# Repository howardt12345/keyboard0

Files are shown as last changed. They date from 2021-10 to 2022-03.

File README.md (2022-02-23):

# [keyboard0 project](https://kb.ht12345.xyz/0)
[][cc-by-nc-sa]

## This project is currently under active development. Everything is subject to change.

### Tenkeyless (TKL) hot-swap mechanical keyboard with macro keys column, 2 rotary encoders, and OLED display

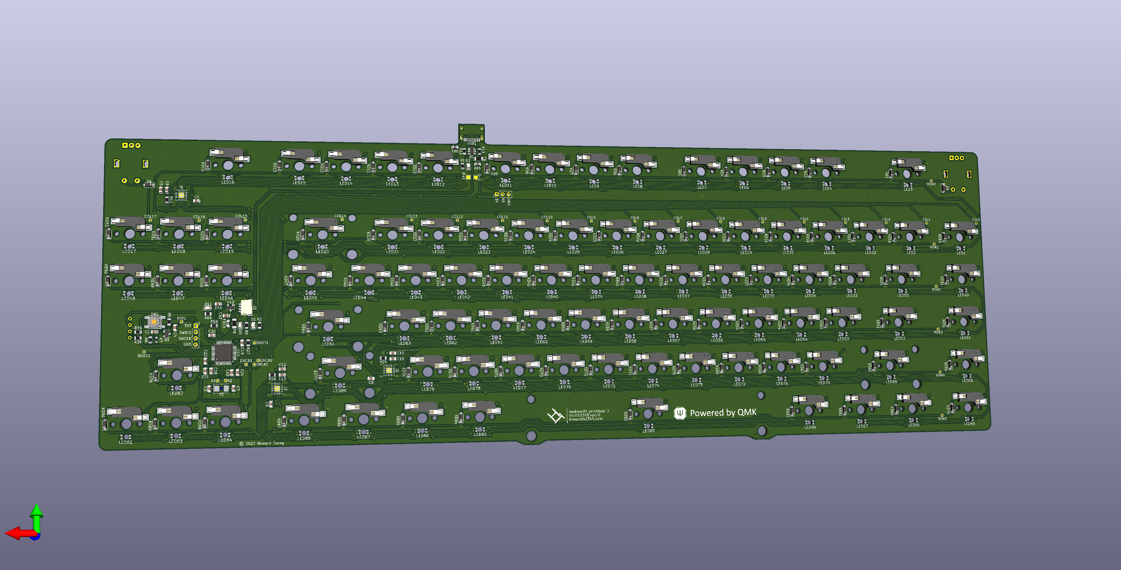
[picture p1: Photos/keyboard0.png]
Render of p2 PCB


The PCB is designed to use Kailh Hot-swap sockets. The original specifications also wanted a USB hub, which will be implemented through a separate USB hub daughterboard. 

---

[The layout on keyboard layout editor](http://www.keyboard-layout-editor.com/#/gists/689bc560553c37fa0d04dfba9f11ed96)

[Prototype 2 PCB photos on @howardt12345](https://www.instagram.com/p/CYXeXJdg_eP/)

[Details on my keyboard website](https://kb.ht12345.xyz/0)

[QMK Fork](https://github.com/howardt12345/qmk_firmware/tree/ht12345/keyboard0/keyboards/ht12345/keyboard0)

---
## All of the files in this repository, including the PCBs, are provided without liability and without any guarantee with regards to functionality. Any production files and prototypes from this project are provided without warranty of any kind.

---

**This work is licensed under a** [Creative Commons Attribution-NonCommercial-ShareAlike 4.0 International License][cc-by-nc-sa].

[][cc-by-nc-sa]

[cc-by-nc-sa]: http://creativecommons.org/licenses/by-nc-sa/4.0/
[cc-by-nc-sa-image]: https://licensebuttons.net/l/by-nc-sa/4.0/88x31.png
[cc-by-nc-sa-shield]: https://img.shields.io/badge/License-CC%20BY--NC--SA%204.0-lightgrey.svg

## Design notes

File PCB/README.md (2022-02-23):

# keyboard0 PCB designs

## Directories: 

- `/p1`: The 1st prototype, ordered prototypes confirmed NOT working.
- `/p2`: The 2nd prototype, which I produced a batch of 2 prototypes and they worked (see respective readme)
- `/p3`: The 3rd prototype, under active development and NOT YET TESTED.
- `/Plate`: FR4 plate designs.

Any KiCad files in *this specific directory* is under active development and is subject to change. 

### These PCB designs are provided without liability and without any guarantee with regards to functionality. While I have personally tested some of the designs, I do not guarantee that they will work if you were to produce them yourself.

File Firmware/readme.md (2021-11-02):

# keyboard0 firmware
keyboard0

A tenkeyless keyboard with 5 additional macro keys, RGB lighting, 2 rotary encoders, and up to 6 additional USB 2.0 ports.
* Keyboard Maintainer: [Howard Tseng](https://github.com/howardt12345)
* Hardware Supported: keyboard0 (STM32F103)
* Hardware Availability: Not available

Make example for this keyboard (after setting up your build environment):

    make keyboard0:default

Flashing example for this keyboard:

    make keyboard0:default:flash

See the [build environment setup](https://docs.qmk.fm/#/getting_started_build_tools) and the [make instructions](https://docs.qmk.fm/#/getting_started_make_guide) for more information. Brand new to QMK? Start with our [Complete Newbs Guide](https://docs.qmk.fm/#/newbs).

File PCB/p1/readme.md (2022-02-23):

# 1st prototype of keyboard0
## This prototype has confirmed to NOT BE WORKING. Do NOT use the files in this directory and subdirectories for production or reference.

`custom_keyboard (f303).pro` is the project that was exported for production. This KiCad project was made using KiCad 5.1.10.

## Known issues:
- Rotary encoders are off centered
- OLED pins are flipped
- Circuit breaker IC was incorrectly wired and as such does not work
- USB hub does not work

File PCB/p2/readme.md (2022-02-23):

# 2nd prototype of keyboard0

I have *personally* confirmed this prototype version to be working. 

`custom_keyboard (f303).pro` is the project that was exported for production. This KiCad project was made using KiCad 5.1.10.

---
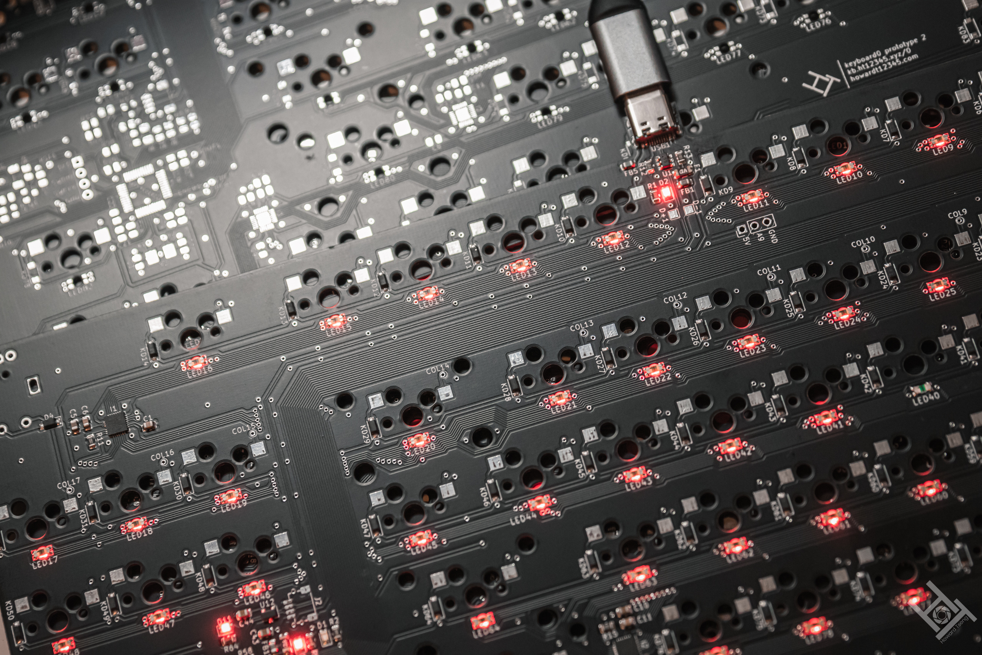
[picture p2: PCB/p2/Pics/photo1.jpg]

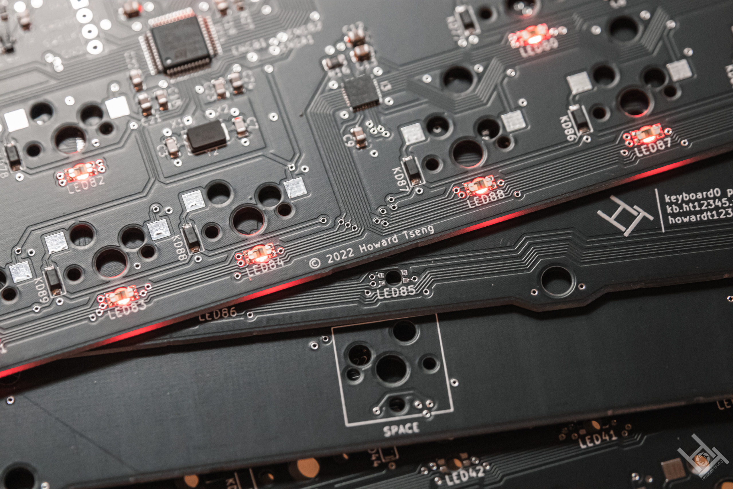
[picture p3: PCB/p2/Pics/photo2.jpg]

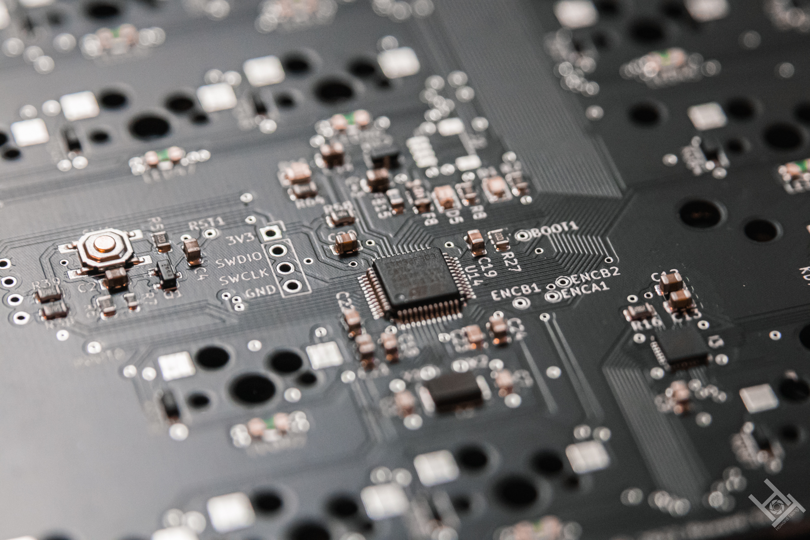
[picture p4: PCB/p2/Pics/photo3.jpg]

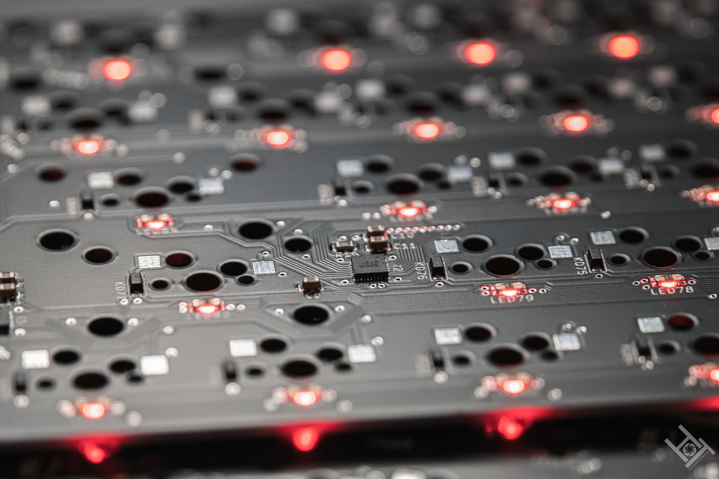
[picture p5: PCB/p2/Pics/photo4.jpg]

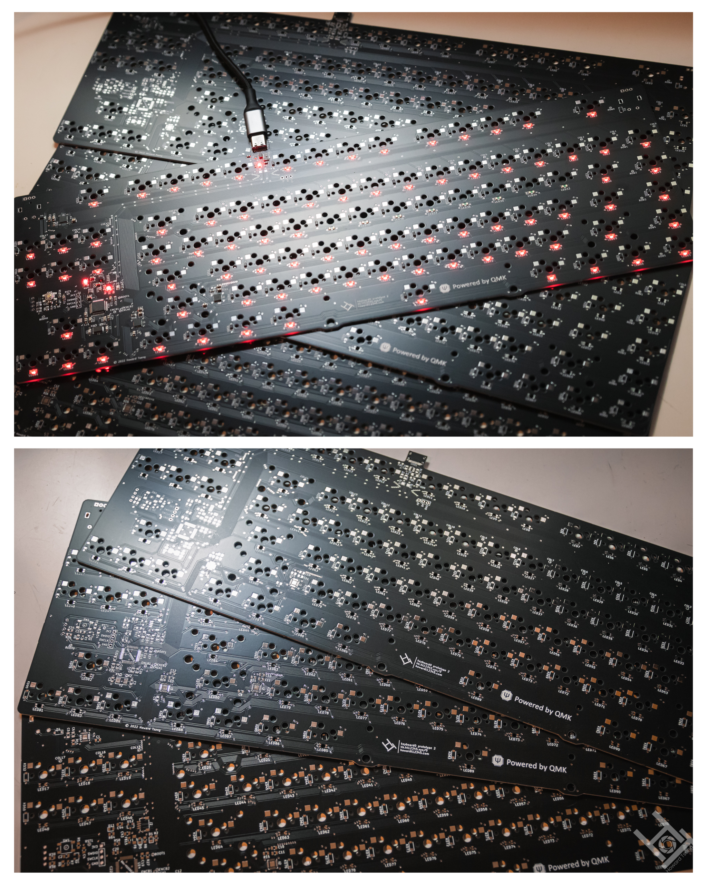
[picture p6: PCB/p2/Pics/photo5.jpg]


---

# Notable flaws:
- The footprint for the MHT151RGBCT RGB LEDs will consistently give a DRC error in Kicad. The current footprint follows the specifications found in the [datasheet](https://datasheet.lcsc.com/lcsc/2104121904_MEIHUA-MHT151RGBCT_C409782.pdf), which creates several points where pads are considered to be too close to other pads. Although there are no noticeable issues with the functionality of the LEDs with my personal prototype units, manufacturing errors have a potential to appear, whether in the PCB production process or the assembly process. 
- Vias are not tented in the given Gerber files. Although intended for debugging purposes, it would not be great in production.
- The IS31FL3731 is not the best LED driver, and the RGB LEDs will flicker after a while on one of the units. Switching to a IS31FL3733 in future versions would be ideal, if it becomes available.
- This prototype has both an integrated USB-C port and provisions for a JST connection for a daughterboard. The integrated USB-C port would ideally be removed in future versions, opting to use only a daughterboard as the USB connection. 
- The spacebar stabilizer is south facing to maintain compatibility with the v1 plate. As such, the bottom of the PCB requires slightly more room to accommodate the stabilizer. The stabilizer orientation would be rotated in future versions.
- The USB lines have test points, which are unnecessary and should be removed.

---

## These files are provided without liability and without any guarantee with regards to functionality. These files are NOT to be used for commercial purposes, as expressed in the [Creative Commons Attribution-NonCommercial-ShareAlike 4.0 International License][cc-by-nc-sa].

[cc-by-nc-sa]: http://creativecommons.org/licenses/by-nc-sa/4.0/

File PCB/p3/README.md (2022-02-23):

# 3rd prototype of keyboard0

Still under active development.

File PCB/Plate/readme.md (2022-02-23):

# keyboard0 plates

The project files for the plate of keyboard0.

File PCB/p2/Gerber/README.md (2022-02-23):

# Gerber files for p2

The BOM and SMT placement file (CPL) are formatted for use with JLCPCB. All the parts can be populated by JLCPCB at the time of writing, however the availability of parts depends on external factors.

## JLCPCB Configuration

If you want to order PCBs from JLC-PCB with the provided gerber-files, use the following settings after uploading the zipped gerber folder:

- Layers: 2
- Dimension: 377.8 mm x 135.7 mm
- PCB Color: Choose what you want
- PCB Thickness: 1.6
- Impedance: no
- Surface Finish: LeadFree HASL-RoHS (although up to you)
- Copper Weight: 1
- Gold Fingers: No
- Material Details: FR4-Standard Tg 130-140C
- Panel By JLCPCB: No
- Flying Probe Test: Fully Test
- Castellated Holes: no
- Different Design: 1
- Remove Order Number: Specify a location

5 PCBs without assembly cost is about $36 CAD.

If you want to have the SMT parts populated, choose "SMT Assembly" and select "Bottom Layer".
When asked for the BOM and CPL file, upload the provided files.

Assembly and parts for 5 PCBs will cost approximately $250 CAD.

### Expected Corrected SMD preview from JLCPCB

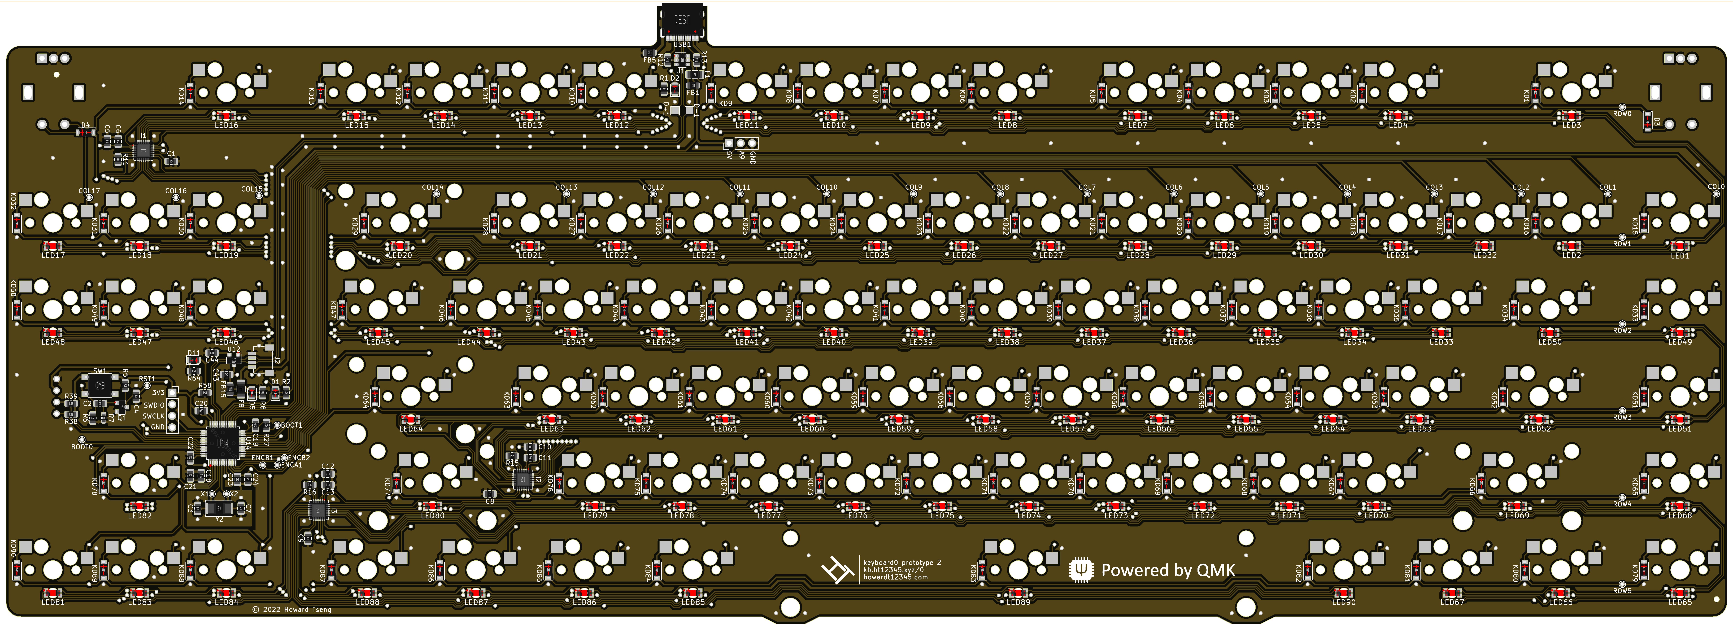
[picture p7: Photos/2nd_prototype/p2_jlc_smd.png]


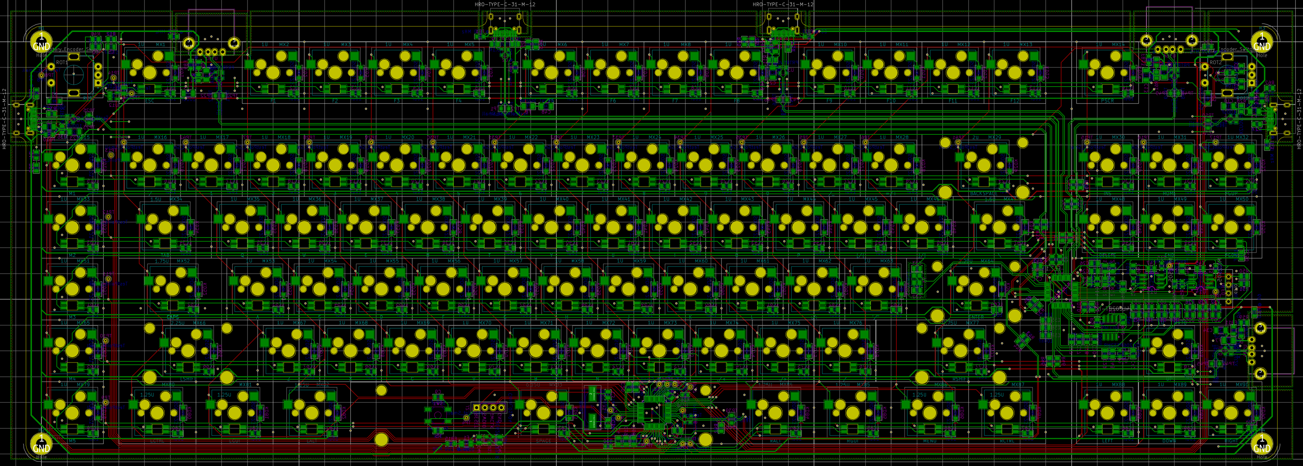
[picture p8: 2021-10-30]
PCB/Gerber/Draft 1-3/Images/2021-10-26/custom_keyboard (f303, fe2.1) bottom traces.png

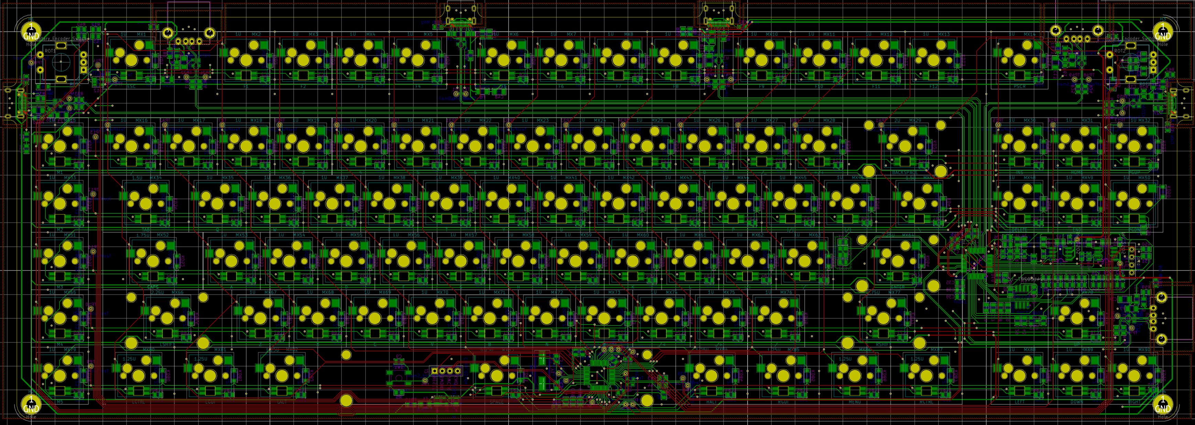
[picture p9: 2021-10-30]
PCB/Gerber/Draft 1-4/Images/2021-10-29/custom_keyboard (f103, fe2.1) top traces.png

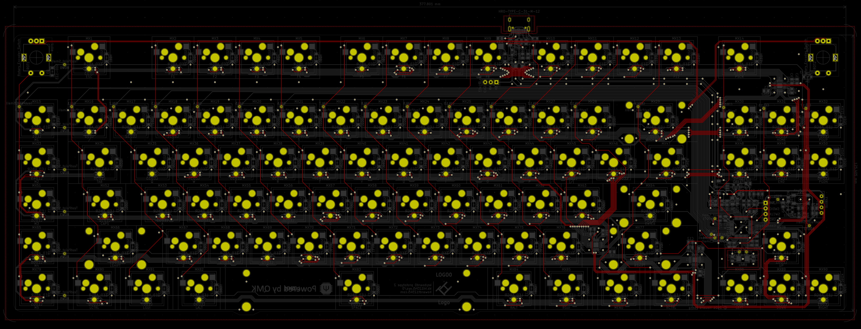
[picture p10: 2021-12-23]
PCB/p2/Pics/custom_keyboard high contrast top.png

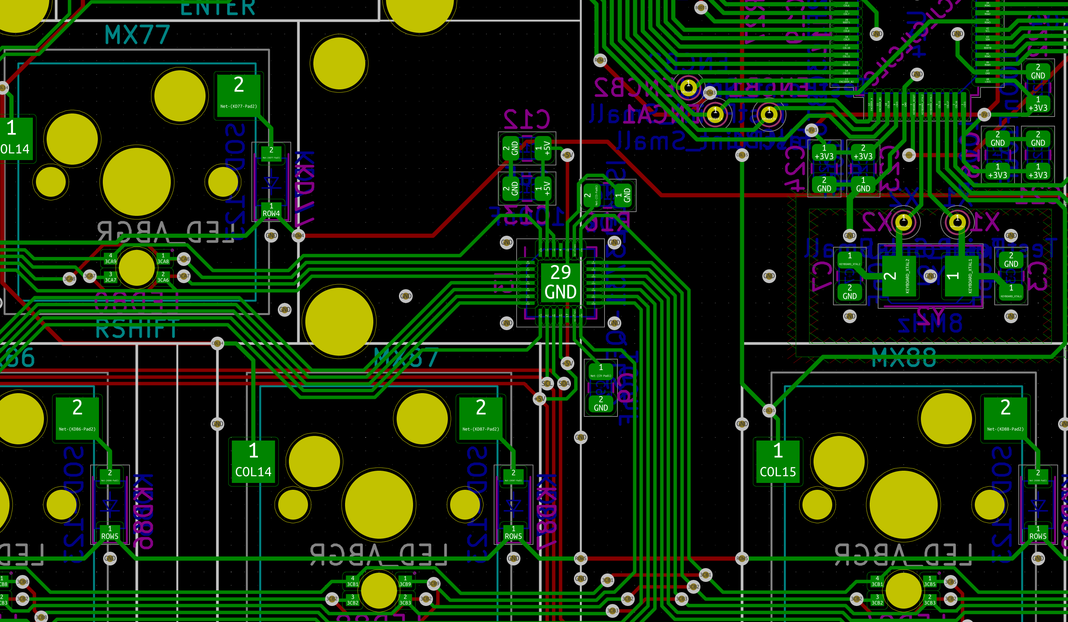
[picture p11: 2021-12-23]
PCB/p2/Pics/custom_keyboard I3.png

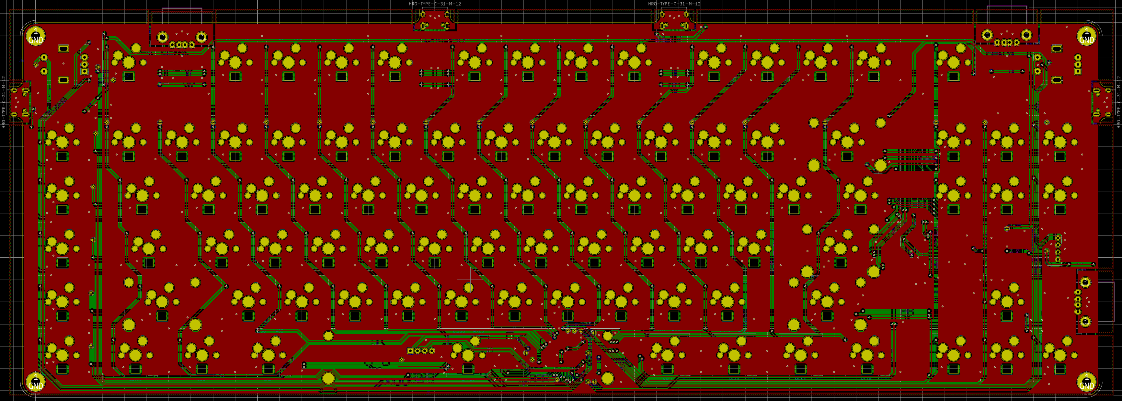
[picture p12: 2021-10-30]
PCB/Gerber/Draft 1-3/Images/2021-10-26/custom_keyboard (f303, fe2.1) top fill.png

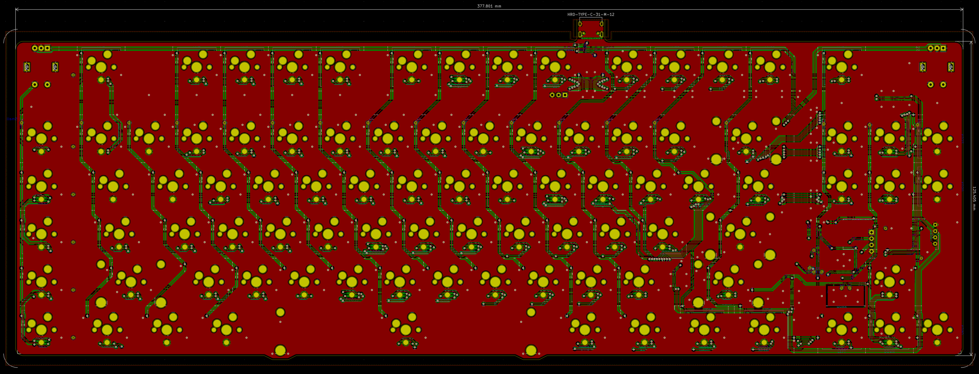
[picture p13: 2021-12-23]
PCB/p2/Pics/custom_keyboard fill top.png

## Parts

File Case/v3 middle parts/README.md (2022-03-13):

# Middle parts of v3 case

The middle parts of the "v3" case. Designed to be used with the [plate v3](../../PCB/Plate/v3) files.

## Renders:

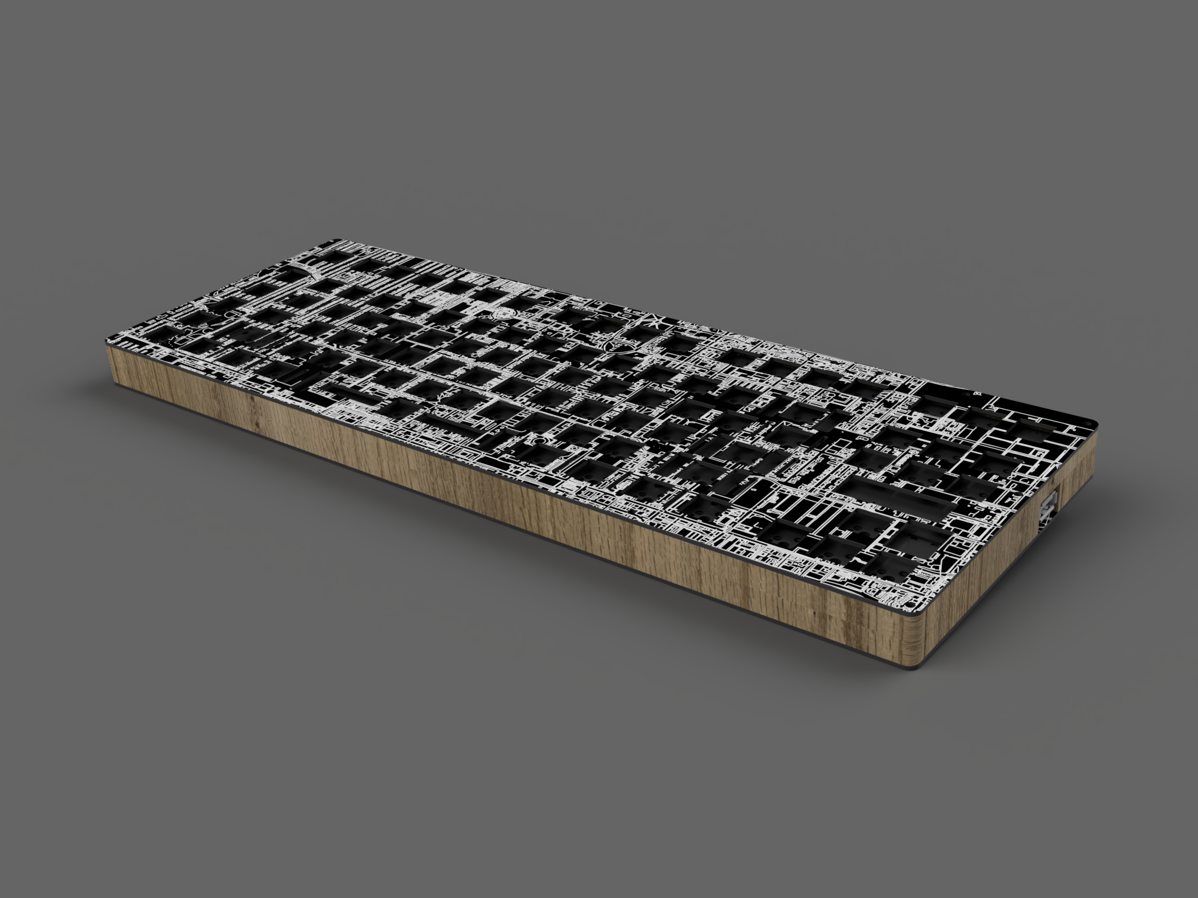
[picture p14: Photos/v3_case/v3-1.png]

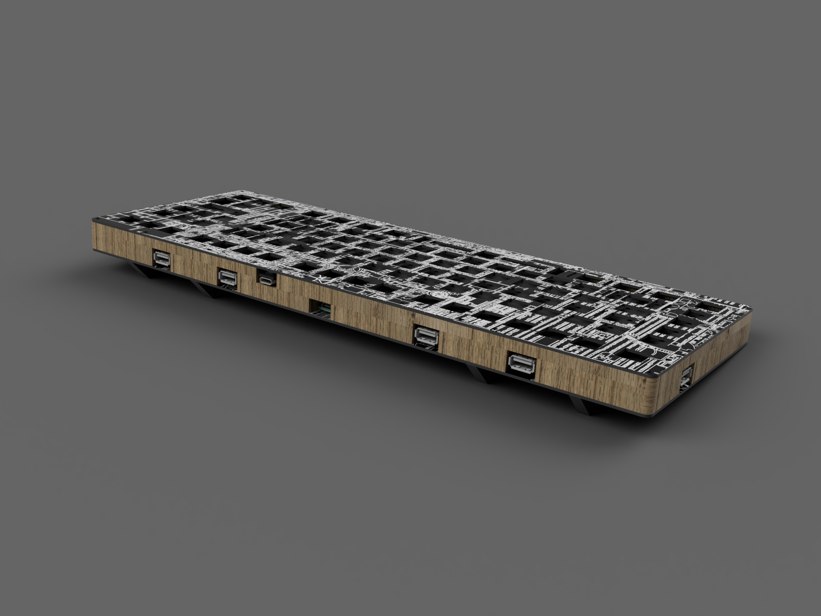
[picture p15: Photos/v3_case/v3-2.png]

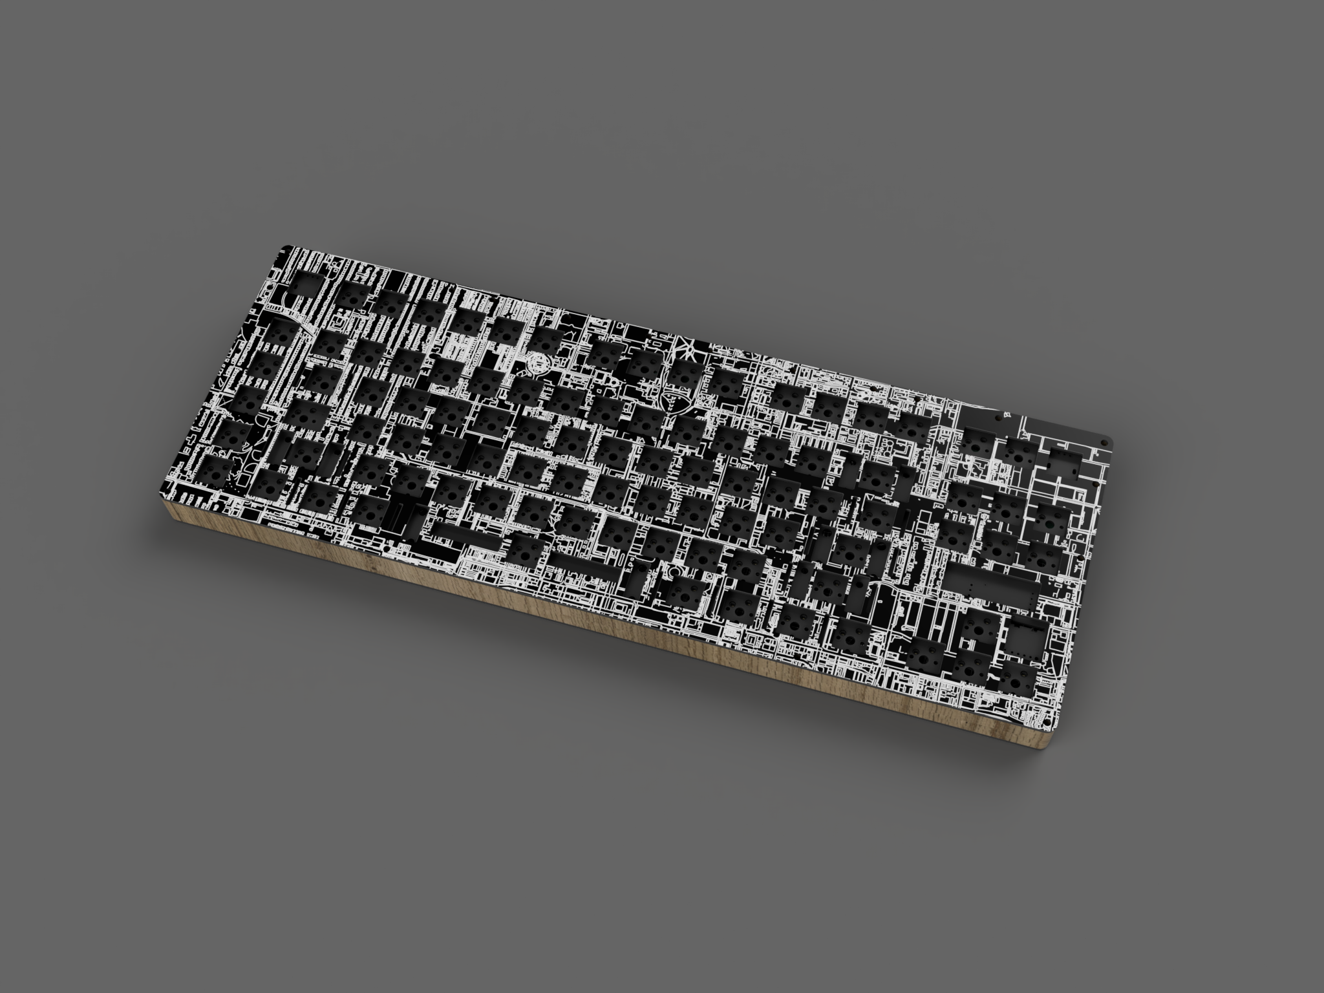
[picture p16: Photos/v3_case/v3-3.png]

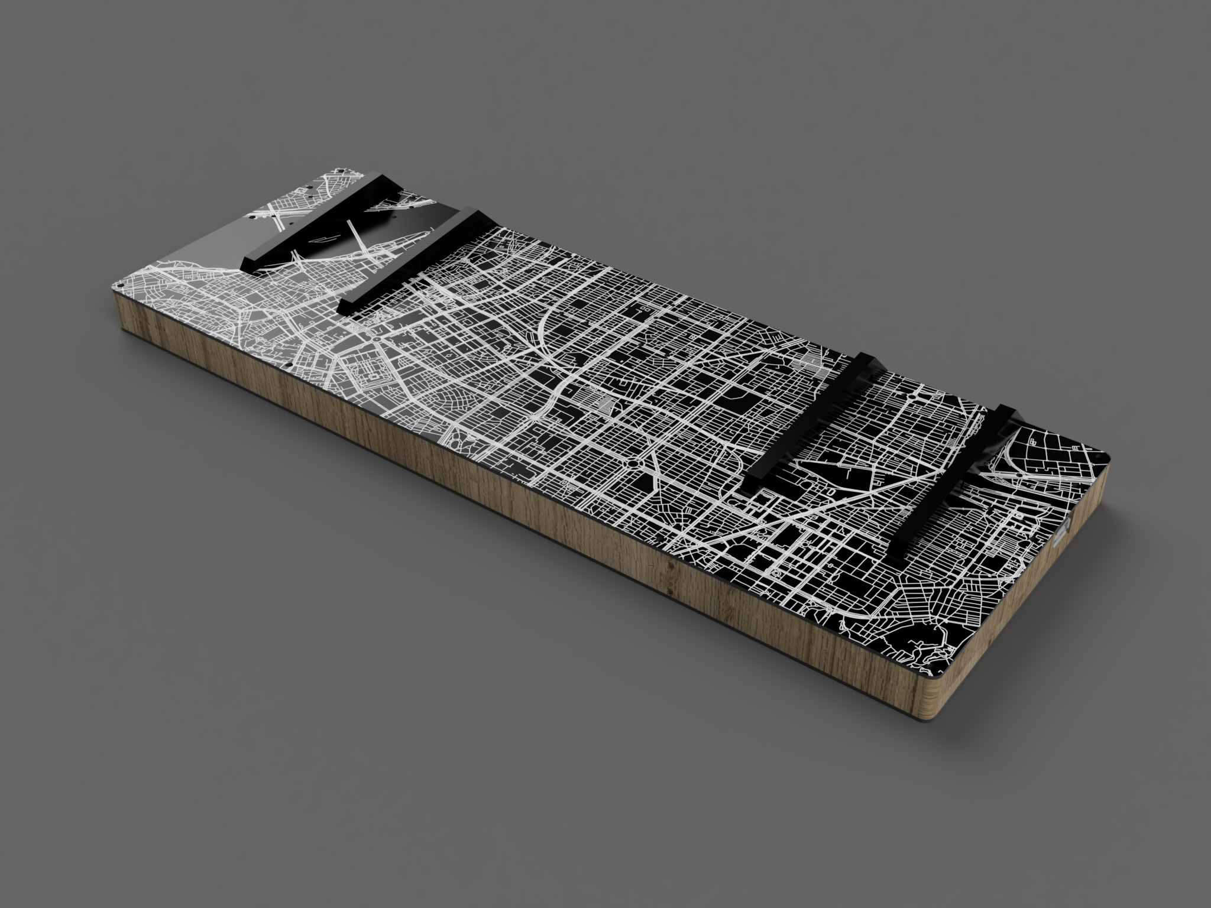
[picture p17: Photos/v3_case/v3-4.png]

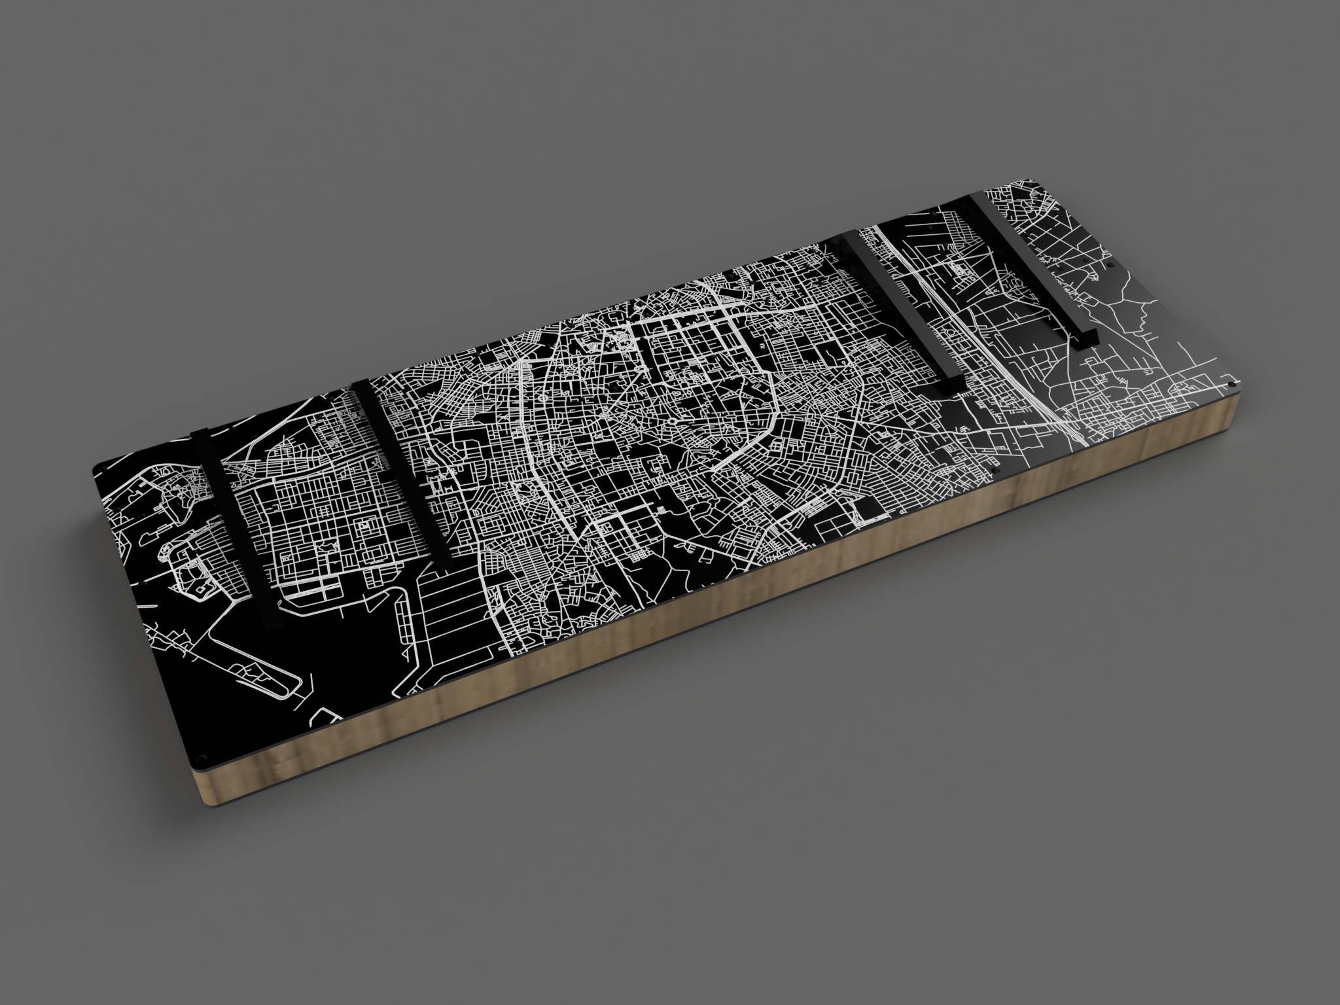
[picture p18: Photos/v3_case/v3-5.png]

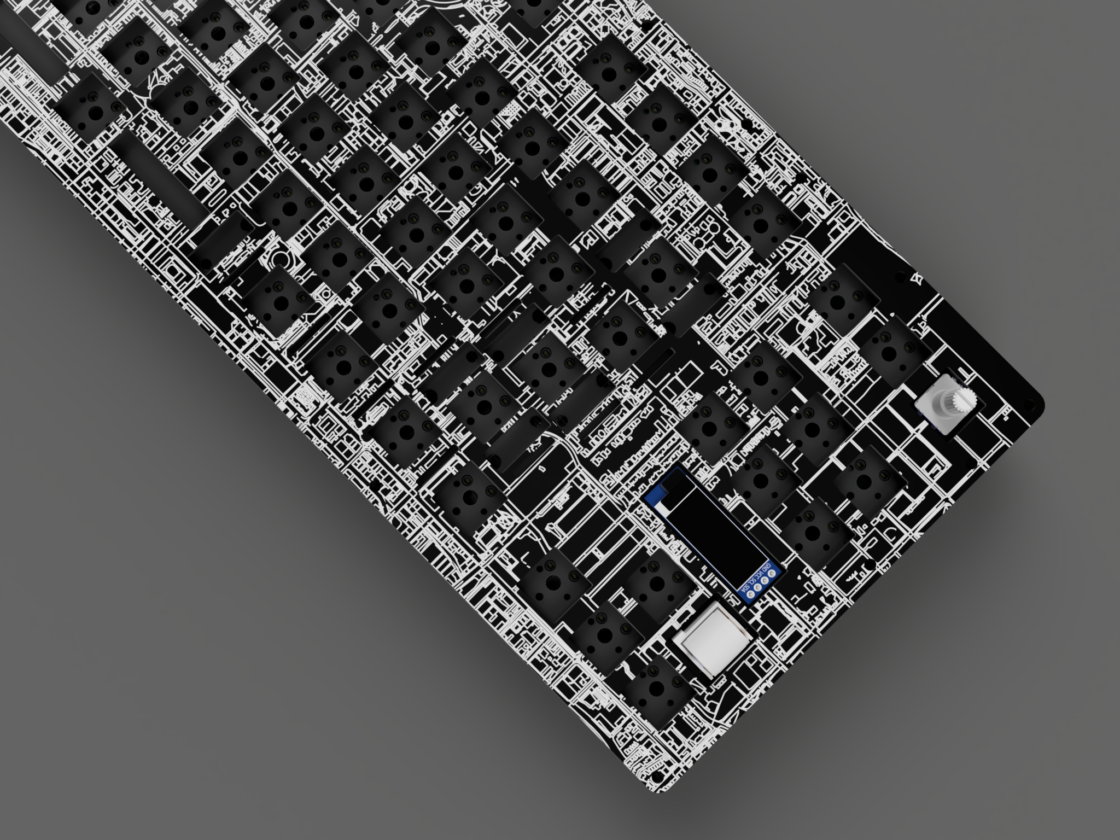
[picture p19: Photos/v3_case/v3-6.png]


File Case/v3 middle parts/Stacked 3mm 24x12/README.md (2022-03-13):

# Stacked case files

These files are for the stacked case variant.
- `Layers 1-4 combined.dxf` and `Layers 5-6 combined.dxf` are both designed to fit on a 3mm 24" x 12" sheet of material of your choice (preferably acrylic). These 2 files contain everything needed for the 6 layers, combined with shared edges between the different parts.
- `Layers 1-3.dxf`, `Layer 4.dxf`, and `Layers 5-6.dxf` are for the individual layers. 
  - `Layers 1-3.dxf` should be produced with 9mm worth of material. Thickness variance within ±1mm is allowed.
  - `Layer 4.dxf` should be produced with 3mm worth of material.
  - `Layers 5-6.dxf` should be produced with 6mm worth of material. No variance in thickness is allowed.

## Diagram

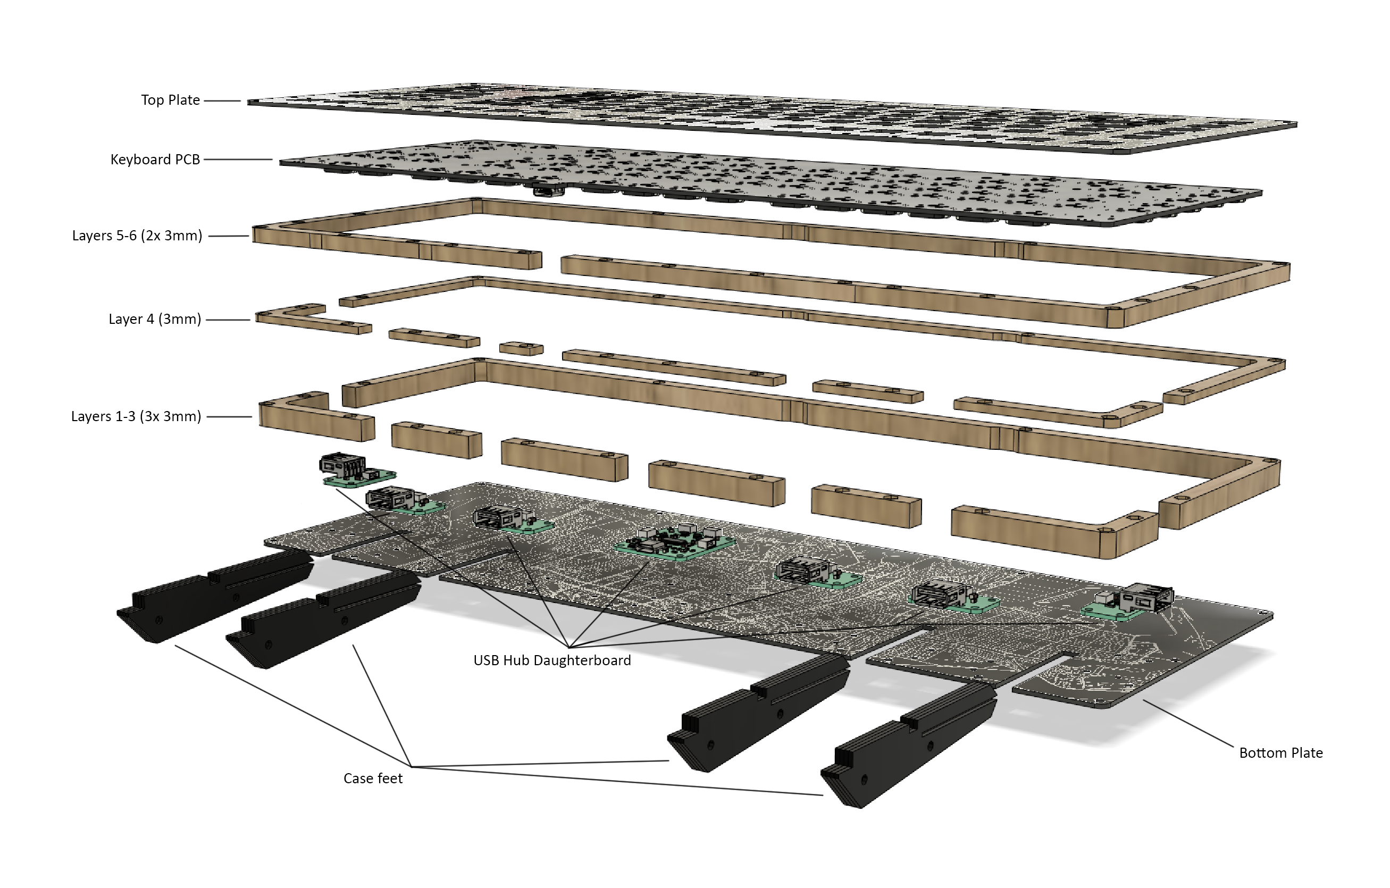
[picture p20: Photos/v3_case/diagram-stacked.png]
diagram-stacked


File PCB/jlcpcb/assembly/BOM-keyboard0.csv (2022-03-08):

Comment | Designator | Footprint | LCSC
STM32F303CBT6 | U14 | LQFP-48_7x7mm_P0.5mm | C81523
8MHz | Y2 | Crystal_SMD_5032-2Pin_5.0x3.2mm | C115962
10uF | C21 | C_0805_2012Metric | C15850
SM04B-SRSS-TB(LF)(SN) | J2 | JST-SR-4 | C160404
TYPE-C-31-M-12 | USB1 | USB_C_Receptacle_HRO_TYPE-C-31-M-12 | C165948
10nF | C23 | C_0805_2012Metric | C1710
10k | R27,R5,R6 | R_0805_2012Metric | C17414
4.7k | R38,R39 | R_0805_2012Metric | C17673
510 | R2,R64 | R_0805_2012Metric | C17734
4.7uF | C2 | C_0805_2012Metric | C1779
680 | R1,R8 | R_0805_2012Metric | C17798
20pF | C3,C7 | C_0805_2012Metric | C1798
60 @ 100 MHz | FB1,FB15,FB5 | L_0805_2012Metric | C18305
IS31FL3731-QFLS2 | I1,I2,I3 | QFN-28-1EP_4x4mm_P0.4mm_EP2.3x2.3mm | C191206
Green | D1 | LED_0805_2012Metric | C2296
100k | R7 | R_0603_1608Metric | C25803
5.1K | R12,R13 | R_0805_2012Metric | C27834
100nF | C1,C11,C13,C18,C19,C20,C22,C6,C8,C9 | C_0805_2012Metric | C28233
1uF | C10,C12,C24,C4,C43,C44,C5 | C_0805_2012Metric | C28323
SW_Push | SW1 | SKQG-1155865 | C318884
LED_ABGR | LED1,LED10,LED11,LED12,LED13,LED14,LED15,LED16,LED17,LED18,LED19,LED2,LED20,LED21,LED22,LED23,LED24,LED25,LED26,LED27,LED28,LED29,LED3,LED30,LED31,LED32,LED33,LED34,LED35,LED36,LED37,LED38,LED39,LED4,LED40,LED41,LED42,LED43,LED44,LED45,LED46,LED47,LED48,LED49,LED5,LED50,LED51,LED52,LED53,LED54,LED55,LED56,LED57,LED58,LED59,LED6,LED60,LED61,LED62,LED63,LED64,LED65,LED66,LED67,LED68,LED69,LED7,LED70,LED71,LED72,LED73,LED74,LED75,LED76,LED77,LED78,LED79,LED8,LED80,LED81,LED82,LED83,LED84,LED85,LED86,LED87,LED88,LED89,LED9,LED90 | MHT151RGBCT_with_outline | C409782
1.5k | R58 | R_0805_2012Metric | C4310
20k | R11,R15,R16 | R_0805_2012Metric | C4328
XC6206P332MR | U12 | SOT-23 | C5446
500mA | F1,F8 | Fuse_1206_3216Metric | C70069
SOD-123 | D3,D4,D6,KD1,KD1-1,KD10,KD11,KD12,KD13,KD14,KD14-1,KD15,KD16,KD17,KD18,KD19,KD2,KD20,KD21,KD22,KD23,KD24,KD25,KD26,KD27,KD28,KD29,KD3,KD30,KD31,KD32,KD33,KD34,KD35,KD36,KD37,KD38,KD39,KD4,KD40,KD41,KD42,KD43,KD44,KD45,KD46,KD47,KD48,KD49,KD5,KD50,KD51,KD52,KD53,KD54,KD55,KD56,KD57,KD58,KD59,KD6,KD60,KD61,KD62,KD63,KD64,KD65,KD66,KD67,KD68,KD69,KD7,KD70,KD71,KD72,KD73,KD74,KD75,KD76,KD77,KD78,KD79,KD8,KD80,KD81,KD82,KD83,KD84,KD85,KD86,KD87,KD88,KD89,KD9,KD90 | D_SOD-123 | C81598
Red | D11,D2,D5 | LED_0805_2012Metric | C84256
SRV05-4 | U1,U2 | SOT-23-6_Handsoldering | C85364
2N7002 | Q1 | SOT-23 | C8545

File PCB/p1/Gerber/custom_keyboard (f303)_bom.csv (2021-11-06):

Comment | Designator | Footprint | LCSC Part #
100uF Unpolarized capacitor, small symbol | C1,C4,C6,C12,C17,C25,C30 | C_1206_3216Metric | C15008
22pF Unpolarized capacitor, small symbol | C2,C5 | C_0805_2012Metric | C1804
20pF Unpolarized capacitor, small symbol | C3,C7 | C_0805_2012Metric | C1798
100nF Unpolarized capacitor, small symbol | C8,C9,C10,C11,C13,C14,C16,C18,C19,C20,C22,C26,C27,C28,C29,C31,C32,C33,C34,C35,C38,C39,C40,C41,C42 | C_0805_2012Metric | C49678
4.7uF Unpolarized capacitor, small symbol | C15 | C_0805_2012Metric | C1779
10uF Unpolarized capacitor, small symbol | C21,C36,C37 | C_0805_2012Metric | C15850
10nF Unpolarized capacitor, small symbol | C23 | C_0805_2012Metric | C1710
1uF Unpolarized capacitor, small symbol | C24,C43,C44 | C_0805_2012Metric | C28323
Red Light emitting diode, small symbol | D1,D2,D5,D6,D7,D8,D9,D10,D11,D12 | LED_0805_2012Metric | C84256
SOD-123 Diode, small symbol | D3,D4 | D_SOD-123 | C81598
500mA Resettable fuse, polymeric positive temperature coefficient, small symbol | F1,F2,F3,F4,F5,F6,F7,F8 | Fuse_1206_3216Metric | C70069
60 @ 100 MHz Ferrite bead, small symbol | FB1,FB2,FB3,FB4,FB5,FB6,FB7,FB8,FB9,FB10,FB11,FB12,FB13,FB14,FB15 | L_0805_2012Metric | C237300
FE2.1 | FE2.1 | FE2.1 | C39693
SOD-123 Diode, small symbol | KD1,KD2,KD3,KD4,KD5,KD6,KD7,KD8,KD9,KD10,KD11,KD12,KD13,KD14,KD15,KD16,KD17,KD18,KD19,KD20,KD21,KD22,KD23,KD24,KD25,KD26,KD27,KD28,KD29,KD30,KD31,KD32,KD33,KD34,KD35,KD36,KD37,KD38,KD39,KD40,KD41,KD42,KD43,KD44,KD45,KD46,KD47,KD48,KD49,KD50,KD51,KD52,KD53,KD54,KD55,KD56,KD57,KD58,KD59,KD60,KD61,KD62,KD63,KD64,KD65,KD66,KD67,KD68,KD69,KD70,KD71,KD72,KD73,KD74,KD75,KD76,KD77,KD78,KD79,KD80,KD81,KD82,KD83,KD84,KD85,KD86,KD87,KD88,KD89,KD90 | D_SOD-123 | C81598
10uF Unpolarized capacitor, small symbol | LC1,LC2,LC3,LC4,LC5,LC6,LC7,LC8,LC9,LC10,LC11,LC12,LC13,LC14,LC15,LC16,LC17,LC18,LC19,LC20,LC21,LC22,LC23,LC24,LC25,LC26,LC27,LC28,LC29,LC30,LC31,LC32,LC33,LC34,LC35,LC36,LC37,LC38,LC39,LC40,LC41,LC42,LC43,LC44,LC45,LC46,LC47,LC48,LC49,LC50,LC51,LC52,LC53,LC54,LC55,LC56,LC57,LC58,LC59,LC60,LC61,LC62,LC63,LC64,LC65,LC66,LC67,LC68,LC69,LC70,LC71,LC72,LC73,LC74,LC75,LC76,LC77,LC78,LC79,LC80,LC81,LC82,LC83,LC84,LC85,LC86,LC87,LC88,LC89,LC90 | C_0805_2012Metric | C15850
470 Resistor, small symbol | R1 | R_0805_2012Metric | C17710
330 Resistor, small symbol | R2,R8,R10,R24,R28,R30,R37,R44,R45,R46,R47,R48,R49,R54,R59,R63,R64,R65 | R_0805_2012Metric | C17630
22 Resistor, small symbol | R3,R4,R5,R6,R9,R11,R23,R26,R34,R35,R40,R41,R42,R43,R52,R53 | R_0805_2012Metric | C17561
56K Resistor, small symbol | R7,R14,R33,R36,R50,R56 | R_0805_2012Metric | C17756
5.1K Resistor, small symbol | R12,R13 | R_0805_2012Metric | C27834
10k Resistor, small symbol | R15,R16,R17,R18,R20,R21,R22,R25,R27,R38,R39 | R_0805_2012Metric | C17414
1k Resistor, small symbol | R19 | R_0805_2012Metric | C17513
100k Resistor, small symbol | R29,R32,R57,R60,R62 | R_0603_1608Metric | C25803
47k Resistor, small symbol | R31 | R_0805_2012Metric | C17713
2.7k Resistor, small symbol | R51 | R_0805_2012Metric | C17530
1.5k Resistor, small symbol | R58 | R_0805_2012Metric | C4310
SW_Push Push button switch, generic, two pins | SW1,SW2 | SKQG-1155865 | C318884
SD00HA Current limited 3A power switch, single channel, SOT-23-5 | U1 | SOT-23-5 | C521425
PRTR5V0U2X | U2,U3,U4,U6,U7,U8,U10 | SOT143B | C2827688
24LC04BT-I/SN I2C Serial EEPROM, 2Kb, DIP-8/SOIC-8/TSSOP-8/DFN-8 | U5 | 24LC04 | C511263
MIC2505-1YM | U9,U11 | MIC2505 | C219158
XC6206P332MR Positive 60-250mA Low Dropout Regulator, Fixed Output, SOT-23 | U12 | SOT-23 | C5446
74LVC1G34 Single Buffef Gate, Low-Voltage CMOS | U13 | SOT-23-5 | C526347
STM32F303CBT6 ARM Cortex-M4 MCU, 128KB flash, 32KB RAM, 72MHz, 2-3.6V, 37 GPIO, LQFP-48 | U14 | LQFP-48_7x7mm_P0.5mm | C108516
Green Light emitting diode, small symbol | UD1,UD2,UD3,UD4,UD5,UD6,UD7 | LED_0805_2012Metric | C2297
Amber Light emitting diode, small symbol | UD8,UD9,UD10,UD11,UD12,UD13,UD14 | LED_0805_2012Metric | C2296
HRO-TYPE-C-31-M-12 | USB1,USB2,USB5,USB7 | HRO-TYPE-C-31-M-12-Assembly | C165948
12MHz Four pin crystal, GND on pins 2 and 4, small symbol | Y1 | Crystal_SMD_3225-4Pin_3.2x2.5mm | C9002
8MHz Two pin crystal, small symbol | Y2 | Crystal_SMD_HC49-SD | C12674

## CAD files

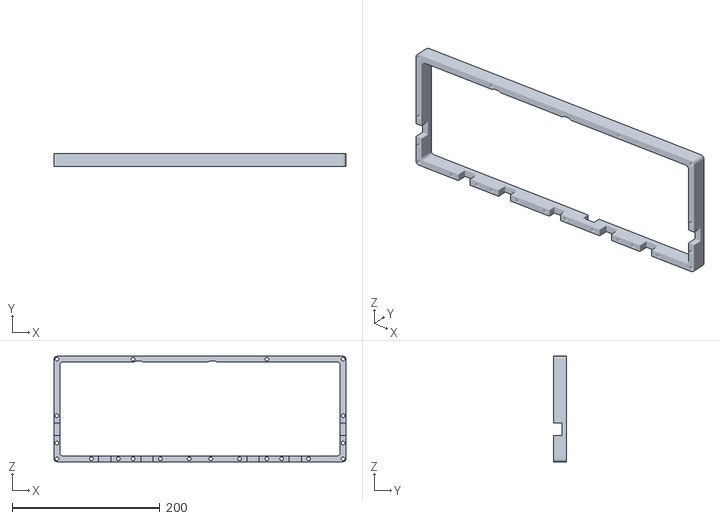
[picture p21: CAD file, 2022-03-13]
Case/v3 middle parts/3d print/Middle parts.stl
395.3 x 18.0 x 142.9

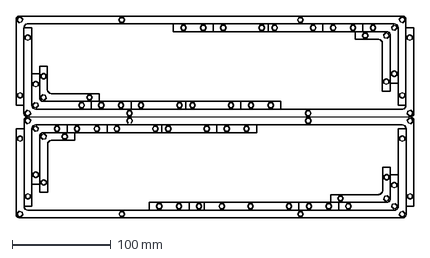
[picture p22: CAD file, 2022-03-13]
Case/v3 middle parts/Stacked 3mm 24x12/Layers 1-4 combined.dxf
403.3 x 204.8 mm

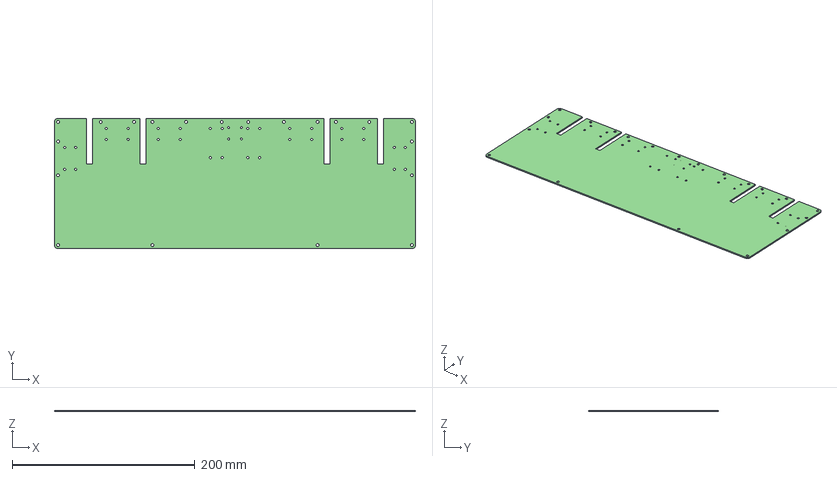
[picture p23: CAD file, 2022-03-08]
PCB/Plate/v3/custom_keyboard plate v3 bottom - map.step
395.3 x 142.9 x 1.60 mm

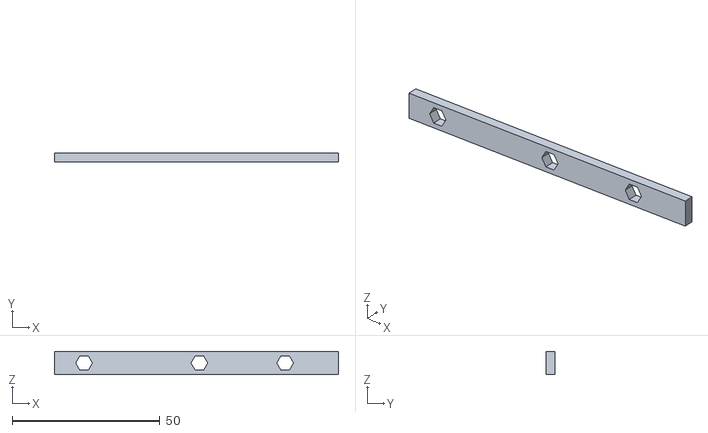
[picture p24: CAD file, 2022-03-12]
Case/v3 middle parts/3d print/Layer 4 4.stl
96.0 x 3.00 x 7.94

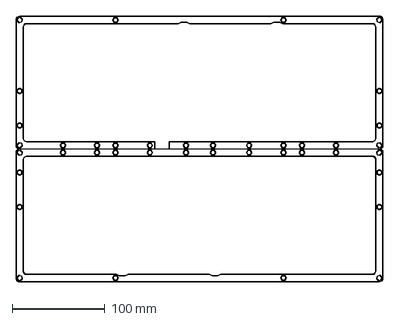
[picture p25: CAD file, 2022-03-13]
Case/v3 middle parts/Stacked 3mm 24x12/Layers 5-6 combined.dxf
395.3 x 285.7 mm

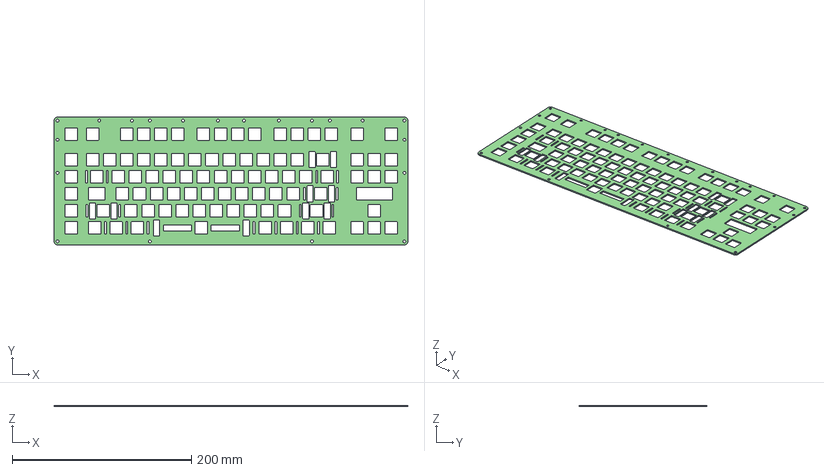
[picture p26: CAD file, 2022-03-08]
PCB/Plate/v3/custom_keyboard plate v3.step
395.3 x 142.9 x 1.60 mm

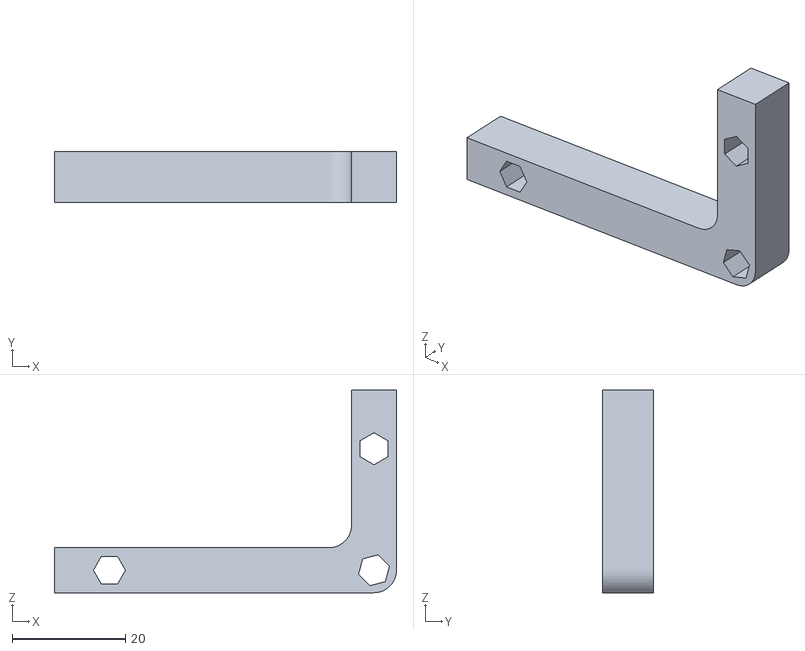
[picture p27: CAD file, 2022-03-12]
Case/v3 middle parts/3d print/Layer 1-3 5.stl
60.3 x 9.00 x 35.7

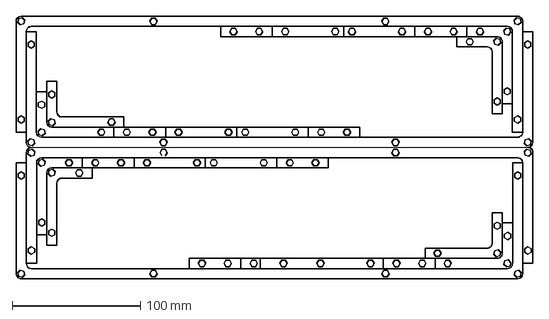
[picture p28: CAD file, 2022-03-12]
Case/v3 middle parts/Stacked 3mm 24x12/Layers 1-4.dxf
403.3 x 204.8 mm

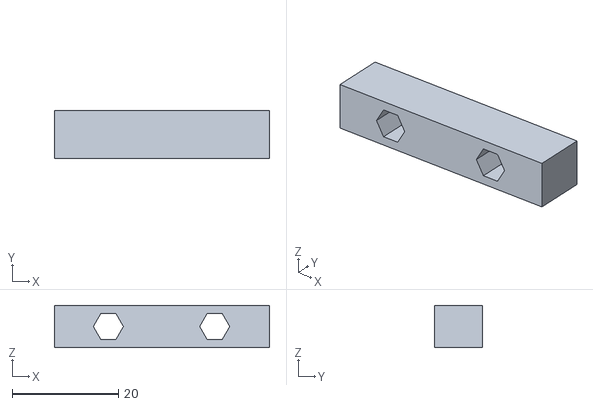
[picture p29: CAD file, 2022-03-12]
Case/v3 middle parts/3d print/Layer 1-3 1.stl
40.5 x 9.00 x 7.94

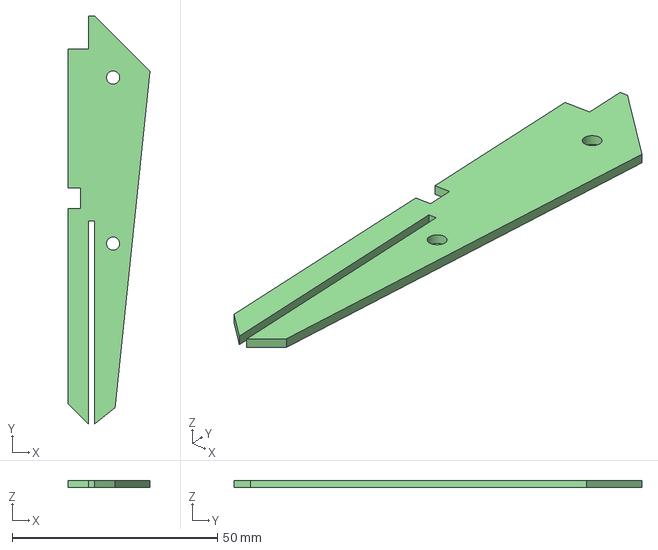
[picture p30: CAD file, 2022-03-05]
PCB/Plate/v3/custom_keyboard plate v3 foot.step
20.0 x 99.5 x 1.60 mm

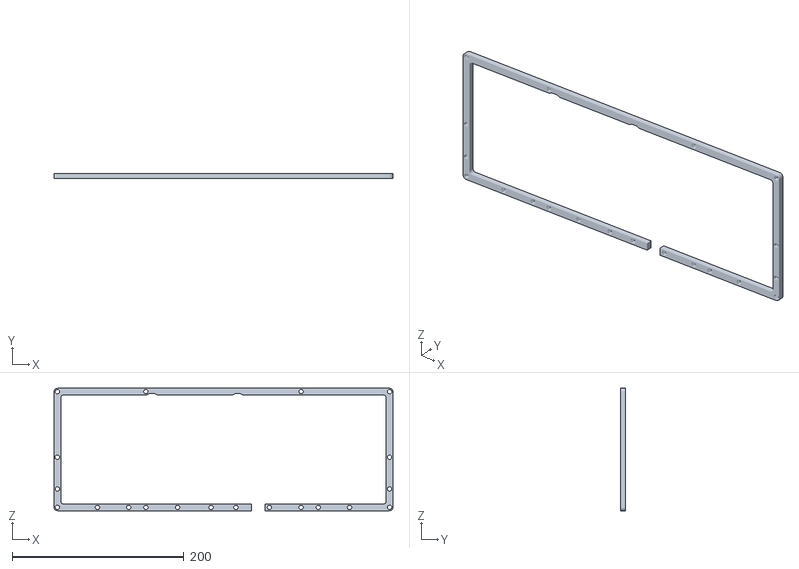
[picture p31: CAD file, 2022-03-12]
Case/v3 middle parts/3d print/Layer 5-6.stl
395.3 x 6.00 x 142.9

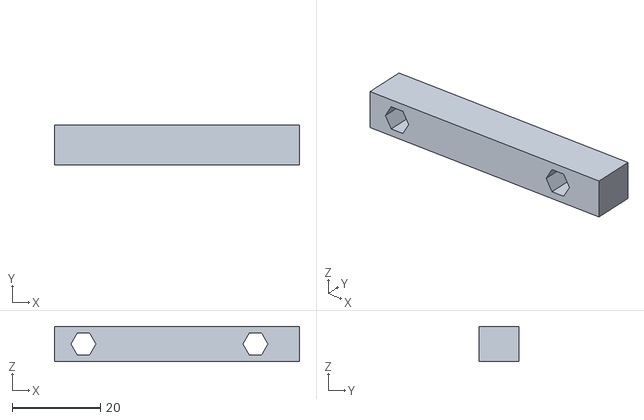
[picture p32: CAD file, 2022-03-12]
Case/v3 middle parts/3d print/Layer 1-3 3.stl
55.6 x 9.00 x 7.94

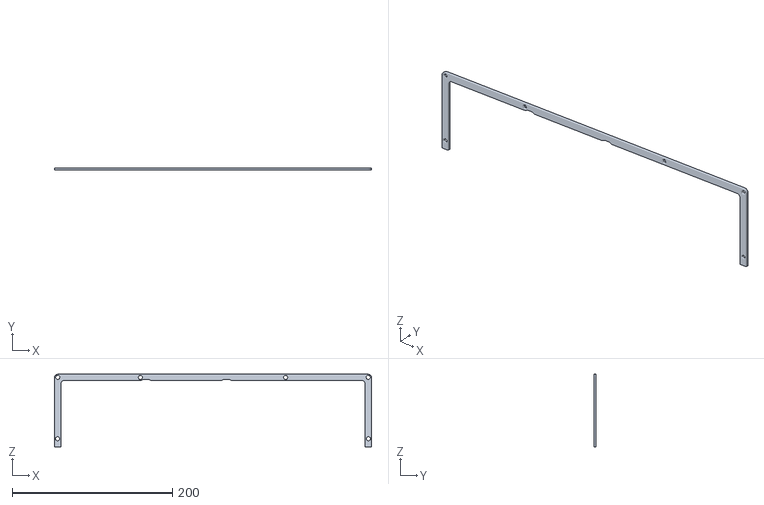
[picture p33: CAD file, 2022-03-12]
Case/v3 middle parts/3d print/Layer 4 5.stl
395.3 x 3.00 x 90.5

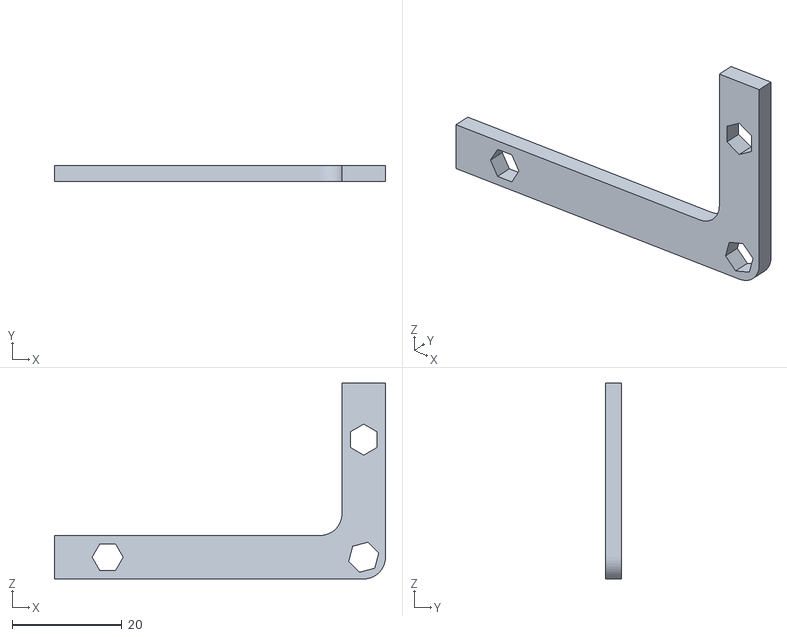
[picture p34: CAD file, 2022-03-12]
Case/v3 middle parts/3d print/Layer 4 6.stl
60.3 x 3.00 x 35.7

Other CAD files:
PCB/Plate/v3/custom_keyboard plate v3 bottom.step
Case/v3 middle parts/3d print/Layer 4 1.stl
Case/v3 middle parts/3d print/Layer 4 3.stl
Case/v3 middle parts/3d print/Layer 1-3 4.stl
Case/v3 middle parts/3d print/Layer 1-3 2.stl
Case/v3 middle parts/3d print/Layer 1-3 6.stl
Case/v3 middle parts/3d print/Layer 1-3 7.stl
Case/v3 middle parts/3d print/Layer 4 2.stl
Case/v3 middle parts/3d print/Layer 4 7.stl
PCB/Plate/Gerber/Plate v2/DXF/custom_keyboard plate v2-B_Cu.dxf
PCB/Plate/Gerber/Plate v2/DXF/custom_keyboard plate v2-B_Mask.dxf
PCB/Plate/Gerber/Plate v2/DXF/custom_keyboard plate v2-B_Paste.dxf
PCB/Plate/Gerber/Plate v2/DXF/custom_keyboard plate v2-B_SilkS.dxf
PCB/Plate/Gerber/Plate v2/DXF/custom_keyboard plate v2-Edge_Cuts.dxf
PCB/Plate/Gerber/Plate v2/DXF/custom_keyboard plate v2-F_Cu.dxf
PCB/Plate/Gerber/Plate v2/DXF/custom_keyboard plate v2-F_Mask.dxf
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

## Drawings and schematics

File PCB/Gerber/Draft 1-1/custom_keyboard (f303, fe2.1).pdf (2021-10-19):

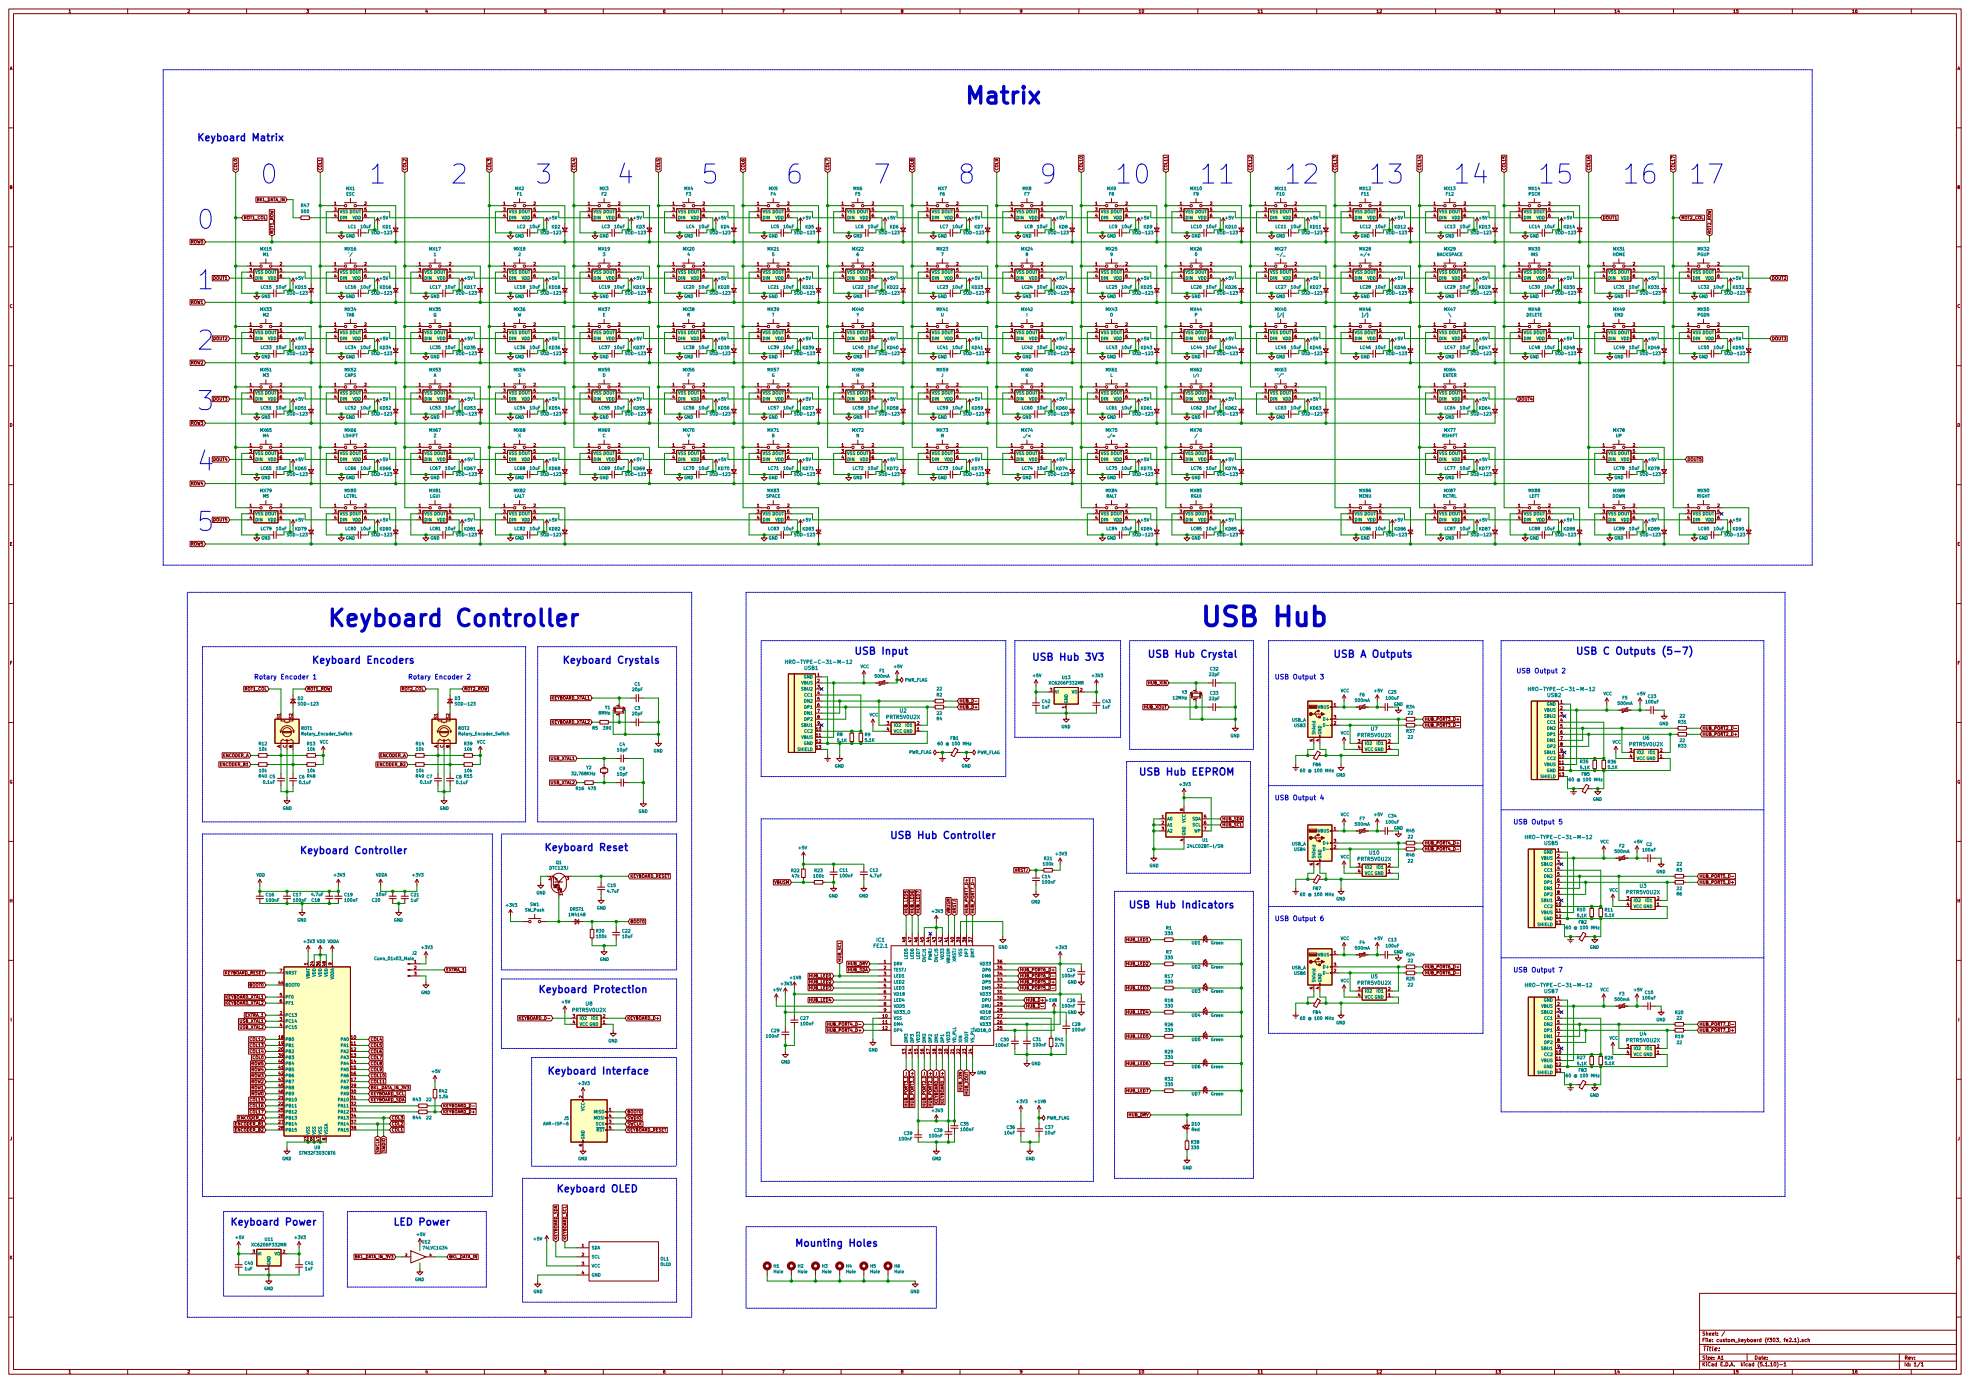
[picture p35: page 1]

22 GND 1 VBUS 2 SBU2 3 CC1 4 DN2 5 DP1 6 DN1 7 DP2 8 SBU1 9 CC2 10 VBUS 11 GND 12 SHIELD 13 USB1

1 VDD 24 VDD 36 VDD 48 VDDA

9 VSS 23 VSS 35 VSS 47 VSSA

2 SCK 3 MOSI 4 RST 5 GND

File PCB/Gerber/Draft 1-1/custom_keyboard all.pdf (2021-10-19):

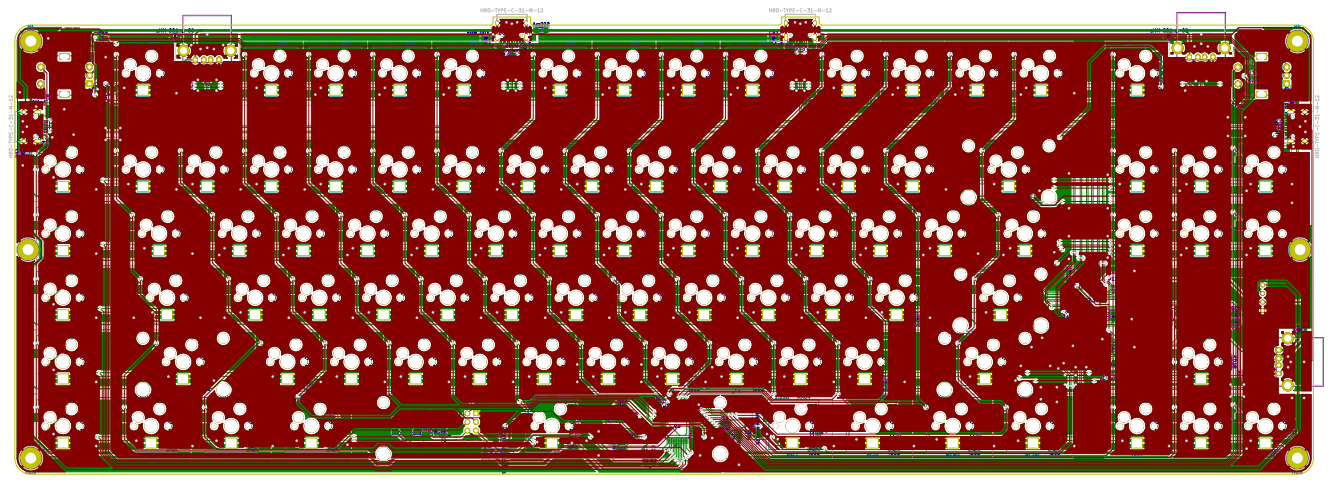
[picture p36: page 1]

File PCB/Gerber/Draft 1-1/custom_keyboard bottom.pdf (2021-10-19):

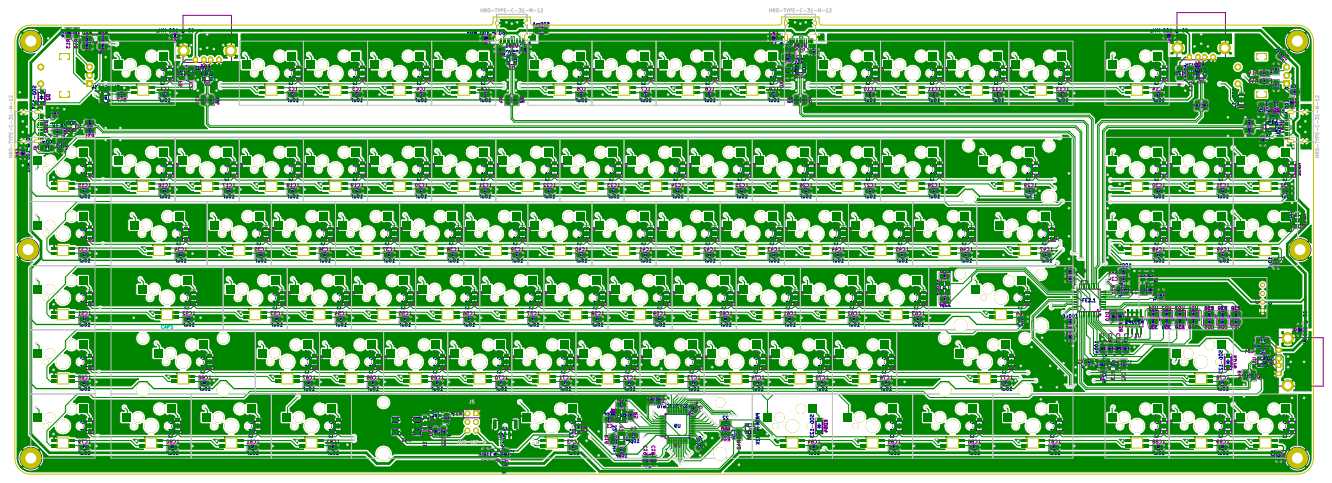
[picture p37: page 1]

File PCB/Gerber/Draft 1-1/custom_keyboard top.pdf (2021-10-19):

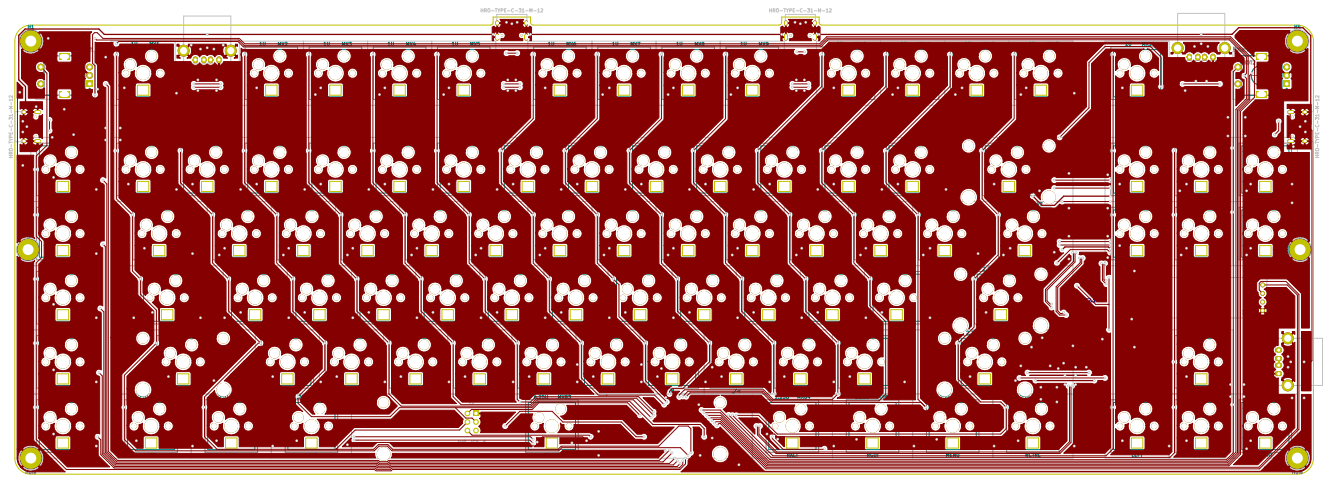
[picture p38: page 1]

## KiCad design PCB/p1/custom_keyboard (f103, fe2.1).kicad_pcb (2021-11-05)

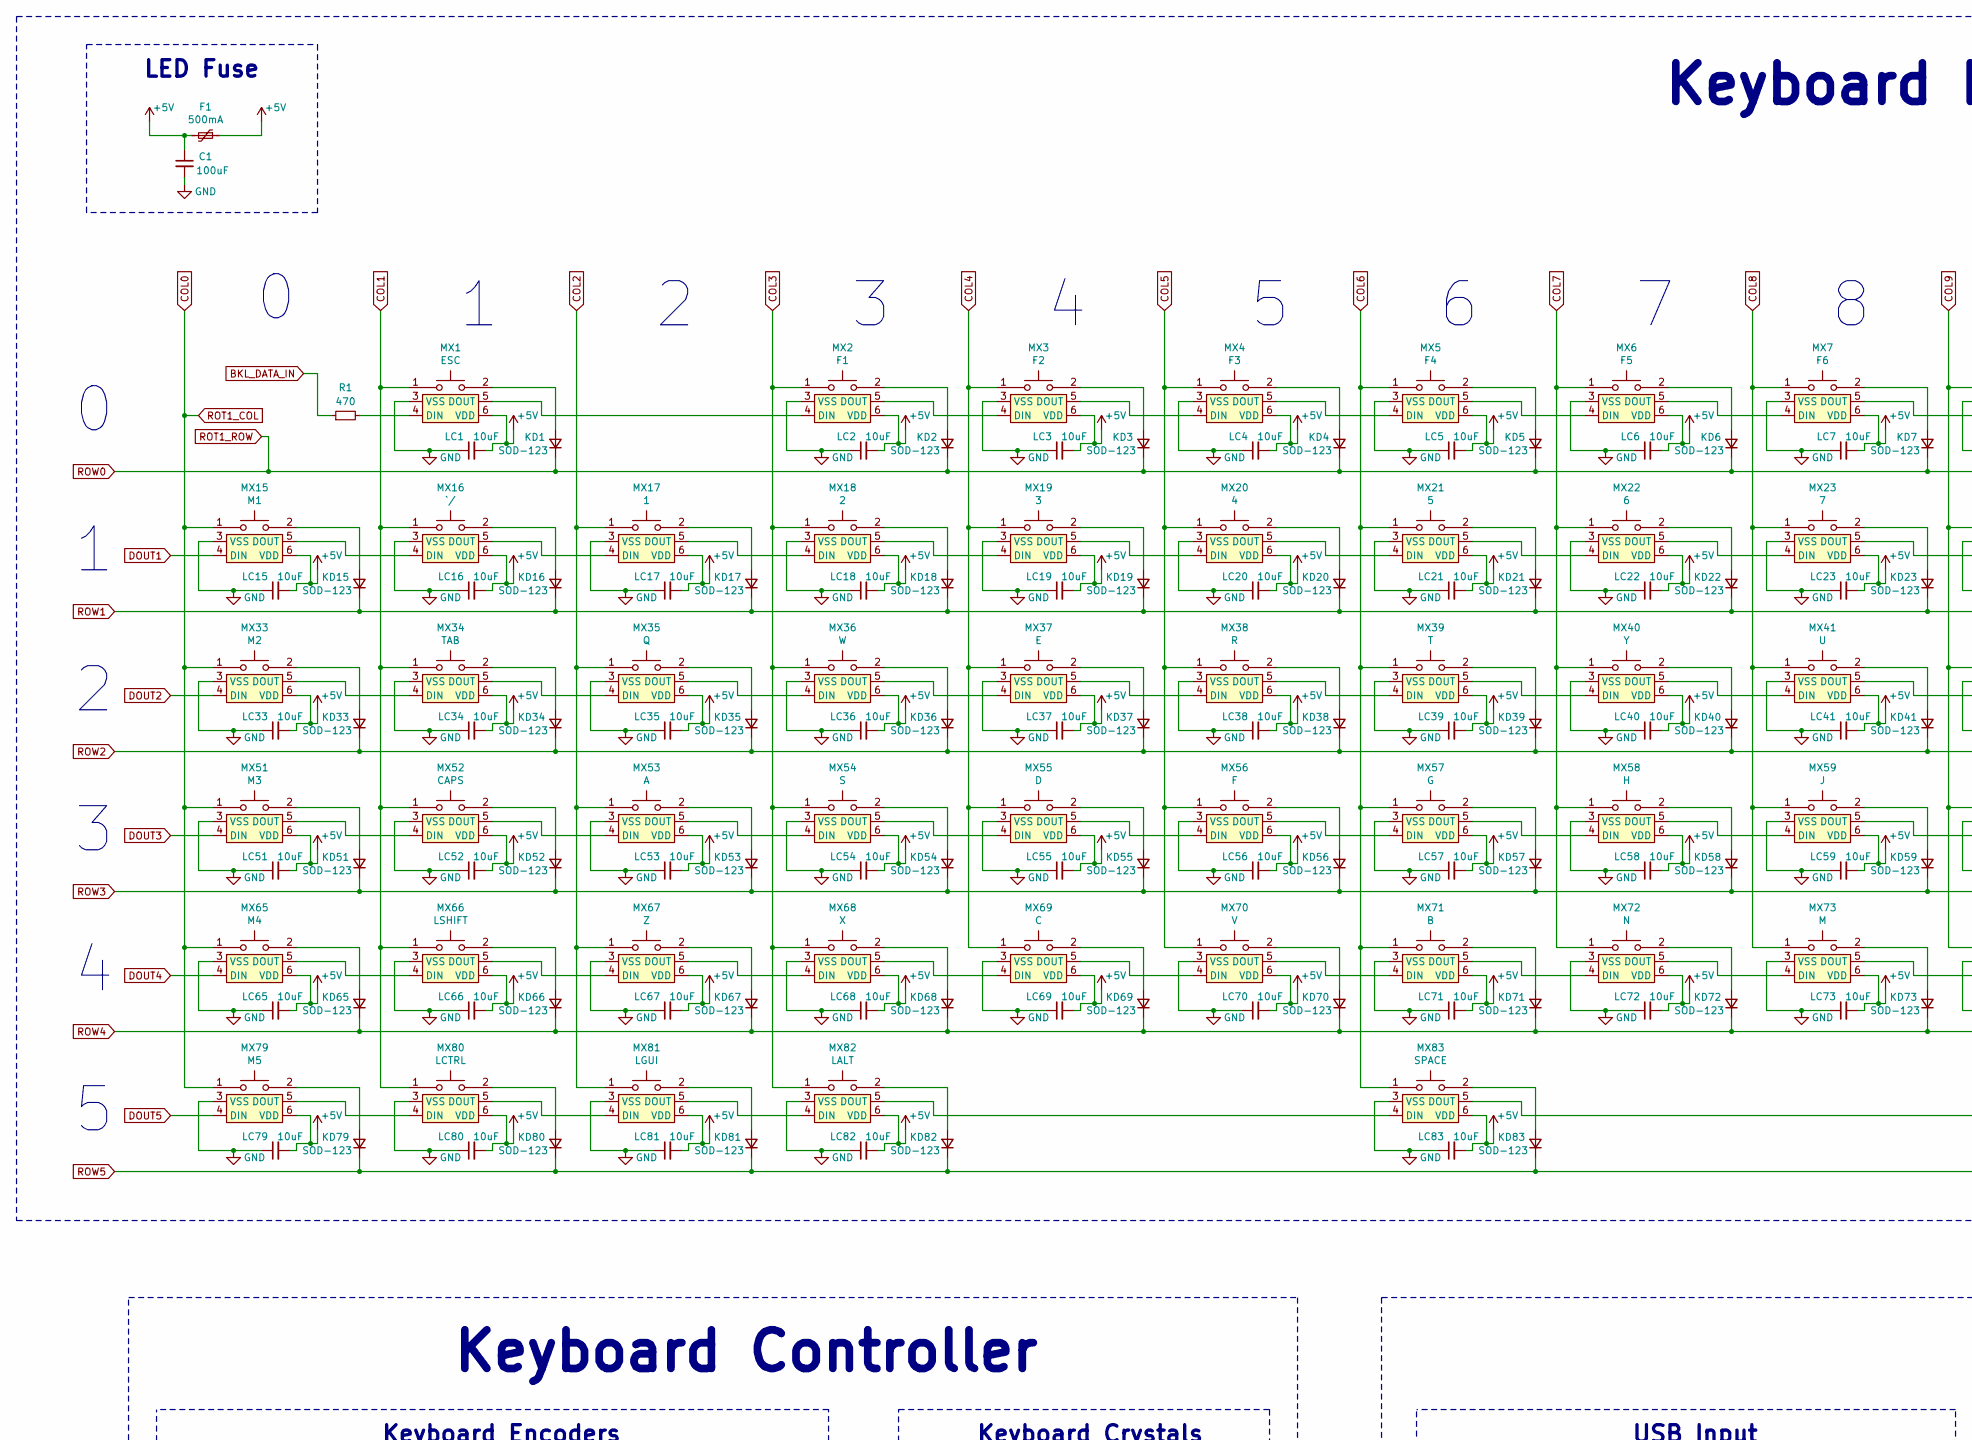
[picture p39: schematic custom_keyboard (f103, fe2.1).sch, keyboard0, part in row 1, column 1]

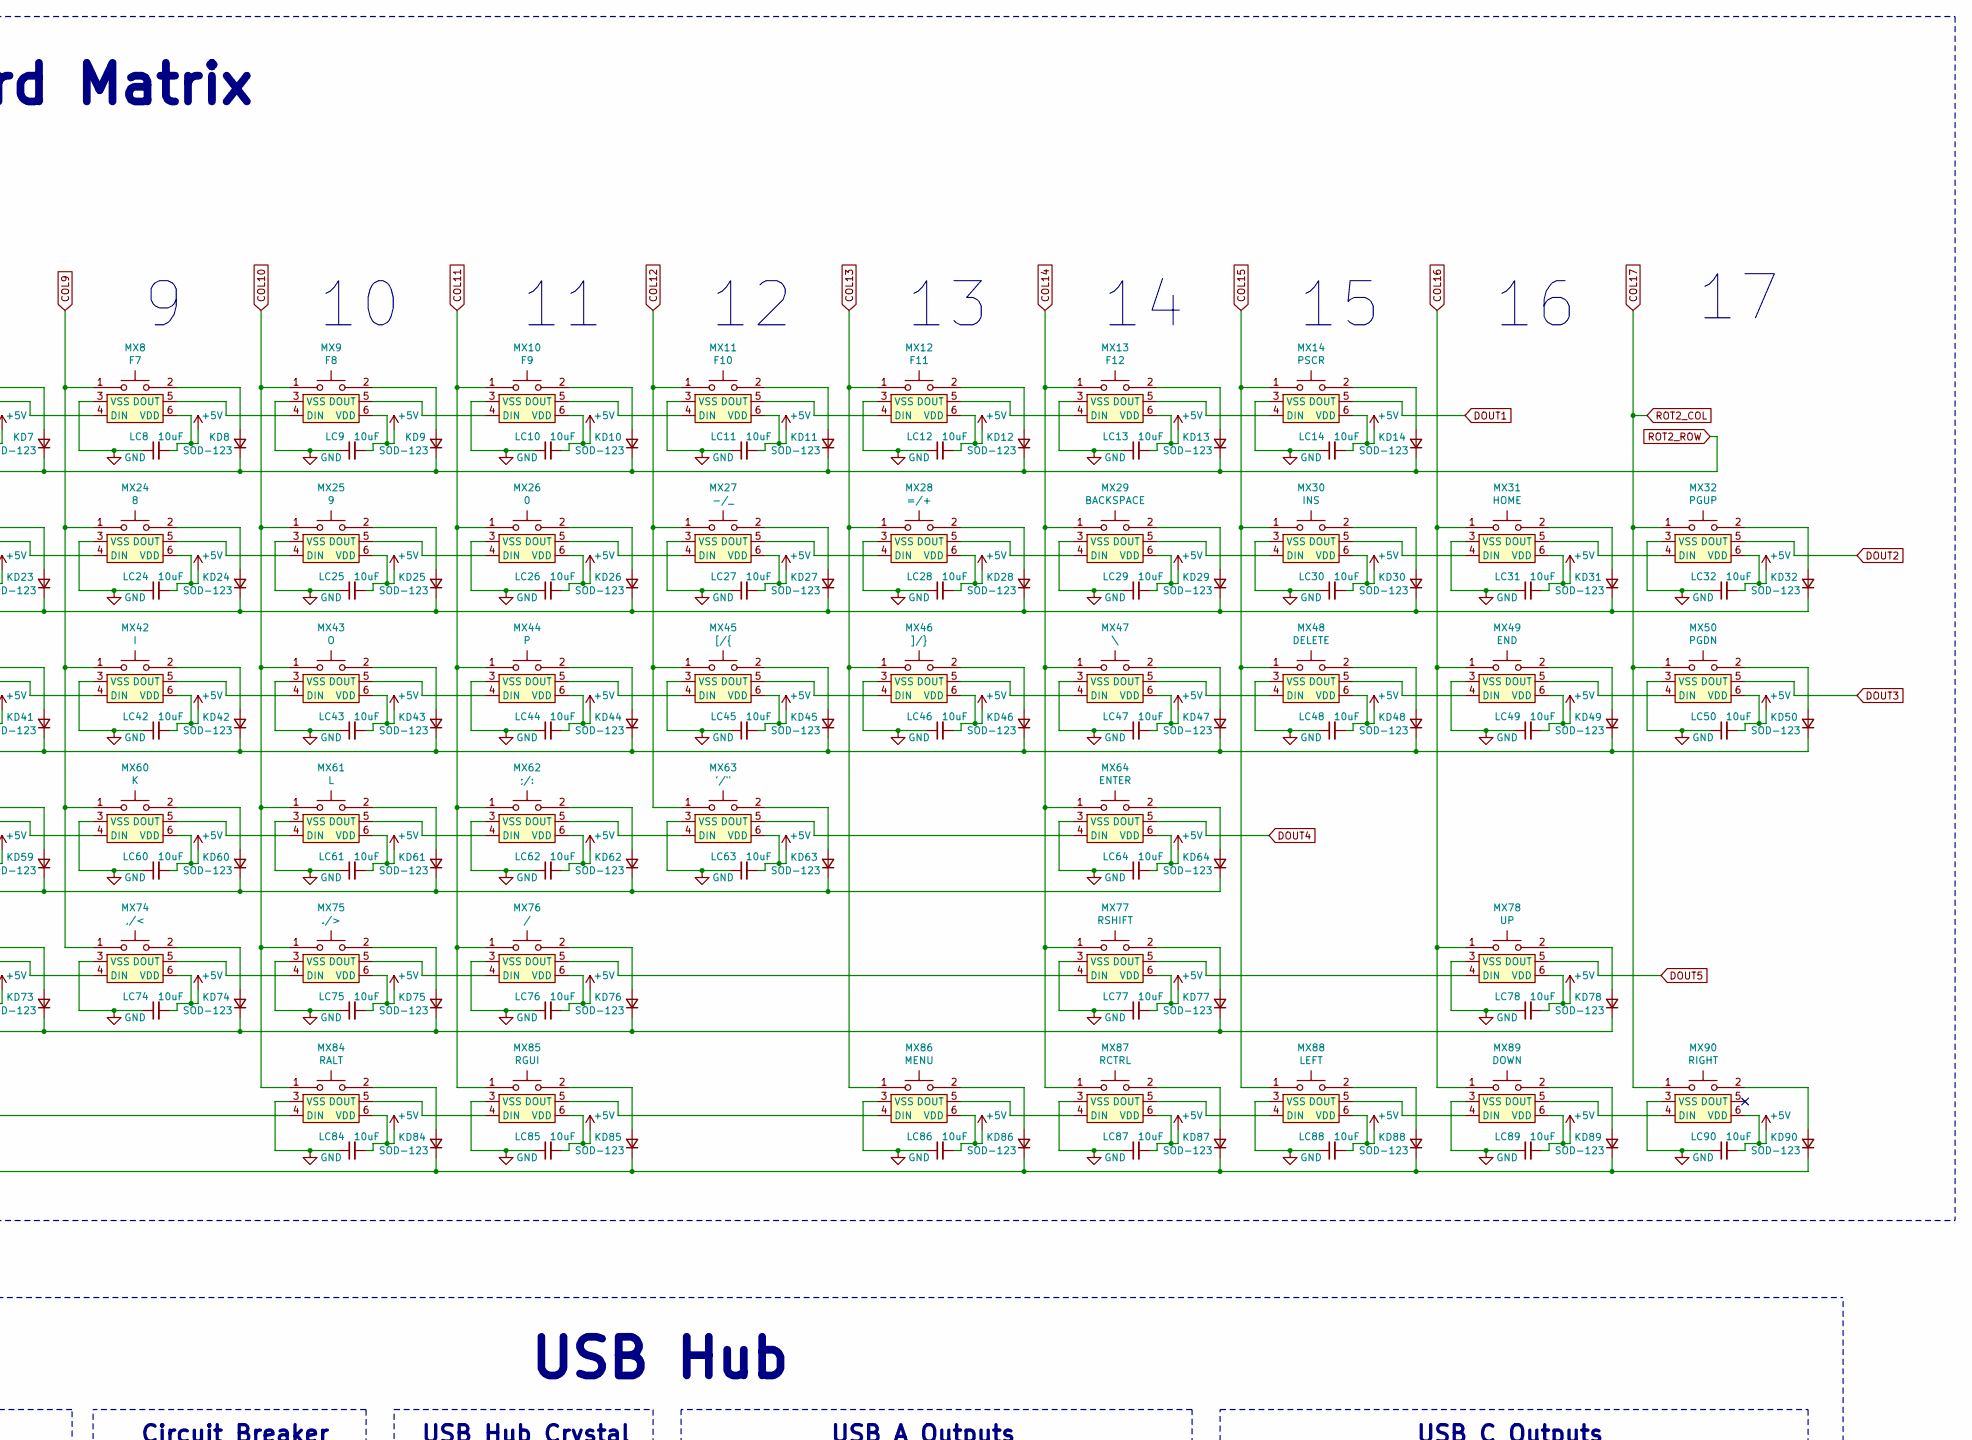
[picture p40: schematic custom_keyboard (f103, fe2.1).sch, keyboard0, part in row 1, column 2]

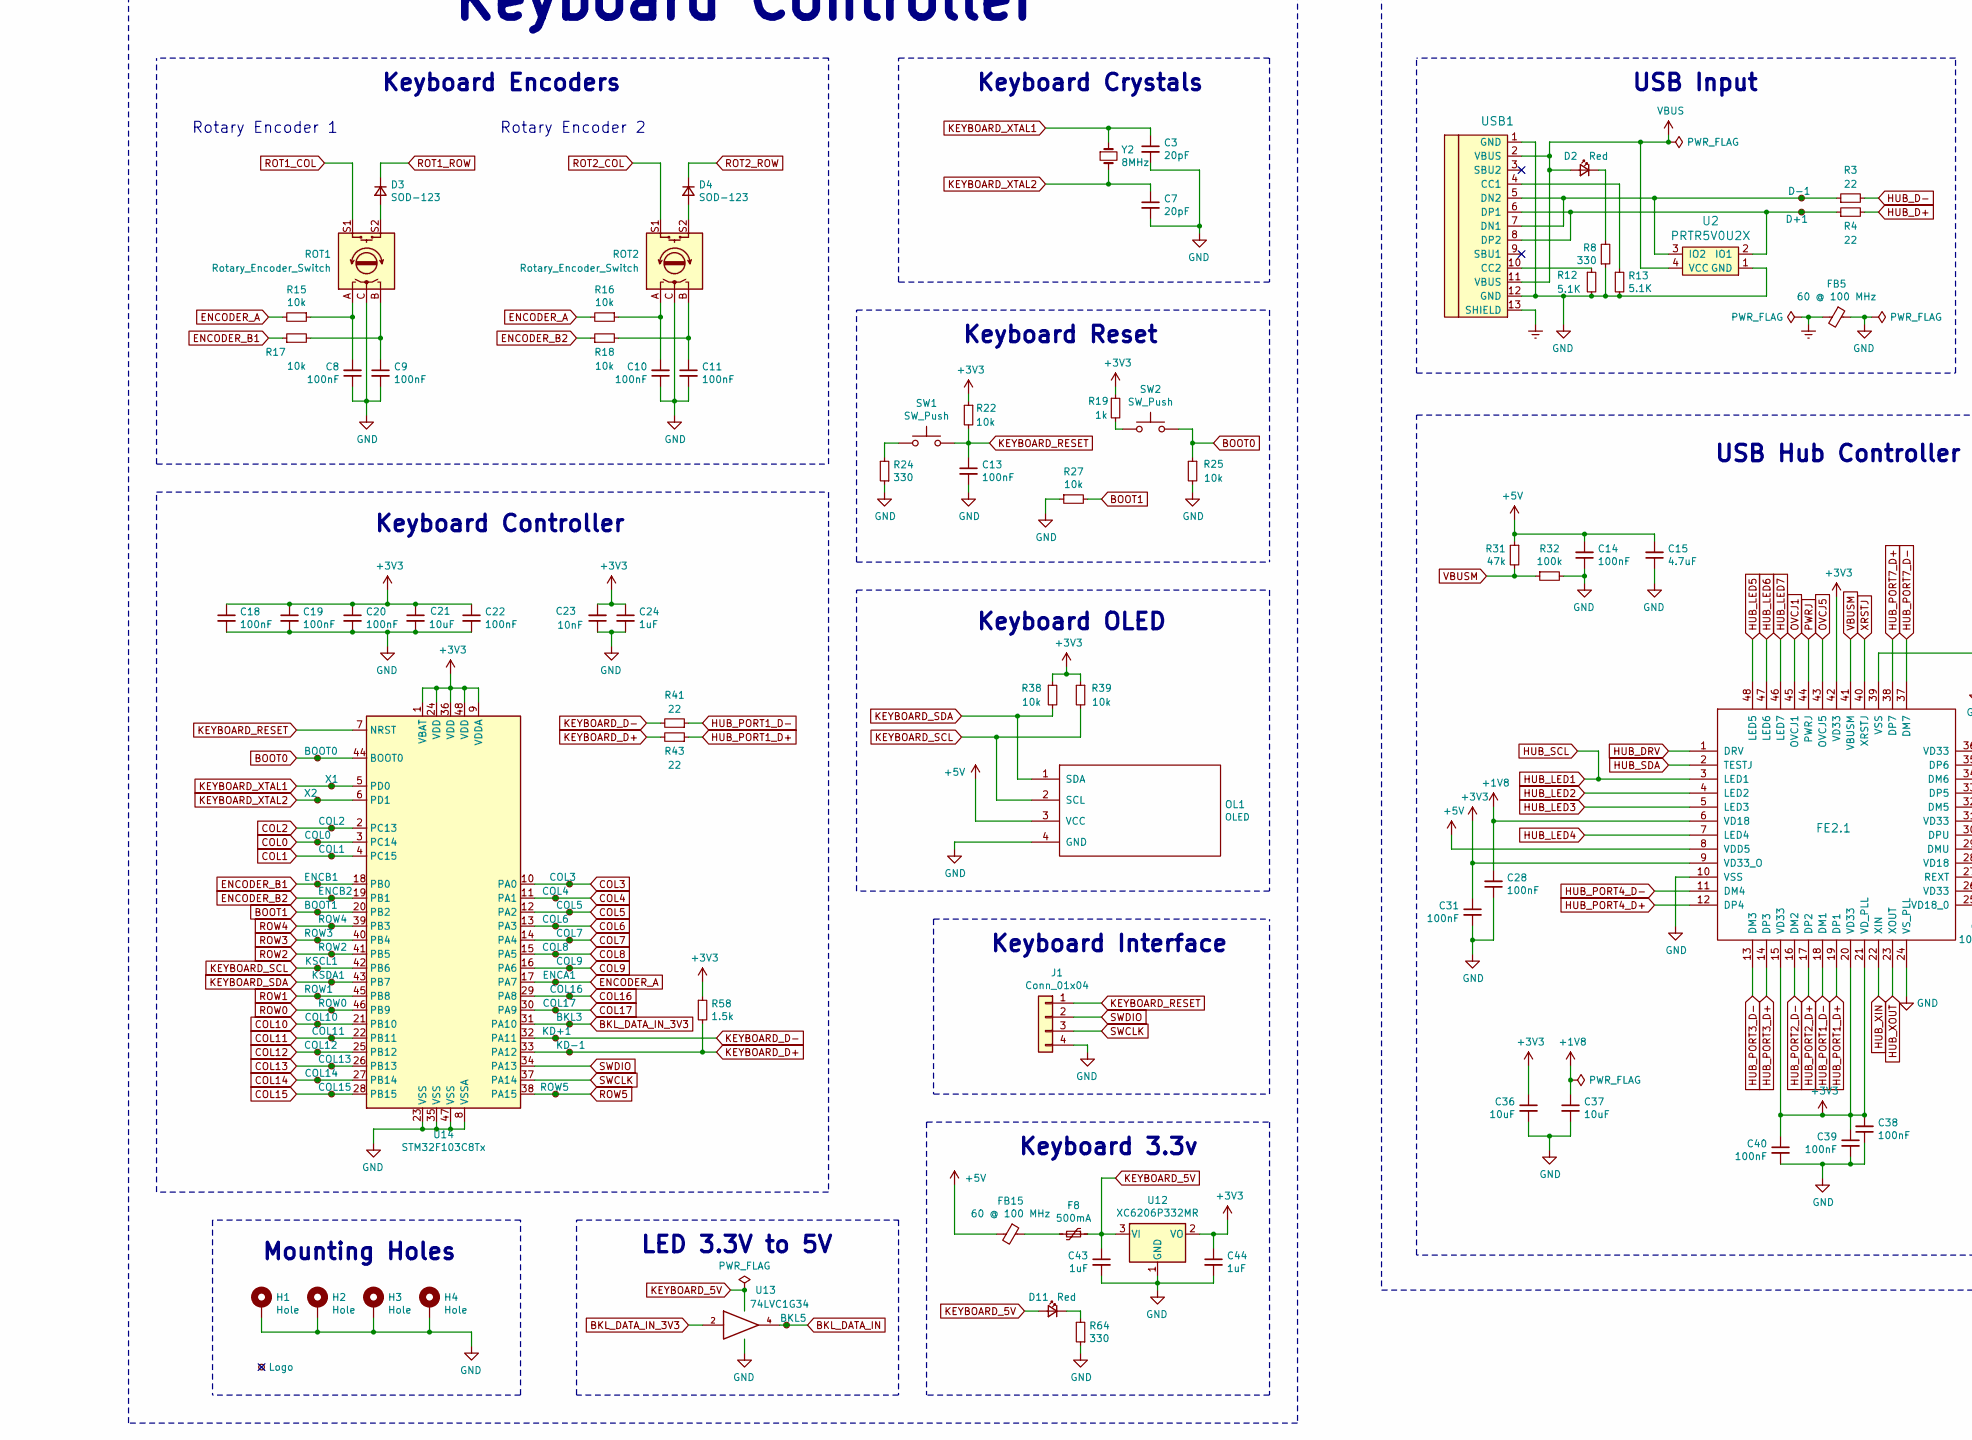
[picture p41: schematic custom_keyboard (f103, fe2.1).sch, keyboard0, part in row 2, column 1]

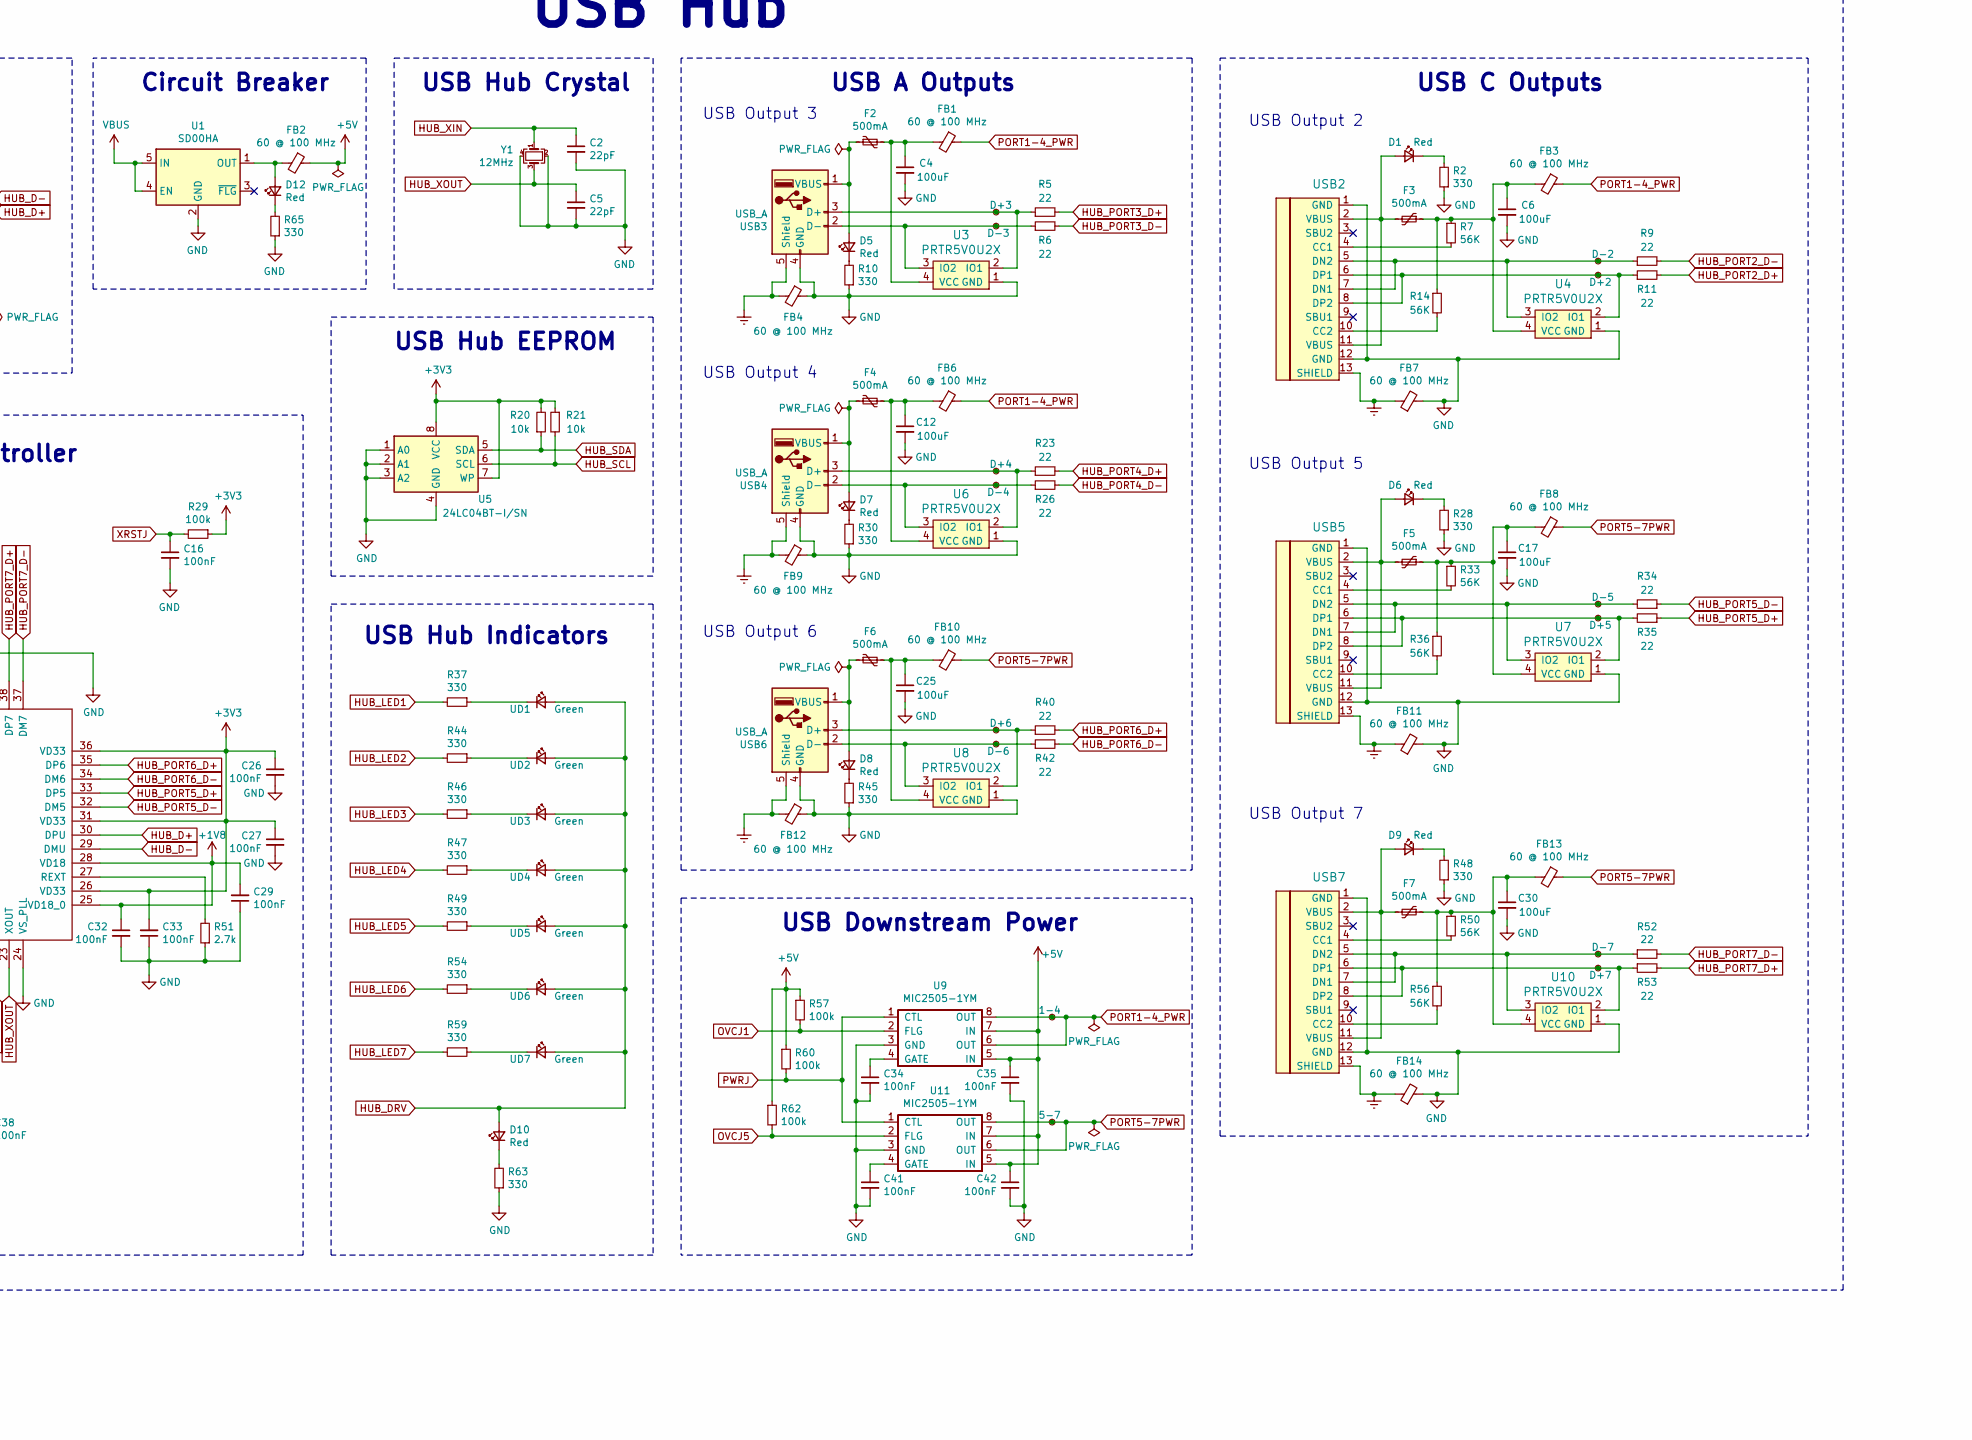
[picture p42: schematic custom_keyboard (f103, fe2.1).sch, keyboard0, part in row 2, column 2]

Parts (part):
1-4, 5-7: TestPoint_Small; TestPoint_THTPad_D1.0mm_Drill0.5mm; JLCPCB BOM 0
BKL3, BKL5: TestPoint_Small; TestPoint_THTPad_D1.0mm_Drill0.5mm; JLCPCB BOM 0
BOOT0, BOOT1: TestPoint_Small; TestPoint_THTPad_D1.0mm_Drill0.5mm; JLCPCB BOM 0
C1, C4, C6, C12, C17, C25, C30: 100uF; C_1206_3216Metric; LCSC Part C15008
C2, C5: 22pF; C_0805_2012Metric; LCSC Part C1804
C3, C7: 20pF; C_0805_2012Metric; LCSC Part C1798
C8, C9, C10, C11, C13, C14, C16, C18, C19, C20, C22, C26, C27, C28, C29, C31, C32, C33, C34, C35, C38, C39, C40, C41, C42: 100nF; C_0805_2012Metric; LCSC Part C49678
C15: 4.7uF; C_0805_2012Metric; LCSC Part C1779
C21, C36, C37: 10uF; C_0805_2012Metric; LCSC Part C15850
C23: 10nF; C_0805_2012Metric; LCSC Part C1710
C24, C43, C44: 1uF; C_0805_2012Metric; LCSC Part C28323
COL0, COL1, COL2, COL3, COL4, COL5, COL6, COL7, COL8, COL9, COL10, COL11, COL12, COL13, COL14, COL15, COL16, COL17: TestPoint_Small; TestPoint_THTPad_D1.0mm_Drill0.5mm; JLCPCB BOM 0
D1, D2, D5, D6, D7, D8, D9, D10, D11, D12: Red; LED_0805_2012Metric; LCSC Part C84256
D3, D4: SOD-123; D_SOD-123; LCSC Part C81598
D+1, D+2, D+3, D+4, D+5, D+6, D+7: TestPoint_Small; TestPoint_Pad_1.0x1.0mm; JLCPCB BOM 0
D-1, D-2, D-3, D-4, D-5, D-6, D-7: TestPoint_Small; TestPoint_Pad_1.0x1.0mm; JLCPCB BOM 0
ENCA1: TestPoint_Small; TestPoint_THTPad_D1.0mm_Drill0.5mm; JLCPCB BOM 0
ENCB1, ENCB2: TestPoint_Small; TestPoint_THTPad_D1.0mm_Drill0.5mm; JLCPCB BOM 0
F1, F2, F3, F4, F5, F6, F7, F8: 500mA; Fuse_1206_3216Metric; LCSC Part C70069
FB1, FB2, FB3, FB4, FB5, FB6, FB7, FB8, FB9, FB10, FB11, FB12, FB13, FB14, FB15: 60 @ 100 MHz; L_0805_2012Metric; LCSC Part C237300
FE2.1: FE2.1; LCSC Part C39693
H1, H2, H3, H4: Hole; MountingHole_3.2mm_M3_Pad; JLCPCB BOM 0
J1: Conn_01x04; PinSocket_1x04_P2.54mm_Vertical; JLCPCB BOM 0
KD1, KD2, KD3, KD4, KD5, KD6, KD7, KD8, KD9, KD10, KD11, KD12, KD13, KD14, KD15, KD16, KD17, KD18, KD19, KD20, KD21, KD22, KD23, KD24, KD25, KD26, KD27, KD28, KD29, KD30, KD31, KD32, KD33, KD34, KD35, KD36, KD37, KD38, KD39, KD40, KD41, KD42, KD43, KD44, KD45, KD46, KD47, KD48, KD49, KD50, KD51, KD52, KD53, KD54, KD55, KD56, KD57, KD58, KD59, KD60, KD61, KD62, KD63, KD64, KD65, KD66, KD67, KD68, KD69, KD70, KD71, KD72, KD73, KD74, KD75, KD76, KD77, KD78, KD79, KD80, KD81, KD82, KD83, KD84, KD85, KD86, KD87, KD88, KD89, KD90: SOD-123; D_SOD-123; LCSC Part C81598
KD+1: TestPoint_Small; TestPoint_Pad_1.0x1.0mm; JLCPCB BOM 0
KD-1: TestPoint_Small; TestPoint_Pad_1.0x1.0mm; JLCPCB BOM 0
KSCL1: TestPoint_Small; TestPoint_THTPad_D1.0mm_Drill0.5mm; JLCPCB BOM 0
KSDA1: TestPoint_Small; TestPoint_THTPad_D1.0mm_Drill0.5mm; JLCPCB BOM 0
LC1, LC2, LC3, LC4, LC5, LC6, LC7, LC8, LC9, LC10, LC11, LC12, LC13, LC14, LC15, LC16, LC17, LC18, LC19, LC20, LC21, LC22, LC23, LC24, LC25, LC26, LC27, LC28, LC29, LC30, LC31, LC32, LC33, LC34, LC35, LC36, LC37, LC38, LC39, LC40, LC41, LC42, LC43, LC44, LC45, LC46, LC47, LC48, LC49, LC50, LC51, LC52, LC53, LC54, LC55, LC56, LC57, LC58, LC59, LC60, LC61, LC62, LC63, LC64, LC65, LC66, LC67, LC68, LC69, LC70, LC71, LC72, LC73, LC74, LC75, LC76, LC77, LC78, LC79, LC80, LC81, LC82, LC83, LC84, LC85, LC86, LC87, LC88, LC89, LC90: 10uF; C_0805_2012Metric; LCSC Part C15850
LOGO0: Logo; logo; JLCPCB BOM 0
MX1: ESC; CherryMX_1.00u_PCB_KailhSocket_LTST-A683CEGBW; JLCPCB BOM 0
MX2: F1; CherryMX_1.00u_PCB_KailhSocket_LTST-A683CEGBW; JLCPCB BOM 0
MX3: F2; CherryMX_1.00u_PCB_KailhSocket_LTST-A683CEGBW; JLCPCB BOM 0
MX4: F3; CherryMX_1.00u_PCB_KailhSocket_LTST-A683CEGBW; JLCPCB BOM 0
MX5: F4; CherryMX_1.00u_PCB_KailhSocket_LTST-A683CEGBW; JLCPCB BOM 0
MX6: F5; CherryMX_1.00u_PCB_KailhSocket_LTST-A683CEGBW; JLCPCB BOM 0
MX7: F6; CherryMX_1.00u_PCB_KailhSocket_LTST-A683CEGBW; JLCPCB BOM 0
MX8: F7; CherryMX_1.00u_PCB_KailhSocket_LTST-A683CEGBW; JLCPCB BOM 0
MX9: F8; CherryMX_1.00u_PCB_KailhSocket_LTST-A683CEGBW; JLCPCB BOM 0
MX10: F9; CherryMX_1.00u_PCB_KailhSocket_LTST-A683CEGBW; JLCPCB BOM 0
MX11: F10; CherryMX_1.00u_PCB_KailhSocket_LTST-A683CEGBW; JLCPCB BOM 0
MX12: F11; CherryMX_1.00u_PCB_KailhSocket_LTST-A683CEGBW; JLCPCB BOM 0
MX13: F12; CherryMX_1.00u_PCB_KailhSocket_LTST-A683CEGBW; JLCPCB BOM 0
MX14: PSCR; CherryMX_1.00u_PCB_KailhSocket_LTST-A683CEGBW; JLCPCB BOM 0
MX15: M1; CherryMX_1.00u_PCB_KailhSocket_LTST-A683CEGBW; JLCPCB BOM 0
MX16: `/~; CherryMX_1.00u_PCB_KailhSocket_LTST-A683CEGBW; JLCPCB BOM 0
MX17: 1; CherryMX_1.00u_PCB_KailhSocket_LTST-A683CEGBW; JLCPCB BOM 0
MX18: 2; CherryMX_1.00u_PCB_KailhSocket_LTST-A683CEGBW; JLCPCB BOM 0
MX19: 3; CherryMX_1.00u_PCB_KailhSocket_LTST-A683CEGBW; JLCPCB BOM 0
MX20: 4; CherryMX_1.00u_PCB_KailhSocket_LTST-A683CEGBW; JLCPCB BOM 0
MX21: 5; CherryMX_1.00u_PCB_KailhSocket_LTST-A683CEGBW; JLCPCB BOM 0
MX22: 6; CherryMX_1.00u_PCB_KailhSocket_LTST-A683CEGBW; JLCPCB BOM 0
MX23: 7; CherryMX_1.00u_PCB_KailhSocket_LTST-A683CEGBW; JLCPCB BOM 0
MX24: 8; CherryMX_1.00u_PCB_KailhSocket_LTST-A683CEGBW; JLCPCB BOM 0
MX25: 9; CherryMX_1.00u_PCB_KailhSocket_LTST-A683CEGBW; JLCPCB BOM 0
MX26: 0; CherryMX_1.00u_PCB_KailhSocket_LTST-A683CEGBW; JLCPCB BOM 0
MX27: -/_; CherryMX_1.00u_PCB_KailhSocket_LTST-A683CEGBW; JLCPCB BOM 0
MX28: =/+; CherryMX_1.00u_PCB_KailhSocket_LTST-A683CEGBW; JLCPCB BOM 0
MX29: BACKSPACE; CherryMX_2.00u_PCB_KailhSocket_LTST-A683CEGBW; JLCPCB BOM 0
MX30: INS; CherryMX_1.00u_PCB_KailhSocket_LTST-A683CEGBW; JLCPCB BOM 0
MX31: HOME; CherryMX_1.00u_PCB_KailhSocket_LTST-A683CEGBW; JLCPCB BOM 0
MX32: PGUP; CherryMX_1.00u_PCB_KailhSocket_LTST-A683CEGBW; JLCPCB BOM 0
MX33: M2; CherryMX_1.00u_PCB_KailhSocket_LTST-A683CEGBW; JLCPCB BOM 0
MX34: TAB; CherryMX_1.50u_PCB_KailhSocket_LTST-A683CEGBW; JLCPCB BOM 0
MX35: Q; CherryMX_1.00u_PCB_KailhSocket_LTST-A683CEGBW; JLCPCB BOM 0
MX36: W; CherryMX_1.00u_PCB_KailhSocket_LTST-A683CEGBW; JLCPCB BOM 0
MX37: E; CherryMX_1.00u_PCB_KailhSocket_LTST-A683CEGBW; JLCPCB BOM 0
MX38: R; CherryMX_1.00u_PCB_KailhSocket_LTST-A683CEGBW; JLCPCB BOM 0
MX39: T; CherryMX_1.00u_PCB_KailhSocket_LTST-A683CEGBW; JLCPCB BOM 0
MX40: Y; CherryMX_1.00u_PCB_KailhSocket_LTST-A683CEGBW; JLCPCB BOM 0
MX41: U; CherryMX_1.00u_PCB_KailhSocket_LTST-A683CEGBW; JLCPCB BOM 0
MX42: I; CherryMX_1.00u_PCB_KailhSocket_LTST-A683CEGBW; JLCPCB BOM 0
MX43: O; CherryMX_1.00u_PCB_KailhSocket_LTST-A683CEGBW; JLCPCB BOM 0
MX44: P; CherryMX_1.00u_PCB_KailhSocket_LTST-A683CEGBW; JLCPCB BOM 0
MX45: [/{; CherryMX_1.00u_PCB_KailhSocket_LTST-A683CEGBW; JLCPCB BOM 0
MX46: ]/}; CherryMX_1.00u_PCB_KailhSocket_LTST-A683CEGBW; JLCPCB BOM 0
MX47: \\; CherryMX_1.50u_PCB_KailhSocket_LTST-A683CEGBW; JLCPCB BOM 0
MX48: DELETE; CherryMX_1.00u_PCB_KailhSocket_LTST-A683CEGBW; JLCPCB BOM 0
MX49: END; CherryMX_1.00u_PCB_KailhSocket_LTST-A683CEGBW; JLCPCB BOM 0
MX50: PGDN; CherryMX_1.00u_PCB_KailhSocket_LTST-A683CEGBW; JLCPCB BOM 0
MX51: M3; CherryMX_1.00u_PCB_KailhSocket_LTST-A683CEGBW; JLCPCB BOM 0
MX52: CAPS; CherryMX_1.75u_PCB_KailhSocket_LTST-A683CEGBW; JLCPCB BOM 0
MX53: A; CherryMX_1.00u_PCB_KailhSocket_LTST-A683CEGBW; JLCPCB BOM 0
MX54: S; CherryMX_1.00u_PCB_KailhSocket_LTST-A683CEGBW; JLCPCB BOM 0
MX55: D; CherryMX_1.00u_PCB_KailhSocket_LTST-A683CEGBW; JLCPCB BOM 0
MX56: F; CherryMX_1.00u_PCB_KailhSocket_LTST-A683CEGBW; JLCPCB BOM 0
MX57: G; CherryMX_1.00u_PCB_KailhSocket_LTST-A683CEGBW; JLCPCB BOM 0
MX58: H; CherryMX_1.00u_PCB_KailhSocket_LTST-A683CEGBW; JLCPCB BOM 0
MX59: J; CherryMX_1.00u_PCB_KailhSocket_LTST-A683CEGBW; JLCPCB BOM 0
MX60: K; CherryMX_1.00u_PCB_KailhSocket_LTST-A683CEGBW; JLCPCB BOM 0
MX61: L; CherryMX_1.00u_PCB_KailhSocket_LTST-A683CEGBW; JLCPCB BOM 0
MX62: ;/:; CherryMX_1.00u_PCB_KailhSocket_LTST-A683CEGBW; JLCPCB BOM 0
MX63: '/\"; CherryMX_1.00u_PCB_KailhSocket_LTST-A683CEGBW; JLCPCB BOM 0
MX64: ENTER; CherryMX_2.25u_PCB_KailhSocket_LTST-A683CEGBW; JLCPCB BOM 0
MX65: M4; CherryMX_1.00u_PCB_KailhSocket_LTST-A683CEGBW; JLCPCB BOM 0
MX66: LSHIFT; CherryMX_2.25u_PCB_KailhSocket_LTST-A683CEGBW; JLCPCB BOM 0
MX67: Z; CherryMX_1.00u_PCB_KailhSocket_LTST-A683CEGBW; JLCPCB BOM 0
MX68: X; CherryMX_1.00u_PCB_KailhSocket_LTST-A683CEGBW; JLCPCB BOM 0
MX69: C; CherryMX_1.00u_PCB_KailhSocket_LTST-A683CEGBW; JLCPCB BOM 0
MX70: V; CherryMX_1.00u_PCB_KailhSocket_LTST-A683CEGBW; JLCPCB BOM 0
MX71: B; CherryMX_1.00u_PCB_KailhSocket_LTST-A683CEGBW; JLCPCB BOM 0
MX72: N; CherryMX_1.00u_PCB_KailhSocket_LTST-A683CEGBW; JLCPCB BOM 0
MX73: M; CherryMX_1.00u_PCB_KailhSocket_LTST-A683CEGBW; JLCPCB BOM 0
MX74: ,/<; CherryMX_1.00u_PCB_KailhSocket_LTST-A683CEGBW; JLCPCB BOM 0
MX75: ./>; CherryMX_1.00u_PCB_KailhSocket_LTST-A683CEGBW; JLCPCB BOM 0
MX76: /; CherryMX_1.00u_PCB_KailhSocket_LTST-A683CEGBW; JLCPCB BOM 0
MX77: RSHIFT; CherryMX_2.75u_PCB_KailhSocket_LTST-A683CEGBW; JLCPCB BOM 0
MX78: UP; CherryMX_1.00u_PCB_KailhSocket_LTST-A683CEGBW; JLCPCB BOM 0
MX79: M5; CherryMX_1.00u_PCB_KailhSocket_LTST-A683CEGBW; JLCPCB BOM 0
MX80: LCTRL; CherryMX_1.25u_PCB_KailhSocket_LTST-A683CEGBW; JLCPCB BOM 0
MX81: LGUI; CherryMX_1.25u_PCB_KailhSocket_LTST-A683CEGBW; JLCPCB BOM 0
MX82: LALT; CherryMX_1.25u_PCB_KailhSocket_LTST-A683CEGBW; JLCPCB BOM 0
MX83: SPACE; CherryMX_6.25u_PCB_KailhSocket_LTST-A683CEGBW; JLCPCB BOM 0
MX84: RALT; CherryMX_1.25u_PCB_KailhSocket_LTST-A683CEGBW; JLCPCB BOM 0
MX85: RGUI; CherryMX_1.25u_PCB_KailhSocket_LTST-A683CEGBW; JLCPCB BOM 0
MX86: MENU; CherryMX_1.25u_PCB_KailhSocket_LTST-A683CEGBW; JLCPCB BOM 0
MX87: RCTRL; CherryMX_1.25u_PCB_KailhSocket_LTST-A683CEGBW; JLCPCB BOM 0
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

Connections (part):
+1V8: C28.2, C29.2, C32.1, C37.1, FE2.1.6 (VD18), FE2.1.25 (VD18_0), FE2.1.28 (VD18)
+3V3: C18.1, C19.1, C20.1, C21.1, C22.1, C23.2, C24.1, C26.1, C27.1, C31.1, C33.2, C36.1, C38.2, C39.1, C40.1, C44.1, FE2.1.9 (VD33_O), FE2.1.15 (VD33), FE2.1.20 (VD33), FE2.1.21 (VD_PLL), FE2.1.26 (VD33), FE2.1.31 (VD33), FE2.1.36 (VD33), FE2.1.42 (VD33), R19.1, R20.2, R21.1, R22.1, R29.1, R38.1, R39.1, R58.1, U5.7 (WP), U5.8 (VCC), U12.2 (VO), U14.1 (VBAT), U14.9 (VDDA), U14.24 (VDD), U14.36 (VDD), U14.48 (VDD)
+5V: C1.1, C14.2, C15.2, C35.1, C42.1, F1.1, F1.2, FB2.1, FB15.2, FE2.1.8 (VDD5), LC1.2, LC2.2, LC3.2, LC4.2, LC5.2, LC6.2, LC7.2, LC8.2, LC9.2, LC10.2, LC11.2, LC12.2, LC13.2, LC14.2, LC15.2, LC16.2, LC17.2, LC18.2, LC19.2, LC20.2, LC21.2, LC22.2, LC23.2, LC24.2, LC25.2, LC26.2, LC27.2, LC28.2, LC29.2, LC30.2, LC31.2, LC32.2, LC33.2, LC34.2, LC35.2, LC36.2, LC37.2, LC38.2, LC39.2, LC40.2, LC41.2, LC42.2, LC43.2, LC44.2, LC45.2, LC46.2, LC47.2, LC48.2, LC49.2, LC50.2, LC51.2, LC52.2, LC53.2, LC54.2, LC55.2, LC56.2, LC57.2, LC58.2, LC59.2, LC60.2, LC61.2, LC62.2, LC63.2, LC64.2, LC65.2, LC66.2, LC67.2, LC68.2, LC69.2, LC70.2, LC71.2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
BKL_DATA_IN: BKL5.1, R1.1, U13.4
BKL_DATA_IN_3V3: BKL3.1, U13.2, U14.31 (PA10)
BOOT0: BOOT0.1, R25.1, SW2.2, U14.44 (BOOT0)
BOOT1: BOOT1.1, R27.2, U14.20 (PB2)
COL0: COL0.1, MX15.1, MX33.1, MX51.1, MX65.1, MX79.1, ROT1.S1, U14.3 (PC14)
COL1: COL1.1, MX1.1, MX16.1, MX34.1, MX52.1, MX66.1, MX80.1, U14.4 (PC15)
COL2: COL2.1, MX17.1, MX35.1, MX53.1, MX67.1, MX81.1, U14.2 (PC13)
COL3: COL3.1, MX2.1, MX18.1, MX36.1, MX54.1, MX68.1, MX82.1, U14.10 (PA0)
COL4: COL4.1, MX3.1, MX19.1, MX37.1, MX55.1, MX69.1, U14.11 (PA1)
COL5: COL5.1, MX4.1, MX20.1, MX38.1, MX56.1, MX70.1, U14.12 (PA2)
COL6: COL6.1, MX5.1, MX21.1, MX39.1, MX57.1, MX71.1, MX83.1, U14.13 (PA3)
COL7: COL7.1, MX6.1, MX22.1, MX40.1, MX58.1, MX72.1, U14.14 (PA4)
COL8: COL8.1, MX7.1, MX23.1, MX41.1, MX59.1, MX73.1, U14.15 (PA5)
COL9: COL9.1, MX8.1, MX24.1, MX42.1, MX60.1, MX74.1, U14.16 (PA6)
COL10: COL10.1, MX9.1, MX25.1, MX43.1, MX61.1, MX75.1, MX84.1, U14.21 (PB10)
COL11: COL11.1, MX10.1, MX26.1, MX44.1, MX62.1, MX76.1, MX85.1, U14.22 (PB11)
COL12: COL12.1, MX11.1, MX27.1, MX45.1, MX63.1, U14.25 (PB12)
COL13: COL13.1, MX12.1, MX28.1, MX46.1, MX86.1, U14.26 (PB13)
COL14: COL14.1, MX13.1, MX29.1, MX47.1, MX64.1, MX77.1, MX87.1, U14.27 (PB14)
COL15: COL15.1, MX14.1, MX30.1, MX48.1, MX88.1, U14.28 (PB15)
COL16: COL16.1, MX31.1, MX49.1, MX78.1, MX89.1, U14.29 (PA8)
COL17: COL17.1, MX32.1, MX50.1, MX90.1, ROT2.S1, U14.30 (PA9)
DOUT1: MX14.5 (DOUT), MX15.4 (DIN)
DOUT2: MX32.5 (DOUT), MX33.4 (DIN)
DOUT3: MX50.5 (DOUT), MX51.4 (DIN)
DOUT4: MX64.5 (DOUT), MX65.4 (DIN)
DOUT5: MX78.5 (DOUT), MX79.4 (DIN)
ENCODER_A: ENCA1.1, R15.2, R16.2, U14.17 (PA7)
ENCODER_B1: ENCB1.1, R17.1, U14.18 (PB0)
ENCODER_B2: ENCB2.1, R18.1, U14.19 (PB1)
Earth: FB4.2, FB5.2, FB7.1, FB9.2, FB11.1, FB12.2, FB14.1, USB1.13 (SHIELD), USB2.13 (SHIELD), USB3.5 (Shield), USB4.5 (Shield), USB5.13 (SHIELD), USB6.5 (Shield), USB7.13 (SHIELD)
GND: C1.2, C2.2, C3.2, C4.2, C5.2, C6.2, C7.2, C8.1, C9.2, C10.1, C11.2, C12.2, C13.2, C14.1, C15.1, C16.2, C17.2, C18.2, C19.2, C20.2, C21.2, C22.2, C23.1, C24.2, C25.2, C26.2, C27.2, C28.1, C29.1, C30.2, C31.2, C32.2, C33.1, C34.2, C35.2, C36.2, C37.2, C38.1, C39.2, C40.2, C41.2, C42.2, C43.2, C44.2, FB4.1, FB5.1, FB7.2, FB9.1, FB11.2, FB12.1, FB14.2, FE2.1.10 (VSS), FE2.1.24 (VS_PLL), FE2.1.39 (VSS), H1.1, H2.1, H3.1, H4.1, J1.4, LC1.1, LC2.1, LC3.1, LC4.1, LC5.1, LC6.1, LC7.1, LC8.1, LC9.1, LC10.1, LC11.1, LC12.1, LC13.1, LC14.1, LC15.1, LC16.1, LC17.1, LC18.1, LC19.1, LC20.1, LC21.1, LC22.1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
HUB_D+: FE2.1.30 (DPU), R4.2
HUB_D-: FE2.1.29 (DMU), R3.2
HUB_DRV: D10.2 (A), FE2.1.1 (DRV), UD1.2 (A), UD2.2 (A), UD3.2 (A), UD4.2 (A), UD5.2 (A), UD6.2 (A), UD7.2 (A)
HUB_LED1: FE2.1.3 (LED1), R21.2, R37.2, U5.6 (SCL)
HUB_LED2: FE2.1.4 (LED2), R44.2
HUB_LED3: FE2.1.5 (LED3), R46.2
HUB_LED4: FE2.1.7 (LED4), R47.2
HUB_LED5: FE2.1.48 (LED5), R49.2
HUB_LED6: FE2.1.47 (LED6), R54.2
HUB_LED7: FE2.1.46 (LED7), R59.2
HUB_PORT1_D+: FE2.1.19 (DP1), R43.1
HUB_PORT1_D-: FE2.1.18 (DM1), R41.1
HUB_PORT2_D+: FE2.1.17 (DP2), R11.2
HUB_PORT2_D-: FE2.1.16 (DM2), R9.2
HUB_PORT3_D+: FE2.1.14 (DP3), R5.2
HUB_PORT3_D-: FE2.1.13 (DM3), R6.2
HUB_PORT4_D+: FE2.1.12 (DP4), R23.2
HUB_PORT4_D-: FE2.1.11 (DM4), R26.2
HUB_PORT5_D+: FE2.1.33 (DP5), R35.1
HUB_PORT5_D-: FE2.1.32 (DM5), R34.1
HUB_PORT6_D+: FE2.1.35 (DP6), R40.2
HUB_PORT6_D-: FE2.1.34 (DM6), R42.2
HUB_PORT7_D+: FE2.1.38 (DP7), R53.2
HUB_PORT7_D-: FE2.1.37 (DM7), R52.2
HUB_SDA: FE2.1.2 (TESTJ), R20.1, U5.5 (SDA)
HUB_XIN: C2.1, FE2.1.22 (XIN), Y1.1
HUB_XOUT: C5.1, FE2.1.23 (XOUT), Y1.3
KEYBOARD_5V: C43.1, D11.2 (A), F8.1, U12.3 (VI), U13.5 (VCC)
KEYBOARD_D+: KD-1.1, R43.2, R58.2, U14.33 (PA12)
KEYBOARD_D-: KD+1.1, R41.2, U14.32 (PA11)
KEYBOARD_RESET: C13.1, J1.1, R22.2, SW1.2, U14.7 (NRST)
KEYBOARD_SCL: KSCL1.1, OL1.2 (SCL), R39.2, U14.42 (PB6)
KEYBOARD_SDA: KSDA1.1, OL1.1 (SDA), R38.2, U14.43 (PB7)
KEYBOARD_XTAL1: C3.1, U14.5 (PD0), X1.1, Y2.1
KEYBOARD_XTAL2: C7.1, U14.6 (PD1), X2.1, Y2.2
unnamed: C4.1, F2.2, FB1.2, U3.4 (VCC)
unnamed: C6.1, F3.1, FB3.2, R7.1, R14.1, U4.4 (VCC)
unnamed: C8.2, R15.1, ROT1.A
unnamed: C9.1, R17.2, ROT1.B
unnamed: C10.2, R16.1, ROT2.A
unnamed: C11.1, R18.2, ROT2.B
unnamed: C12.1, F4.2, FB6.2, U6.4 (VCC)
unnamed: C17.1, F5.1, FB8.2, R33.1, R36.1, U7.4 (VCC)
unnamed: C25.1, F6.2, FB10.2, U8.4 (VCC)
unnamed: C30.1, F7.1, FB13.2, R50.1, R56.1, U10.4 (VCC)
unnamed: C34.1, U9.4 (GATE)
unnamed: C41.1, U11.4 (GATE)
unnamed: D1.1 (K), R2.2
unnamed: D1.2 (A), F3.2, USB2.2 (VBUS), USB2.11 (VBUS)
unnamed: D2.1 (K), R8.2
unnamed: D3.2 (A), ROT1.S2
unnamed: D4.2 (A), ROT2.S2
unnamed: D5.1 (K), R10.2
unnamed: D5.2 (A), F2.1, USB3.1 (VBUS)
unnamed: D6.1 (K), R28.2
unnamed: D6.2 (A), F5.2, USB5.2 (VBUS), USB5.11 (VBUS)
unnamed: D7.1 (K), R30.2
unnamed: D7.2 (A), F4.1, USB4.1 (VBUS)
unnamed: D8.1 (K), R45.2
unnamed: D8.2 (A), F6.1, USB6.1 (VBUS)
unnamed: D9.1 (K), R48.2
unnamed: D9.2 (A), F7.2, USB7.2 (VBUS), USB7.11 (VBUS)
unnamed: D10.1 (K), R63.2
unnamed: D11.1 (K), R64.2
unnamed: D12.1 (K), R65.2
unnamed: D12.2 (A), FB2.2, U1.1 (OUT)
unnamed: D+1.1, R4.1, U2.2 (IO1), USB1.6 (DP1), USB1.8 (DP2)
unnamed: D+2.1, R11.1, U4.2 (IO1), USB2.6 (DP1), USB2.8 (DP2)
unnamed: D+3.1, R5.1, U3.2 (IO1), USB3.3 (D+)
unnamed: D+4.1, R23.1, U6.2 (IO1), USB4.3 (D+)
unnamed: D+5.1, R35.2, U7.2 (IO1), USB5.6 (DP1), USB5.8 (DP2)
unnamed: D+6.1, R40.1, U8.2 (IO1), USB6.3 (D+)
unnamed: D+7.1, R53.1, U10.2 (IO1), USB7.6 (DP1), USB7.8 (DP2)
unnamed: D-1.1, R3.1, U2.3 (IO2), USB1.5 (DN2), USB1.7 (DN1)
unnamed: D-2.1, R9.1, U4.3 (IO2), USB2.5 (DN2), USB2.7 (DN1)
unnamed: D-3.1, R6.1, U3.3 (IO2), USB3.2 (D-)
unnamed: D-4.1, R26.1, U6.3 (IO2), USB4.2 (D-)
unnamed: D-5.1, R34.2, U7.3 (IO2), USB5.5 (DN2), USB5.7 (DN1)
unnamed: D-6.1, R42.1, U8.3 (IO2), USB6.2 (D-)
unnamed: D-7.1, R52.1, U10.3 (IO2), USB7.5 (DN2), USB7.7 (DN1)
unnamed: F8.2, FB15.1
unnamed: FE2.1.27 (REXT), R51.2
unnamed: KD1.2 (A), MX1.2
unnamed: KD2.2 (A), MX2.2
unnamed: KD3.2 (A), MX3.2
unnamed: KD4.2 (A), MX4.2
unnamed: KD5.2 (A), MX5.2
unnamed: KD6.2 (A), MX6.2
unnamed: KD7.2 (A), MX7.2
unnamed: KD8.2 (A), MX8.2
unnamed: KD9.2 (A), MX9.2
unnamed: KD10.2 (A), MX10.2
unnamed: KD11.2 (A), MX11.2
unnamed: KD12.2 (A), MX12.2
unnamed: KD13.2 (A), MX13.2
unnamed: KD14.2 (A), MX14.2
unnamed: KD15.2 (A), MX15.2
unnamed: KD16.2 (A), MX16.2
unnamed: KD17.2 (A), MX17.2
unnamed: KD18.2 (A), MX18.2
unnamed: KD19.2 (A), MX19.2
unnamed: KD20.2 (A), MX20.2
unnamed: KD21.2 (A), MX21.2
unnamed: KD22.2 (A), MX22.2
unnamed: KD23.2 (A), MX23.2
unnamed: KD24.2 (A), MX24.2
unnamed: KD25.2 (A), MX25.2
unnamed: KD26.2 (A), MX26.2
unnamed: KD27.2 (A), MX27.2
unnamed: KD28.2 (A), MX28.2
unnamed: KD29.2 (A), MX29.2
unnamed: KD30.2 (A), MX30.2
unnamed: KD31.2 (A), MX31.2
unnamed: KD32.2 (A), MX32.2
unnamed: KD33.2 (A), MX33.2
unnamed: KD34.2 (A), MX34.2
unnamed: KD35.2 (A), MX35.2
unnamed: KD36.2 (A), MX36.2
unnamed: KD37.2 (A), MX37.2
unnamed: KD38.2 (A), MX38.2
unnamed: KD39.2 (A), MX39.2
unnamed: KD40.2 (A), MX40.2
unnamed: KD41.2 (A), MX41.2
unnamed: KD42.2 (A), MX42.2
unnamed: KD43.2 (A), MX43.2
unnamed: KD44.2 (A), MX44.2
unnamed: KD45.2 (A), MX45.2
unnamed: KD46.2 (A), MX46.2
unnamed: KD47.2 (A), MX47.2
unnamed: KD48.2 (A), MX48.2
unnamed: KD49.2 (A), MX49.2
unnamed: KD50.2 (A), MX50.2
unnamed: KD51.2 (A), MX51.2
unnamed: KD52.2 (A), MX52.2
unnamed: KD53.2 (A), MX53.2
unnamed: KD54.2 (A), MX54.2
unnamed: KD55.2 (A), MX55.2
unnamed: KD56.2 (A), MX56.2
unnamed: KD57.2 (A), MX57.2
unnamed: KD58.2 (A), MX58.2
unnamed: KD59.2 (A), MX59.2
unnamed: KD60.2 (A), MX60.2
unnamed: KD61.2 (A), MX61.2
unnamed: KD62.2 (A), MX62.2
unnamed: KD63.2 (A), MX63.2
unnamed: KD64.2 (A), MX64.2
unnamed: KD65.2 (A), MX65.2
unnamed: KD66.2 (A), MX66.2
unnamed: KD67.2 (A), MX67.2
unnamed: KD68.2 (A), MX68.2
unnamed: KD69.2 (A), MX69.2
unnamed: KD70.2 (A), MX70.2
unnamed: KD71.2 (A), MX71.2
unnamed: KD72.2 (A), MX72.2
unnamed: KD73.2 (A), MX73.2
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

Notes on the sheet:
Keyboard Controller
USB Hub Controller
USB Hub Indicators
USB Input
USB Hub EEPROM
USB A Outputs
USB C Outputs
USB Output 3
USB Output 4
USB Output 6
USB Output 2
USB Output 5
USB Output 7
USB Downstream Power
USB Hub Crystal
USB Hub
Circuit Breaker
LED Fuse
Keyboard Reset
LED 3.3V to 5V
Keyboard 3.3v
Mounting Holes
Keyboard OLED
Keyboard Interface
Rotary Encoder 1
Rotary Encoder 2
Keyboard Crystals
Keyboard Encoders
Keyboard Matrix

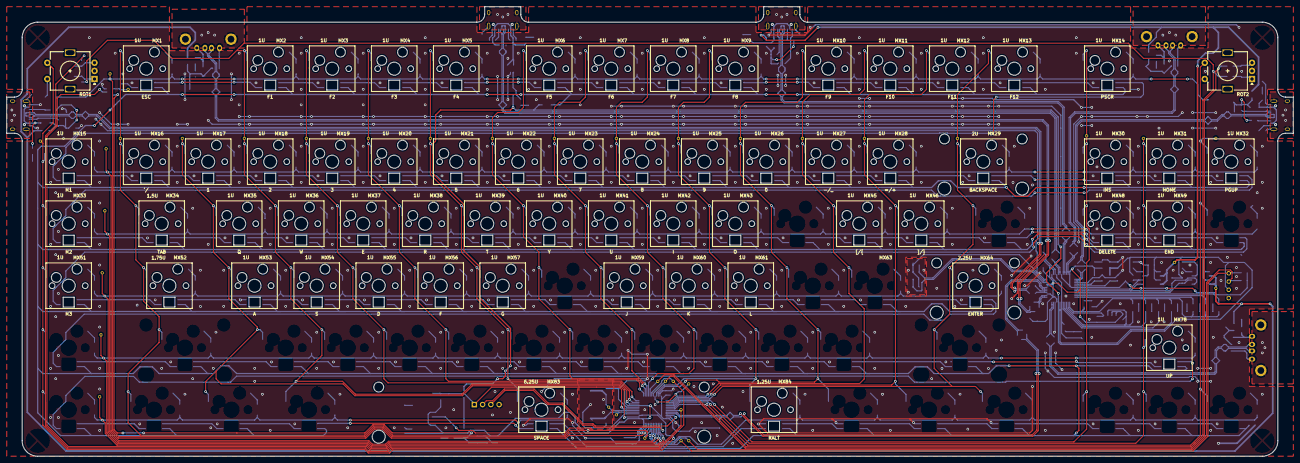
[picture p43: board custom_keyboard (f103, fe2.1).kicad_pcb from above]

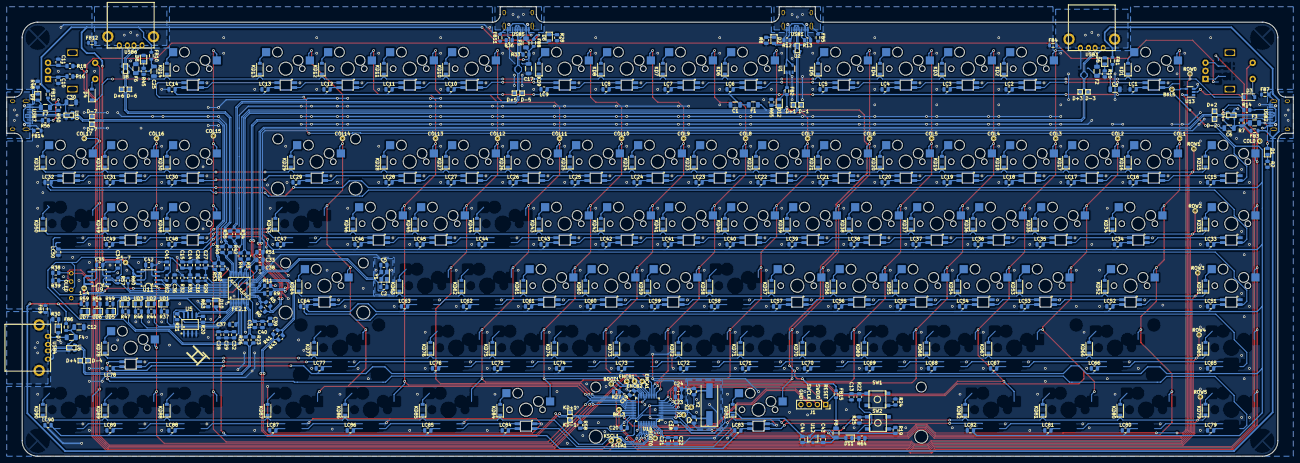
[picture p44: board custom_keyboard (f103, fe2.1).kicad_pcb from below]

Board: 2 copper layers, 395.3 x 138.1 mm, 468 parts (403 on the bottom side), 257 nets.

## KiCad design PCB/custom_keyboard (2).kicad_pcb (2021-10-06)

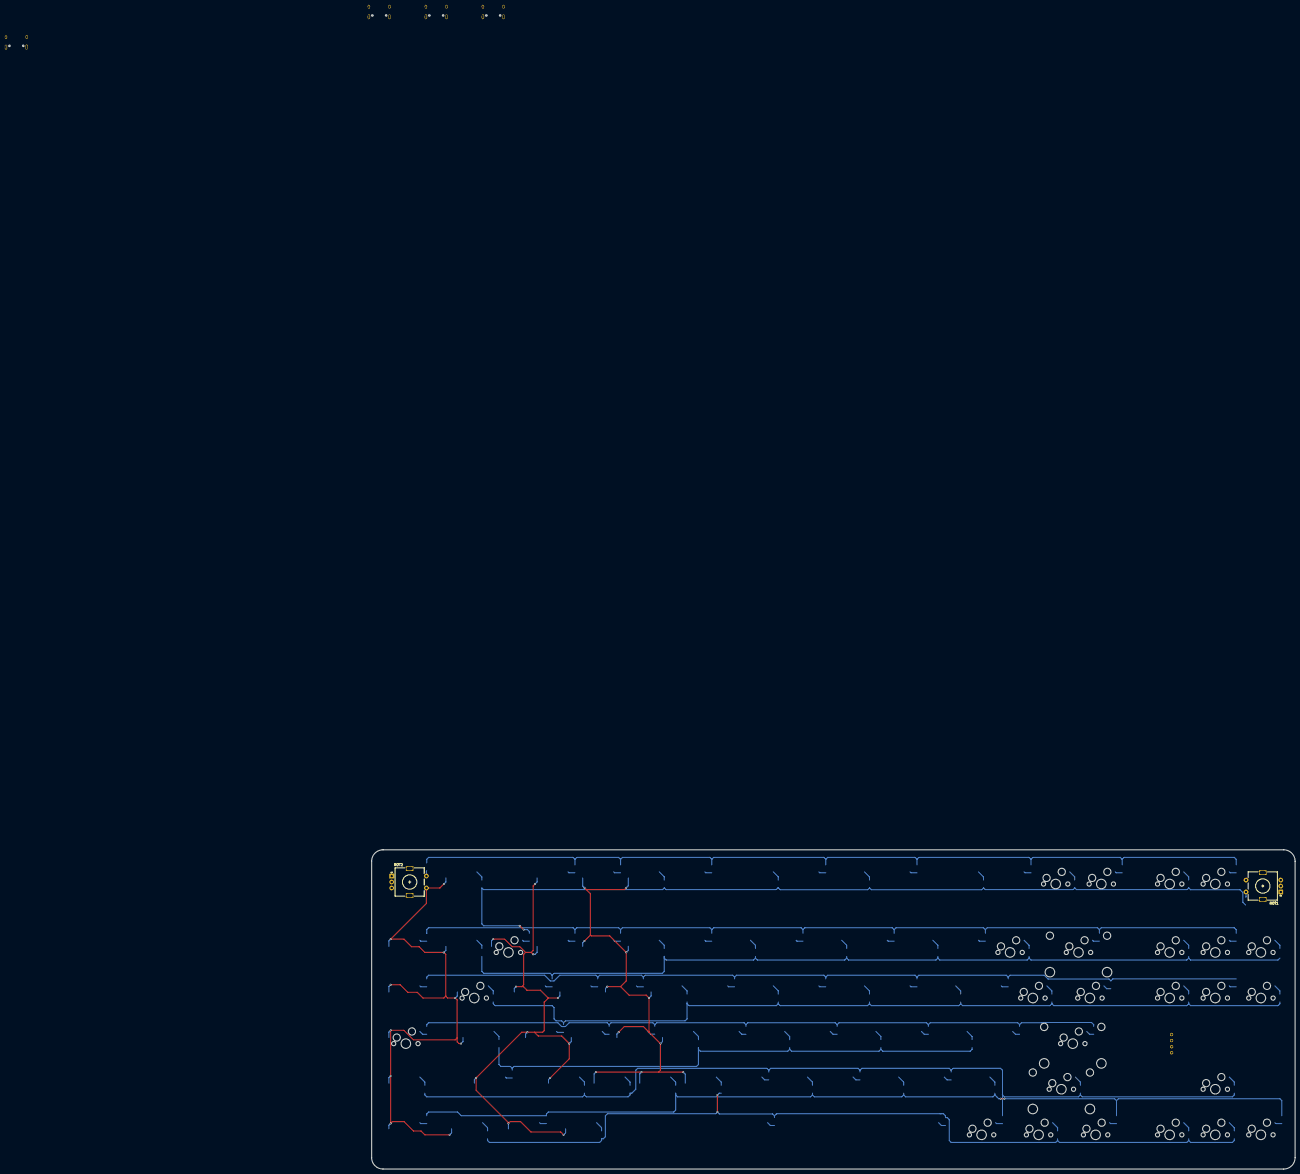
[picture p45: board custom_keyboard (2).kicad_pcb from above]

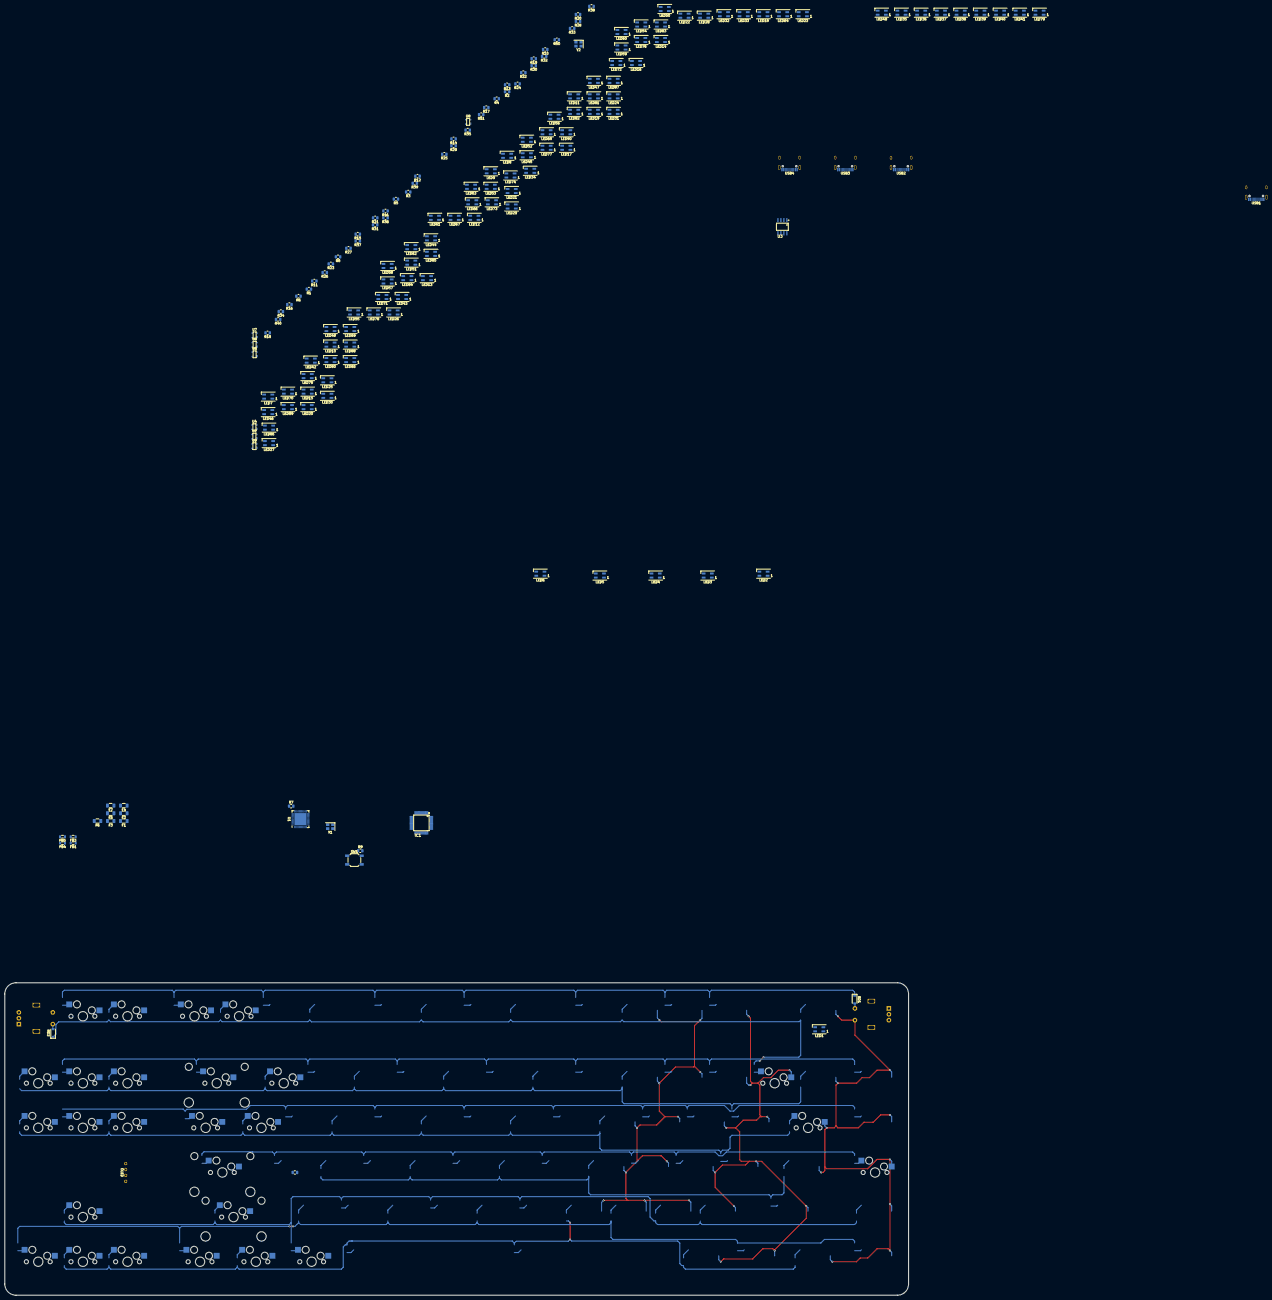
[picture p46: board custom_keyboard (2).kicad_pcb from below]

Board: 2 copper layers, 385.7 x 133.3 mm, 193 parts (164 on the bottom side), 171 nets.

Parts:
F1, F2, F3, F4, F5, F6, F7: 500mA; Fuse_1206_3216Metric
FB1, FB3, FB4, FB5: 60 @ 100MHz; L_0805_2012Metric
IC1: FE2.1
LED1, LED2, LED3, LED4, LED5, LED6, LED7, LED8, LED9, LED10, LED11, LED12, LED13, LED14, LED15, LED16, LED17, LED18, LED19, LED20, LED21, LED22, LED23, LED24, LED25, LED26, LED27, LED28, LED29, LED30, LED31, LED32, LED33, LED34, LED35, LED36, LED37, LED38, LED39, LED40, LED41, LED42, LED43, LED44, LED45, LED46, LED47, LED48, LED49, LED50, LED51, LED52, LED53, LED54, LED55, LED56, LED57, LED58, LED59, LED60, LED61, LED62, LED63, LED64, LED65, LED66, LED67, LED68, LED69, LED70, LED71, LED72, LED73, LED74, LED75, LED76, LED77, LED78, LED79, LED80, LED81, LED82, LED83, LED84, LED85, LED86, LED87, LED88, LED89, LED90: WS2812B; LED_SK6812MINI_PLCC4_3.5x3.5mm_P1.75mm
MX3: M3; MXOnly-1U-Hotswap
MX8: TAB; MXOnly-1.5U-Hotswap
MX17: 1; MXOnly-1U-Hotswap
MX68: '/; MXOnly-1U-Hotswap
MX69: RGUI; MXOnly-1.25U-Hotswap
MX70: MENU; MXOnly-1.25U-Hotswap
MX71: F11; MXOnly-1U-Hotswap
MX72: =/+; MXOnly-1U-Hotswap
MX73: ]/}; MXOnly-1U-Hotswap
MX74: RCTRL; MXOnly-1.25U-Hotswap
MX75: F12; MXOnly-1U-Hotswap
MX76: BACKSPACE; MXOnly-2U-Hotswap
MX77: \; MXOnly-1.5U-Hotswap
MX78: ENTER; MXOnly-2.25U-Hotswap
MX79: RSHIFT; MXOnly-2.75U-Hotswap
MX80: LEFT; MXOnly-1U-Hotswap
MX81: PSCR; MXOnly-1U-Hotswap
MX82: INS; MXOnly-1U-Hotswap
MX83: DELETE; MXOnly-1U-Hotswap
MX84: SCLCK; MXOnly-1U-Hotswap
MX85: HOME; MXOnly-1U-Hotswap
MX86: END; MXOnly-1U-Hotswap
MX87: UP; MXOnly-1U-Hotswap
MX88: DOWN; MXOnly-1U-Hotswap
MX89: PGUP; MXOnly-1U-Hotswap
MX90: PGDN; MXOnly-1U-Hotswap
MX91: RIGHT; MXOnly-1U-Hotswap
OL1: OLED; OLED_v2
R1: 500; R_0805_2012Metric
R2, R3, R6, R7, R8, R9, R14: 10k; R_0805_2012Metric
R4, R5, R12, R13, R32, R33, R34, R35, R36, R37, R38, R39, R40, R41, R50, R51: 22; R_0805_2012Metric
R10, R16, R25, R26, R28, R29, R30, R31: 5.1K; R_0805_2012Metric
R11, R15: 100k; R_0805_2012Metric
R17, R18, R19, R20, R21, R22, R23, R24: 330; R_0805_2012Metric
R27: 2.7k; R_0805_2012Metric
RD1, RD2: SOD-123; D_SOD-123
ROT1, ROT2: Rotary_Encoder_Switch; RotaryEncoder_Alps_EC11E-Switch_Vertical_H20mm
SW1: SW_Push; SW_SPST_SKQG_WithStem
U1: ATmega32U4-MU; QFN-44-1EP_7x7mm_P0.5mm_EP5.2x5.2mm
U2, U4, U5, U6, U7, U8, U9: PRTR5V0U2X; SOT143B
U3: 24LC02; 24LC04
USB1, USB2, USB3, USB4: HRO-TYPE-C-31-M-12; HRO-TYPE-C-31-M-12-Assembly
Y1: 16MHz; Crystal_SMD_3225-4Pin_3.2x2.5mm
Y2: 12MHz; Crystal_SMD_3225-4Pin_3.2x2.5mm

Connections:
+1V8: IC1.6, IC1.21, IC1.25, IC1.28
+3V3: IC1.9, IC1.15, IC1.20, IC1.26, IC1.31, IC1.36, IC1.42, IC1.43, IC1.45, R11.1, U3.7, U3.8
+5V: F1.1, F2.1, F3.1, F4.1, F5.1, F6.1, F7.1, IC1.8, LED1.1, LED2.1, LED3.1, LED4.1, LED5.1, LED6.1, LED7.1, LED8.1, LED9.1, LED10.1, LED11.1, LED12.1, LED13.1, LED14.1, LED15.1, LED16.1, LED17.1, LED18.1, LED19.1, LED20.1, LED21.1, LED22.1, LED23.1, LED24.1, LED25.1, LED26.1, LED27.1, LED28.1, LED29.1, LED30.1, LED31.1, LED32.1, LED33.1, LED34.1, LED35.1, LED36.1, LED37.1, LED38.1, LED39.1, LED40.1, LED41.1, LED42.1, LED43.1, LED44.1, LED45.1, LED46.1, LED47.1, LED48.1, LED49.1, LED50.1, LED51.1, LED52.1, LED53.1, LED54.1, LED55.1, LED56.1, LED57.1, LED58.1, LED59.1, LED60.1, LED61.1, LED62.1, LED63.1, LED64.1, LED65.1, LED66.1, LED67.1, LED68.1, LED69.1, LED70.1, LED71.1, LED72.1, LED73.1, LED74.1, LED75.1, LED76.1, LED77.1, LED78.1, LED79.1, LED80.1, LED81.1, LED82.1, LED83.1, LED84.1, LED85.1, LED86.1, LED87.1, LED88.1, LED89.1, LED90.1, MX68.1, OL1.3, R9.1, R14.1, U1.2, U1.7, U1.14, U1.24, U1.34, U1.44
BKL_DATA_IN: R1.2, U1.1
COL0: MX3.1, MX8.1, ROT2.S1, U1.8
COL1: MX17.1, U1.9
COL6: MX69.1, MX70.1, MX71.1, MX72.1, MX73.1, MX74.1, U1.21
COL7: MX75.1, MX76.1, MX77.1, MX78.1, MX79.1, MX80.1, MX81.1, MX82.1, MX83.1, U1.22
COL8: MX84.1, MX85.1, MX86.1, MX87.1, MX88.1, MX89.1, MX90.1, MX91.1, ROT1.S1, U1.25
DOUT1: LED2.2, LED82.4
DOUT2: LED3.2, LED83.4
DOUT3: LED4.2, LED84.4
DOUT4: LED5.2, LED85.4
DOUT5: LED6.2, LED86.4
DOUT6: LED7.2, LED87.4
DOUT7: LED8.2, LED88.4
DOUT8: LED9.2, LED89.4
ENCODER_A: R2.2, R6.2
ENCODER_B1: R3.1, R8.1, U1.40
Earth: FB1.1, FB3.1, FB4.2, FB5.2, USB1.13, USB2.13, USB3.13, USB4.13
GND: FB1.2, FB3.2, FB4.1, FB5.1, IC1.10, IC1.24, IC1.39, LED1.3, LED2.3, LED3.3, LED4.3, LED5.3, LED6.3, LED7.3, LED8.3, LED9.3, LED10.3, LED11.3, LED12.3, LED13.3, LED14.3, LED15.3, LED16.3, LED17.3, LED18.3, LED19.3, LED20.3, LED21.3, LED22.3, LED23.3, LED24.3, LED25.3, LED26.3, LED27.3, LED28.3, LED29.3, LED30.3, LED31.3, LED32.3, LED33.3, LED34.3, LED35.3, LED36.3, LED37.3, LED38.3, LED39.3, LED40.3, LED41.3, LED42.3, LED43.3, LED44.3, LED45.3, LED46.3, LED47.3, LED48.3, LED49.3, LED50.3, LED51.3, LED52.3, LED53.3, LED54.3, LED55.3, LED56.3, LED57.3, LED58.3, LED59.3, LED60.3, LED61.3, LED62.3, LED63.3, LED64.3, LED65.3, LED66.3, LED67.3, LED68.3, LED69.3, LED70.3, LED71.3, LED72.3, LED73.3, LED74.3, LED75.3, LED76.3, LED77.3, LED78.3, LED79.3, LED80.3, LED81.3, LED82.3, LED83.3, LED84.3, LED85.3, LED86.3, LED87.3, LED88.3, LED89.3, LED90.3, MX68.2, OL1.4, R7.1, R10.1, R15.2, R16.1, R24.1, R25.1, R26.1, R27.1, R28.1, R29.1, R30.1, R31.1, ROT1.C, ROT2.C, SW1.2, U1.5, U1.15, U1.23, U1.35, U1.43, U1.45, U2.1, U3.1, U3.2, U3.3, U3.4, U4.1, U5.1, U6.1, U7.1, U8.1, U9.1, USB1.1, USB1.12, USB2.1, USB2.12, USB3.1, USB3.12, USB4.1, USB4.12, Y1.2, Y1.4, Y2.2, Y2.4
HUB_D+: IC1.30, R12.2
HUB_D-: IC1.29, R13.2
HUB_LED1: IC1.3, R17.2, U3.6
HUB_LED2: IC1.4, R18.2
HUB_LED3: IC1.5, R19.2
HUB_LED4: IC1.7, R20.2
HUB_LED5: IC1.48, R21.2
HUB_LED6: IC1.47, R22.2
HUB_LED7: IC1.46, R23.2
HUB_PORT2_D+: IC1.17, R38.2
HUB_PORT2_D-: IC1.16, R39.2
HUB_PORT3_D+: IC1.14, R40.2
HUB_PORT3_D-: IC1.13, R41.2
HUB_PORT4_D+: IC1.12, R50.2
HUB_PORT4_D-: IC1.11, R51.2
HUB_PORT5_D+: IC1.33, R33.2
HUB_PORT5_D-: IC1.32, R32.2
HUB_PORT6_D+: IC1.35, R35.2
HUB_PORT6_D-: IC1.34, R34.2
HUB_PORT7_D+: IC1.38, R37.2
HUB_PORT7_D-: IC1.37, R36.2
HUB_SDA: IC1.2, U3.5
HUB_XIN: IC1.22, Y2.1
HUB_XOUT: IC1.23, Y2.3
KEYBOARD_D+: IC1.19, R4.1
KEYBOARD_D-: IC1.18, R5.2
KEYBOARD_RESET: R9.2, SW1.1, U1.13
KEYBOARD_SCL: OL1.1, U1.18
KEYBOARD_SDA: OL1.2, U1.19
KEYBOARD_XTAL1: U1.17, Y1.1
KEYBOARD_XTAL2: U1.16, Y1.3
unnamed: R2.1, ROT2.A
unnamed: R3.2, ROT2.B
unnamed: R6.1, ROT1.A
unnamed: R8.2, ROT1.B
unnamed: IC1.27, R27.2
unnamed: R39.1, U4.3
unnamed: R38.1, U4.2
unnamed: R41.1, U5.3
unnamed: R40.1, U5.2
unnamed: R51.1, U6.3
unnamed: R50.1, U6.2
unnamed: LED1.2, R1.1
unnamed: LED1.4, LED10.2
unnamed: LED10.4, LED19.2
unnamed: LED2.4, LED11.2
unnamed: LED11.4, LED20.2
unnamed: LED3.4, LED12.2
unnamed: LED12.4, LED21.2
unnamed: LED4.4, LED13.2
unnamed: LED13.4, LED22.2
unnamed: LED5.4, LED14.2
unnamed: LED14.4, LED23.2
unnamed: LED6.4, LED15.2
unnamed: LED15.4, LED24.2
unnamed: LED7.4, LED16.2
unnamed: LED16.4, LED25.2
unnamed: LED8.4, LED17.2
unnamed: LED17.4, LED26.2
unnamed: LED9.4, LED18.2
unnamed: LED18.4, LED27.2
unnamed: LED19.4, LED28.2
unnamed: LED20.4, LED29.2
unnamed: LED21.4, LED30.2
unnamed: LED22.4, LED31.2
unnamed: LED23.4, LED32.2
unnamed: LED24.4, LED33.2
unnamed: LED25.4, LED34.2
unnamed: LED26.4, LED35.2
unnamed: LED27.4, LED36.2
unnamed: LED28.4, LED37.2
unnamed: LED29.4, LED38.2
unnamed: LED30.4, LED39.2
unnamed: LED31.4, LED40.2
unnamed: LED32.4, LED41.2
unnamed: LED33.4, LED42.2
unnamed: LED34.4, LED43.2
unnamed: LED35.4, LED44.2
unnamed: LED36.4, LED45.2
unnamed: LED37.4, LED46.2
unnamed: LED38.4, LED47.2
unnamed: LED39.4, LED48.2
unnamed: LED40.4, LED49.2
unnamed: LED41.4, LED50.2
unnamed: LED42.4, LED51.2
unnamed: LED43.4, LED52.2
unnamed: LED44.4, LED53.2
unnamed: LED45.4, LED54.2
unnamed: LED46.4, LED55.2
unnamed: LED47.4, LED56.2
unnamed: LED48.4, LED57.2
unnamed: LED49.4, LED58.2
unnamed: LED50.4, LED59.2
unnamed: LED51.4, LED60.2
unnamed: LED52.4, LED61.2
unnamed: LED53.4, LED62.2
unnamed: LED54.4, LED63.2
unnamed: LED55.4, LED64.2
unnamed: LED56.4, LED65.2
unnamed: LED57.4, LED66.2
unnamed: LED58.4, LED67.2
unnamed: LED59.4, LED68.2
unnamed: LED60.4, LED69.2
unnamed: LED61.4, LED70.2
unnamed: LED62.4, LED71.2
unnamed: LED63.4, LED72.2
unnamed: LED64.4, LED73.2
unnamed: LED65.4, LED74.2
unnamed: LED66.4, LED75.2
unnamed: LED67.4, LED76.2
unnamed: LED68.4, LED77.2
unnamed: LED69.4, LED78.2
unnamed: LED70.4, LED79.2
unnamed: LED71.4, LED80.2
unnamed: LED72.4, LED81.2
unnamed: LED73.4, LED82.2
unnamed: LED74.4, LED83.2
unnamed: LED75.4, LED84.2
unnamed: LED76.4, LED85.2
unnamed: LED77.4, LED86.2
unnamed: LED78.4, LED87.2
unnamed: LED79.4, LED88.2
unnamed: LED80.4, LED89.2
unnamed: LED81.4, LED90.2
unnamed: R4.2, U1.4
unnamed: R5.1, U1.3
unnamed: R7.2, U1.33
unnamed: R10.2, USB2.10
unnamed: R12.1, U2.2, USB1.6
unnamed: R13.1, U2.3, USB1.5, USB1.7, USB1.8
unnamed: R16.2, USB3.10
unnamed: R25.2, USB1.10
unnamed: R26.2, USB1.4
unnamed: R28.2, USB4.10
unnamed: R29.2, USB2.4
unnamed: R30.2, USB3.4
unnamed: R31.2, USB4.4
unnamed: R32.1, U7.3, USB2.5, USB2.7, USB2.8
unnamed: R33.1, U7.2, USB2.6
unnamed: R34.1, U8.3, USB3.5, USB3.7, USB3.8
unnamed: R35.1, U8.2, USB3.6
unnamed: R36.1, U9.3, USB4.5, USB4.7, USB4.8
unnamed: R37.1, U9.2, USB4.6
unnamed: RD1.2, ROT2.S2
unnamed: RD2.2, ROT1.S2
ROT1_ROW: RD2.1, U1.38, U1.41
ROT2_ROW: RD1.1, U1.39
VBUSM: IC1.41, R14.2, R15.1
VCC: F1.2, F2.2, F3.2, F4.2, F5.2, F6.2, F7.2, U2.4, U4.4, U5.4, U6.4, U7.4, U8.4, U9.4, USB1.2, USB1.11, USB2.2, USB2.11, USB3.2, USB3.11, USB4.2, USB4.11
XRSTJ: IC1.40, R11.2

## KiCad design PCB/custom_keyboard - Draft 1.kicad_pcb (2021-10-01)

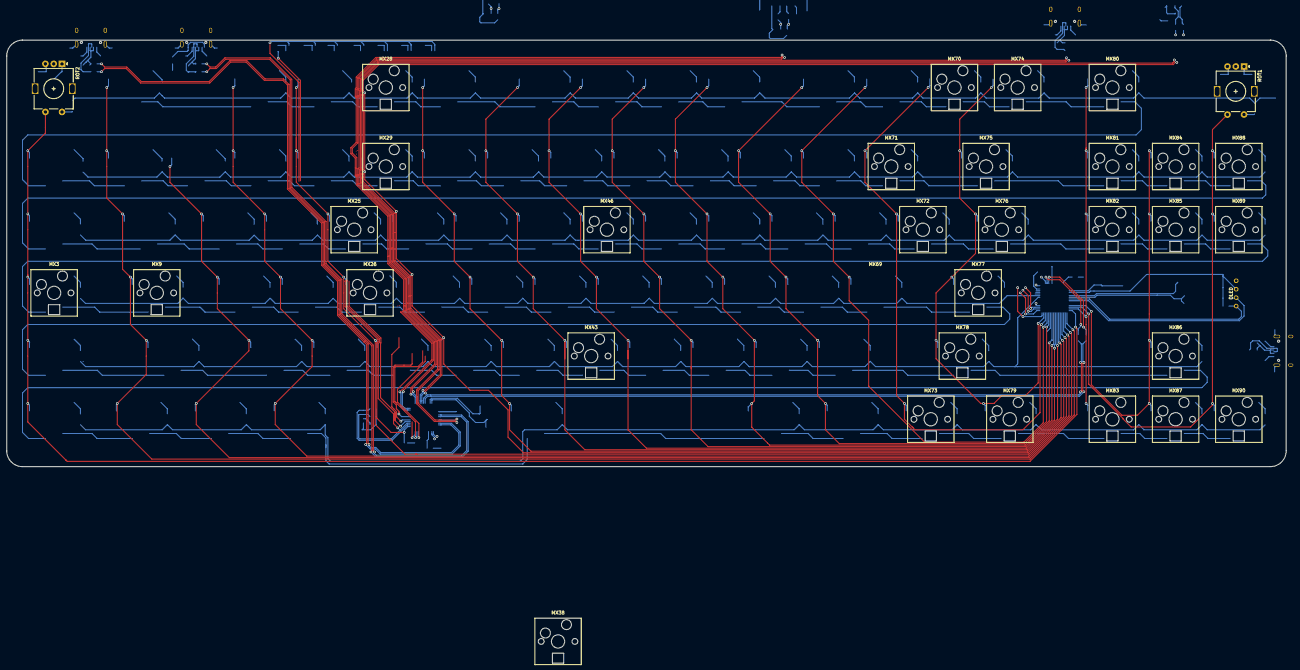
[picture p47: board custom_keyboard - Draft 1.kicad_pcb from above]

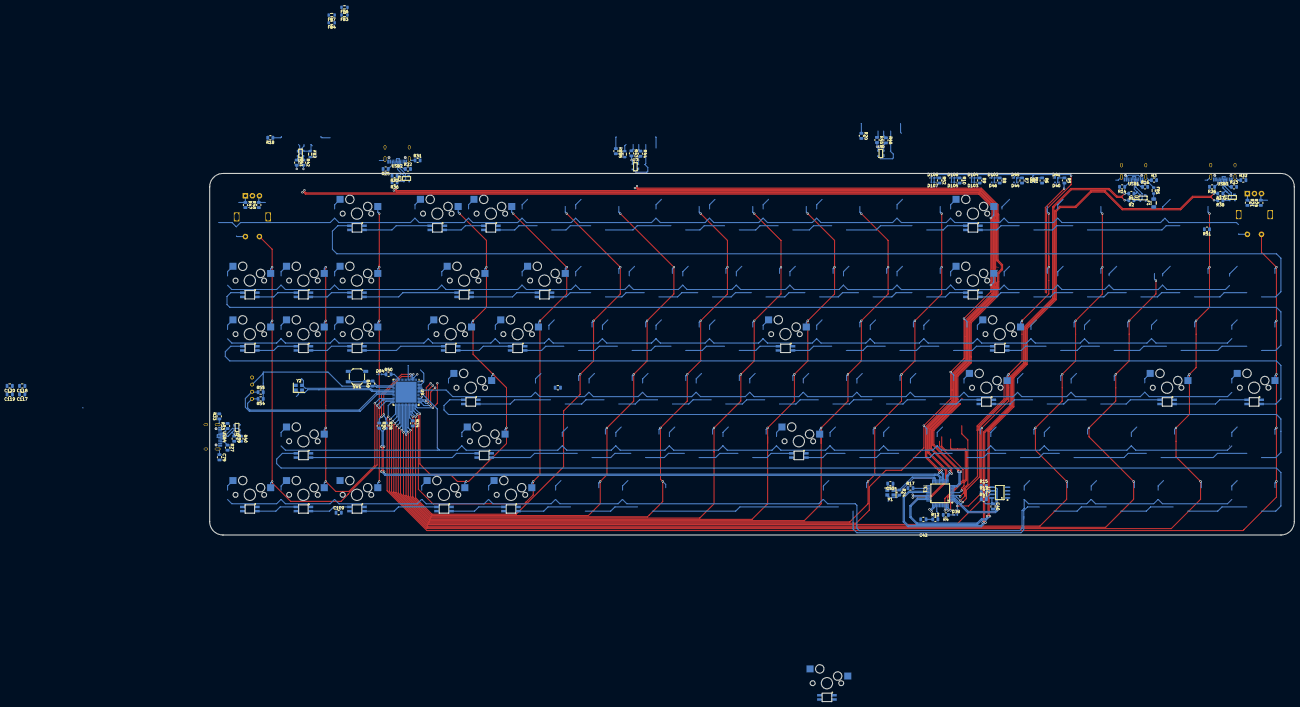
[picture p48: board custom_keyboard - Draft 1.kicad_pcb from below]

Board: 2 copper layers, 385.8 x 128.6 mm, 139 parts (105 on the bottom side), 120 nets.

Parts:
C40, C42, C79, C109, C117, C118, C119: 0.1uF; C_0805_2012Metric
C53: 20pF; C_0805_2012Metric
C120: 10uF; C_0805_2012Metric
D39: Red; LED_0402_1005Metric
D40, D42, D44, D46, D103, D105, D107: Green; LED_0402_1005Metric
D41, D43, D45, D102, D104, D106, D108: Amber; LED_0402_1005Metric
D84: Yellow; LED_0402_1005Metric
F1: 4A; Fuse_1206_3216Metric
FB1, FB2, FB3, FB4, FB5, FB6, FB7: 3A; L_0805_2012Metric
IC1: FE2.1
MX3: M3; CherryMX_1.00u_PCB_KailhSocket_LTST-A683CEGBW
MX9: CAPS; CherryMX_1.75u_PCB_KailhSocket_LTST-A683CEGBW
MX25: E; CherryMX_1.00u_PCB_KailhSocket_LTST-A683CEGBW
MX26: D; CherryMX_1.00u_PCB_KailhSocket_LTST-A683CEGBW
MX28: F3; CherryMX_1.00u_PCB_KailhSocket_LTST-A683CEGBW
MX29: 4; CherryMX_1.00u_PCB_KailhSocket_LTST-A683CEGBW
MX38: SPACE; CherryMX_6.25u_PCB_KailhSocket_LTST-A683CEGBW
MX43: N; CherryMX_1.00u_PCB_KailhSocket_LTST-A683CEGBW
MX46: U; CherryMX_1.00u_PCB_KailhSocket_LTST-A683CEGBW
MX69: '/; CherryMX_1.00u_PCB_KailhSocket_LTST-A683CEGBW
MX70: F11; CherryMX_1.00u_PCB_KailhSocket_LTST-A683CEGBW
MX71: =/+; CherryMX_1.00u_PCB_KailhSocket_LTST-A683CEGBW
MX72: ]/}; CherryMX_1.00u_PCB_KailhSocket_LTST-A683CEGBW
MX73: MENU; CherryMX_1.25u_PCB_KailhSocket_LTST-A683CEGBW
MX74: F12; CherryMX_1.00u_PCB_KailhSocket_LTST-A683CEGBW
MX75: BACKSPACE; CherryMX_2.00u_PCB_KailhSocket_LTST-A683CEGBW
MX76: \; CherryMX_1.50u_PCB_KailhSocket_LTST-A683CEGBW
MX77: ENTER; CherryMX_2.25u_PCB_KailhSocket_LTST-A683CEGBW
MX78: RSHIFT; CherryMX_2.75u_PCB_KailhSocket_LTST-A683CEGBW
MX79: RCTRL; CherryMX_1.25u_PCB_KailhSocket_LTST-A683CEGBW
MX80: PRINT; CherryMX_1.00u_PCB_KailhSocket_LTST-A683CEGBW
MX81: INS; CherryMX_1.00u_PCB_KailhSocket_LTST-A683CEGBW
MX82: DELETE; CherryMX_1.00u_PCB_KailhSocket_LTST-A683CEGBW
MX83: LEFT; CherryMX_1.00u_PCB_KailhSocket_LTST-A683CEGBW
MX84: HOME; CherryMX_1.00u_PCB_KailhSocket_LTST-A683CEGBW
MX85: END; CherryMX_1.00u_PCB_KailhSocket_LTST-A683CEGBW
MX86: UP; CherryMX_1.00u_PCB_KailhSocket_LTST-A683CEGBW
MX87: DOWN; CherryMX_1.00u_PCB_KailhSocket_LTST-A683CEGBW
MX88: PGUP; CherryMX_1.00u_PCB_KailhSocket_LTST-A683CEGBW
MX89: PGDN; CherryMX_1.00u_PCB_KailhSocket_LTST-A683CEGBW
MX90: RIGHT; CherryMX_1.00u_PCB_KailhSocket_LTST-A683CEGBW
OL1: OLED; OLED_v2
R1, R2, R28, R30, R35, R36, R37, R38, R39, R40, R41, R42, R43, R44, R45, R46: 22; R_0805_2012Metric
R3, R4, R5, R6, R7, R8, R9, R10, R18, R19, R20, R31, R32, R33, R52: 330; R_0805_2012Metric
R11, R13, R15: 4.7k; R_0805_2012Metric
R12: 100k; R_0805_2012Metric
R14, R16, R22, R23, R25, R26, R27, R53: 5.1K; R_0805_2012Metric
R17: 2.7k; R_0805_2012Metric
R21, R29, R34, R47, R48, R49: 10k; R_0805_2012Metric
R24: 1M; R_0805_2012Metric
R50: 150; R_0805_2012Metric
R51: 500; R_0805_2012Metric
R54, R55: 20k; R_0805_2012Metric
ROT1, ROT2: Rotary_Encoder_Switch; RotaryEncoder_Alps_EC11E-Switch_Vertical_H20mm
SW1: SW_Push; SW_SPST_SKQG_WithStem
U1, U3, U4, U5, U6, U7, U8: PRTR5V0U2X; SOT143B
U2: 24LC02; 24LC04
U9: AT90USB646-MU; QFN-64-1EP_9x9mm_P0.5mm_EP7.5x7.5mm
USB1: USB IN; HRO-TYPE-C-31-M-12
USB2, USB3, USB4: HRO-TYPE-C-31-M-12
Y1: 12MHz; Crystal_SMD_3225-4Pin_3.2x2.5mm
Y2: 16MHz; Crystal_SMD_3225-4Pin_3.2x2.5mm

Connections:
+1V8: IC1.6, IC1.21, IC1.25, IC1.28
+3V3: C40.1, C42.1, IC1.9, IC1.15, IC1.20, IC1.26, IC1.31, IC1.36, IC1.42, IC1.43, IC1.45, R11.1, R12.1, R13.1, R15.1, U2.8
+5V: C109.2, C117.1, C118.1, C119.1, C120.1, F1.1, FB2.2, FB4.2, FB6.2, IC1.8, IC1.41, MX3.6, MX9.6, MX25.6, MX26.6, MX28.6, MX29.6, MX38.6, MX43.6, MX46.6, MX69.2, MX70.6, MX71.6, MX72.6, MX73.6, MX74.6, MX75.6, MX76.6, MX77.6, MX78.6, MX79.6, MX80.6, MX81.6, MX82.6, MX83.6, MX84.6, MX85.6, MX86.6, MX87.6, MX88.6, MX89.6, MX90.6, OL1.3, R49.1, R54.1, R55.2, U1.4, U3.4, U4.4, U5.4, U9.3, U9.8, U9.21, U9.52, U9.64, USB2.2, USB2.11, USB3.2, USB3.11, USB4.2, USB4.11
BKL_DATA_IN: R51.1, U9.51
COL0: MX3.1, ROT2.S1, U9.32
COL1: MX9.1, U9.33
COL4: MX25.1, MX26.1, U9.36
COL5: MX28.1, MX29.1, U9.37
COL6: MX38.1, U9.38
COL7: MX43.1, U9.39
COL8: MX46.1, U9.40
COL13: MX70.1, MX71.1, MX72.1, MX73.1, U9.46
COL14: MX74.1, MX75.1, MX76.1, MX77.1, MX78.1, MX79.1, U9.47
COL15: MX80.1, MX81.1, MX82.1, MX83.1, U9.31
COL16: MX84.1, MX85.1, MX86.1, MX87.1, U9.29
COL17: MX88.1, MX89.1, MX90.1, ROT1.S1, U9.30
DOUT3: MX3.4, MX89.5
ENCODER_A: R21.2, R47.2
ENCODER_B1: R48.1, U9.50
ENCODER_B2: R29.1, U9.48
GND: C40.2, C42.2, C53.2, C79.2, C109.1, C117.2, C118.2, C119.2, C120.2, D84.1, FB3.1, FB5.1, FB7.1, IC1.10, IC1.24, IC1.39, MX3.3, MX9.3, MX25.3, MX26.3, MX28.3, MX29.3, MX38.3, MX43.3, MX46.3, MX69.1, MX70.3, MX71.3, MX72.3, MX73.3, MX74.3, MX75.3, MX76.3, MX77.3, MX78.3, MX79.3, MX80.3, MX81.3, MX82.3, MX83.3, MX84.3, MX85.3, MX86.3, MX87.3, MX88.3, MX89.3, MX90.3, OL1.4, R3.2, R4.2, R14.2, R16.2, R17.1, R18.2, R19.2, R20.2, R22.2, R23.2, R25.2, R26.2, R27.2, R31.2, R32.2, R33.2, R34.2, R53.2, ROT1.C, ROT2.C, SW1.2, U1.1, U2.1, U2.2, U2.3, U2.4, U3.1, U4.1, U5.1, U6.1, U7.1, U8.1, U9.6, U9.22, U9.53, U9.63, U9.65, USB1.1, USB1.12, USB2.1, USB2.12, USB3.1, USB3.12, USB4.1, USB4.12, Y1.2, Y1.4, Y2.2, Y2.4
HUB_D+: IC1.30, R1.2
HUB_D-: IC1.29, R2.2
HUB_DRV: D39.2, D40.2, D41.1, D42.2, D43.1, D44.2, D45.1, D46.2, D102.1, D103.2, D104.1, D105.2, D106.1, D107.2, D108.1, IC1.1
HUB_LED1: IC1.3, R5.2, R13.2, U2.6
HUB_LED2: IC1.4, R6.2
HUB_LED3: IC1.5, R7.2
HUB_LED4: IC1.7, R8.2
HUB_LED5: IC1.48, R9.2
HUB_LED6: IC1.47, R10.2
HUB_LED7: IC1.46, R52.2
HUB_PORT2_D+: IC1.17, R41.2
HUB_PORT2_D-: IC1.16, R42.2
HUB_PORT3_D+: IC1.14, R43.2
HUB_PORT3_D-: IC1.13, R44.2
HUB_PORT4_D+: IC1.12, R45.2
HUB_PORT4_D-: IC1.11, R46.2
HUB_PORT5_D+: IC1.33, R35.2
HUB_PORT5_D-: IC1.32, R36.2
HUB_PORT6_D+: IC1.35, R37.2
HUB_PORT6_D-: IC1.34, R38.2
HUB_PORT7_D+: IC1.38, R39.2
HUB_PORT7_D-: IC1.37, R40.2
HUB_SDA: IC1.2, R15.2, U2.5
HUB_XIN: C53.1, IC1.22, R24.1, Y1.1
HUB_XOUT: IC1.23, R24.2, Y1.3
KEYBOARD_D+: IC1.19, R30.2
KEYBOARD_D-: IC1.18, R28.2
KEYBOARD_RESET: R49.2, SW1.1, U9.20
KEYBOARD_SCL: OL1.1, R54.2, U9.25
KEYBOARD_SDA: OL1.2, R55.1, U9.26
KEYBOARD_SIGNAL: R50.2, U9.14
KEYBOARD_XTAL1: U9.24, Y2.1
KEYBOARD_XTAL2: U9.23, Y2.3
unnamed: R3.1, USB1.13
unnamed: R21.1, ROT2.A
unnamed: R29.2, ROT2.B
unnamed: R31.1, USB2.13
unnamed: R32.1, USB3.13
unnamed: C79.1, R33.1, USB4.13
unnamed: R47.1, ROT1.A
unnamed: R48.2, ROT1.B
unnamed: D39.1, R4.1
unnamed: D40.1, D41.2, R5.1
unnamed: D42.1, D43.2, R6.1
unnamed: D44.1, D45.2, R7.1
unnamed: D84.2, R50.1
unnamed: D46.1, D102.2, R8.1
unnamed: D103.1, D104.2, R9.1
unnamed: D105.1, D106.2, R10.1
unnamed: D107.1, D108.2, R52.1
unnamed: FB1.1, USB1.2, USB1.11
unnamed: FB2.1, U6.4
unnamed: FB4.1, U7.4
unnamed: FB6.1, U8.4
unnamed: IC1.27, R17.2
unnamed: IC1.40, R12.2
unnamed: R42.1, U6.3
unnamed: R41.1, U6.2
unnamed: R44.1, U7.3
unnamed: R43.1, U7.2
unnamed: R46.1, U8.3
unnamed: R45.1, U8.2
unnamed: MX3.5, MX9.4
unnamed: MX70.5, MX74.4
unnamed: MX71.5, MX75.4
unnamed: MX72.5, MX76.4
unnamed: MX73.5, MX79.4
unnamed: MX74.5, MX80.4
unnamed: MX75.5, MX81.4
unnamed: MX76.5, MX82.4
unnamed: MX78.5, MX86.4
unnamed: MX79.5, MX83.4
unnamed: MX81.5, MX84.4
unnamed: MX82.5, MX85.4
unnamed: MX83.5, MX87.4
unnamed: MX84.5, MX88.4
unnamed: MX85.5, MX89.4
unnamed: MX87.5, MX90.4
unnamed: R1.1, U1.2, USB1.6, USB1.8
unnamed: R2.1, U1.3, USB1.5, USB1.7
unnamed: R11.2, U2.7
unnamed: R14.1, USB1.10
unnamed: R16.1, USB1.4
unnamed: R22.1, USB2.4
unnamed: R23.1, USB3.4
unnamed: R25.1, USB2.10
unnamed: R26.1, USB3.10
unnamed: R27.1, USB4.10
unnamed: R28.1, U9.4
unnamed: R30.1, U9.5
unnamed: R34.1, U9.43
unnamed: R35.1, U3.2, USB2.6, USB2.8
unnamed: R36.1, U3.3, USB2.5, USB2.7
unnamed: R37.1, U4.2, USB3.6, USB3.8
unnamed: R38.1, U4.3, USB3.5, USB3.7
unnamed: R39.1, U5.2, USB4.6, USB4.8
unnamed: R40.1, U5.3, USB4.5, USB4.7
unnamed: R53.1, USB4.4
VCC: F1.2, FB1.2

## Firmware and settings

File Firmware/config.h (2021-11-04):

/*
Copyright 2021 Howard Tseng

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
You should have received a copy of the GNU General Public License
along with this program.  If not, see <http://www.gnu.org/licenses/>.
*/

#pragma once

#include "config_common.h"

/* USB Device descriptor parameter */
#define VENDOR_ID    0x1234
#define PRODUCT_ID   0x5678
#define DEVICE_VER   0x0000
#define MANUFACTURER Howard Tseng
#define PRODUCT      keyboard0
#define DESCRIPTION  keyboard0 by ht12345

/* key matrix size */
#define MATRIX_ROWS 6
#define MATRIX_COLS 18

/*
 * Keyboard Matrix Assignments
 *
 * Change this to how you wired your keyboard
 * COLS: AVR pins used for columns, left to right
 * ROWS: AVR pins used for rows, top to bottom
 * DIODE_DIRECTION: COL2ROW = COL = Anode (+), ROW = Cathode (-, marked on diode)
 *                  ROW2COL = ROW = Anode (+), COL = Cathode (-, marked on diode)
 *
 */

#define MATRIX_ROW_PINS { B9, B8, B5, B4, B3, A15 }
#define MATRIX_COL_PINS { C14, C15, C13, A0, A1, A2, A3, A4, A5, A6, B10, B11, B12, B13, B14, B15, A8, A9 }
#define UNUSED_PINS { A13, A14 }

/* COL2ROW, ROW2COL */
#define DIODE_DIRECTION COL2ROW

/* define if matrix has ghost */
//#define MATRIX_HAS_GHOST

/* Set 0 if debouncing isn't needed */
#define DEBOUNCE    5

/* Mechanical locking support. Use KC_LCAP, KC_LNUM or KC_LSCR instead in keymap */
#define LOCKING_SUPPORT_ENABLE
/* Locking resynchronize hack */
#define LOCKING_RESYNC_ENABLE

/* Encoder port configurator */
#define ENCODERS_PAD_A { A7, A7 }
#define ENCODERS_PAD_B { B0, B1 }
// #define ENCODER_DIRECTION_FLIP
#define ENCODER_RESOLUTION 4

#define RGB_DI_PIN A10
#ifdef RGB_DI_PIN
  #define RGBLED_NUM 90
  #define RGBLIGHT_HUE_STEP 8
  #define RGBLIGHT_SAT_STEP 8
  #define RGBLIGHT_VAL_STEP 8
  #define RGBLIGHT_LIMIT_VAL 255 /* The maximum brightness level */
  #define RGBLIGHT_SLEEP  /* If defined, the RGB lighting will be switched off when the host goes to sleep */
  #define RGBLIGHT_ANIMATIONS
#endif

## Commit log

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2021-09-27 Corrected most electrical rules checks
    [custom_keyboard.sch]
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2021-09-29 Assigned footprints to alternate schematic
    [custom_keyboard - Copy.sch]
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2021-09-29 Placed resistors and capacitators
    [custom_keyboard.kicad_pcb]
2021-09-30 Halfway done USB ports
    [custom_keyboard.kicad_pcb, custom_keyboard.sch]
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2021-10-01 Organized USB Hub location
    [custom_keyboard.sch]
2021-10-01 Connected controller to columns
    [custom_keyboard.kicad_pcb, custom_keyboard.sch]
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2021-10-01 Routed some of the USB lanes
    [custom_keyboard.kicad_pcb]
2021-10-01 Copied to another file
    [custom_keyboard - Draft 1.kicad_pcb, custom_keyboard - Draft 1.sch]
2021-10-01 LEDs routed, removed 1 USB port
    [custom_keyboard.kicad_pcb, custom_keyboard.sch]
2021-10-01 Moved USB hub to top, made top gap 0.5u
    [custom_keyboard.kicad_pcb, custom_keyboard.sch]
2021-10-01 Connected all USB ports to hub
    [custom_keyboard.kicad_pcb, custom_keyboard.sch]
2021-10-02 State before deleting all traces
    [custom_keyboard.kicad_pcb, custom_keyboard.sch]
2021-10-02 Copy with duplex matrix
    [custom_keyboard (2).sch]
2021-10-02 Relabeled keyboard and LED matrix
    [custom_keyboard (2).sch]
2021-10-04 Updated USB hub schematic
    [custom_keyboard (2).sch]
2021-10-05 Creating copy to use with STM32
    [custom_keyboard (3).sch]
2021-10-05 replaced controller with ATMEGA32U4
    [custom_keyboard (2).sch]
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2021-10-06 Assigned footprints to symbols
    [custom_keyboard (2).sch]
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2021-10-06 Keyboard diodes in place
    [custom_keyboard (2).kicad_pcb]
2021-10-06 Routed rows and some columns
    [custom_keyboard (2).kicad_pcb, custom_keyboard (2).sch]
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2021-10-07 Reannotated the keyboard and LED matrices
    [custom_keyboard (3).sch]
2021-10-07 Created pcb and mapped keyboard matrix
    [custom_keyboard (3).kicad_pcb, custom_keyboard (3).sch]
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2021-10-08 Placed some of the LEDs
    [custom_keyboard (3).kicad_pcb, custom_keyboard (3).sch]
2021-10-08 New version with combined footprint
    [custom_keyboard (3).kicad_pcb, custom_keyboard (3).sch, custom_keyboard (4).kicad_pcb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]
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2021-10-08 Routed everything regarding the USB hub
    [custom_keyboard (4).kicad_pcb, custom_keyboard (4).sch]
2021-10-08 Connected 5V to USB hub
    [custom_keyboard (4).kicad_pcb]
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2021-10-09 Placed microcontroller components in position
    [custom_keyboard (4).kicad_pcb, custom_keyboard (4).sch]
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2021-10-09 Mapped rows to microcontroller
    [custom_keyboard (4).kicad_pcb, custom_keyboard (4).sch]
2021-10-09 Mapped columns to microcontroller
    [custom_keyboard (4).kicad_pcb, custom_keyboard (4).sch]
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2021-10-09 Fixed row routing
    [custom_keyboard (4).kicad_pcb]
2021-10-09 Moved previous drafts to archive
    [custom_keyboard (1).sch, custom_keyboard (2).kicad_pcb, custom_keyboard (2).sch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]
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2021-10-11 Gerber files for the first draft
    [custom_keyboard-B_Cu.gbl, custom_keyboard-B_Mask.gbs, custom_keyboard-B_Paste.gbp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]
2021-10-12 Draft 1-1 with different components
    [custom_keyboard-B_Cu.gbl, custom_keyboard-B_Mask.gbs, custom_keyboard-B_Paste.gbp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]
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2021-10-12 Routed GND to crystal
    [custom_keyboard.kicad_pcb]
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2021-10-17 Made tweaks to layout
    [custom_keyboard (f303, fe2.1).kicad_pcb]
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2021-10-19 Drew outlines for case
    [custom_keyboard (f303, fe2.1).kicad_pcb, custom_keyboard (f303, fe2.1).sch]
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2021-10-19 Moved microcontroller and side USBs
    [custom_keyboard (f303, fe2.1).kicad_pcb, custom_keyboard (f303, fe2.1).sch]
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2021-10-20 Made some traces shorter
    [custom_keyboard (f303, fe2.1).kicad_pcb]
2021-10-20 Tidied up some traces
    [custom_keyboard (f303, fe2.1).kicad_pcb]
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2021-10-21 Added a ferrite bead
    [custom_keyboard (f303, fe2.1).kicad_pcb, custom_keyboard (f303, fe2.1).sch, custom_keyboard_bom.csv]
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2021-10-24 Fixed JLCPCB BOM file not generating
    [custom_keyboard (f303, fe2.1).sch]
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2021-10-25 Addressed several issues with power
    - Rearranged downstream ports so that the fuse is positioned better
    - Added ferrite beads to downstream ports
    - Added fuse to LED matrix
    [custom_keyboard (f303, fe2.1).kicad_pcb, custom_keyboard (f303, fe2.1).sch]
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2021-10-27 Exported draft for 2021-10-26 for review and cost check
    [custom_keyboard (f303, fe2.1)-B_Cu.gbl, custom_keyboard (f303, fe2.1)-B_Mask.gbs, custom_keyboard (f303, fe2.1)-B_Paste.gbp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]
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2021-10-28 Reassigned pins on microcontroller
    - they were all completely incorrect
    [custom_keyboard (f303, fe2.1).kicad_pcb, custom_keyboard (f303, fe2.1).sch]
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2021-10-30 Changed USB test pads to pad style, moved resistors
    [custom_keyboard (f103)-bottom-pos.csv, custom_keyboard (f103, fe2.1)-B_Cu.gbl, custom_keyboard (f103, fe2.1)-B_Mask.gbs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]
2021-11-01 Changed reset circuit
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2021-11-01 Changes to F303 schematic and PCB before switch to F103
    [custom_keyboard (f303, fe2.1).kicad_pcb, custom_keyboard (f303, fe2.1).sch]
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2021-11-03 Renamed test points, fixed DRC errors
    [custom_keyboard (f103, fe2.1).kicad_pcb, custom_keyboard (f103, fe2.1).sch]
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2021-11-05 Draft 1-5 with MCU swapped with F303
    [custom_keyboard (f103, fe2.1)-B_Cu.gbl, custom_keyboard (f103, fe2.1)-B_Mask.gbs, custom_keyboard (f103, fe2.1)-B_Paste.gbp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]
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2021-11-05 Created copy with F303, restored original to F103
    [custom_keyboard (f103, fe2.1).kicad_pcb, custom_keyboard (f103, fe2.1).sch, custom_keyboard (f303).kicad_pcb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]
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2021-11-09 (not in 1st proto) Fixed rotary encoder locations
    [custom_keyboard (f303).kicad_pcb]
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2021-12-06 Replaced keyboard matrix schematic
    [custom_keyboard (f303).kicad_pcb, custom_keyboard (f303).sch]
2021-12-06 Fixed issues with matrix
    [custom_keyboard (f303).kicad_pcb, custom_keyboard (f303).sch]
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2021-12-09 Replaced KEYBOARD_5V with VCC
    [custom_keyboard (f303).kicad_pcb, custom_keyboard (f303).sch]
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2021-12-15 Replaced footprints
    [custom_keyboard (f303).kicad_pcb, custom_keyboard (f303).sch]
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2021-12-20 Gave JST connector its own fuse and ferrite bead
    [custom_keyboard (f303).kicad_pcb, custom_keyboard (f303).sch]
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2021-12-23 Added the Kailh hotswap socket 3d model
    from https://github.com/qmk/qmk_hardware/tree/master/components
    [custom_keyboard (f303).kicad_pcb, custom_keyboard (f303).sch]
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2021-12-25 Mirrored XCB blocks on Y axis on RGB matrix
    [custom_keyboard (f303).sch]
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2022-01-09 Added a lot of flex cuts
    [custom_keyboard plate v2-B_Cu.gbl, custom_keyboard plate v2-B_Mask.gbs, custom_keyboard plate v2-B_Paste.gbp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]
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2022-02-06 Swapped switch footprints with anti shear footprints
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2022-02-21 Reassigned bottom rows (no longer compatible with p2)
    [keyboard0.kicad_sch]
2022-02-21 Flipped enter stabilizer
    [keyboard0.kicad_sch]
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2022-03-06 fixed tolerances
    [custom_keyboard plate v3 bottom.kicad_pcb, custom_keyboard plate v3 bottom.step]
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2022-03-06 Fixed map variant issues
    [custom_keyboard plate v3 bottom - map-B_Cu.gbl, custom_keyboard plate v3 bottom - map-B_Mask.gbs, custom_keyboard plate v3 bottom - map-B_Paste.gbp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]
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2022-03-06 keyboard0 p2 rev 2 (2.1)
    - Changed hotswaps to antishear
    - Added ESD onto JST
    - USB footprint to default footprint
    - Added EVQWGD001
    - Force stepped caps
    - Rotated some stabilizers
    [keyboard0.kicad_sch]
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2022-03-13 Fixed overlapping lines
    [Layers 1-4 combined.dxf, Layers 5-6 combined.dxf, Layers 5-6.dxf]
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

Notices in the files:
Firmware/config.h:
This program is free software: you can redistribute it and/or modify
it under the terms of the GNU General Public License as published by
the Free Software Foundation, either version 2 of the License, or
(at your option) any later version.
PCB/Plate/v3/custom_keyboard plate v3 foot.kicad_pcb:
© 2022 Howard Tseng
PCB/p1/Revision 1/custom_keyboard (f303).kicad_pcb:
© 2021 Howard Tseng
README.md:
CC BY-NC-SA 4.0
